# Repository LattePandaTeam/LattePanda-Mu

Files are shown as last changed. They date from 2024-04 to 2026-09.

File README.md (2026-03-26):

# LattePanda Mu Carrier Development Resources

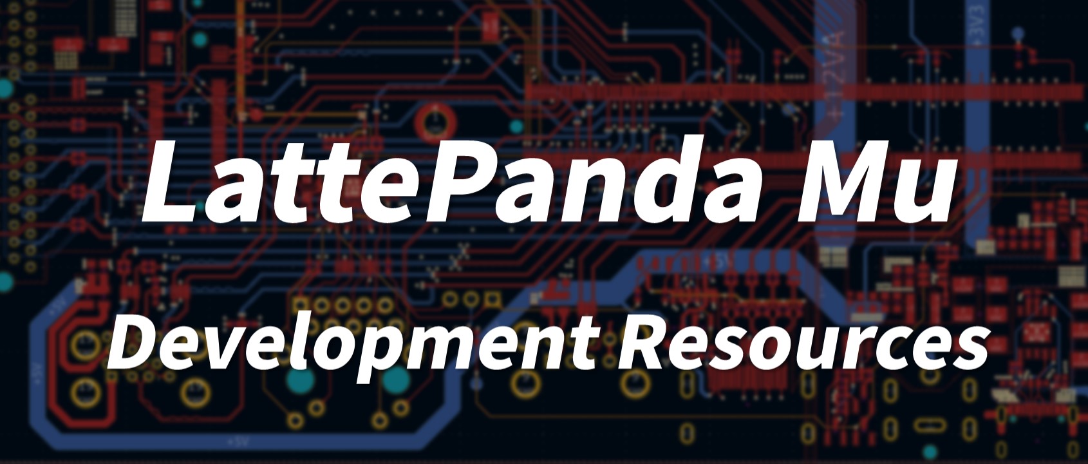
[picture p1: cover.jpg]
cover


Welcome to the repository of development resources for the LattePanda Mu. With its extensive array of interfaces, you can craft your very own carrier board. While we have provided several reference designs to spark your creativity, a myriad of exciting possibilities awaits your discovery. This repository will be continuously updated to support the development of your personalized carrier board solutions.

## Documentation

- [**LattePanda Mu Compute Module User Guide**](https://docs.lattepanda.com/content/mu_edition/introduction/)

- [**Carrier Board Hardware Design Guide**](https://docs.lattepanda.com/content/mu_edition/design_guide_foreword/)

- [**Carrier Board User Guide**](https://docs.lattepanda.com/content/mu_edition/lite_carrier/)

- [**LattePanda Website**](https://www.lattepanda.com/)

- [**Join our Discord**](https://discord.gg/RkSvc9g7eU)

## Resource Directory

- **Electricals**: This includes pin descriptions, symbols and footprint libraries, project templates, and example projects.

- **Mechanicals**: This section provides dimensional drawings and 3D models of the LattePanda Mu, its heatsink, and other accessories.

- **Software**: BIOS, firmware, drivers, and other related software resources.

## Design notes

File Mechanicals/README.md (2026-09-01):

# Mechanical Files

Includes 2D drawings and 3D models of the LattePanda Mu compute module, related accessories, and official carrier boards for structural design purposes.

The STEP format models are large in size, hence they are compressed using 7-Zip. Please use [7-Zip](https://www.7-zip.org/) or another compatible software to extract the `.7z` files before use.

## Files

- [**LattePanda_Mu_Dimension_Drawing.pdf**](./LattePanda_Mu_Dimension_Drawing.pdf): LattePanda Mu Dimensional Drawing, PDF format

- [**LattePanda_Mu_Dimension_Drawing.dxf**](./LattePanda_Mu_Dimension_Drawing.dxf): LattePanda Mu Dimensional Drawing, DXF format

- [**LattePanda_Mu.step.7z**](./LattePanda_Mu.step.7z): Contains the 3D model of the LattePanda Mu assembled with an active cooler.

- [**LattePanda_Mu_H8.0_Horizontal.step.7z**](./LattePanda_Mu_H8.0_Horizontal.step.7z): Includes the model of LattePanda Mu and the H8.0 horizontal connector, which is the standard mounting method for LattePanda Mu, and can be used directly in PCB design as an enclosure model.

- [**LattePanda_Mu_H4.0_Horizontal.step.7z**](./LattePanda_Mu_H4.0_Horizontal.step.7z): Includes the model of LattePanda Mu and the H4.0 horizontal connector, and can be used directly in PCB design as an enclosure model.

- [**FIT0982-Thin-Heatsink.step.7z**](./FIT0982-Thin-Heatsink.step.7z): Thin heatsink only, without Mu module.

- [**FIT0989-Fanless-Heatsink.step.7z**](./FIT0989-Fanless-Heatsink.step.7z): Fanless heatsink only, without Mu module.

- [**FIT0981_Active_cooler.STEP**](./FIT0981_Active_cooler.STEP): Active cooler only, without Mu module.

- [**Carrier-Boards**](./Carrier-Boards/): Mechanical files for various official carrier boards.

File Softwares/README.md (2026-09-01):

# Software Resources

Within this repository, you will find a range of software resources specifically related to the LattePanda Mu, including BIOS updates, firmware, and a variety of drivers.

For BIOS firmware specific to carrier boards, refer to the respective carrier board documentation or [carrier-board branch](./BIOS/Carrier-Boards) for more details.

## Resource Categories

- **BIOS**: Contains stable and beta BIOS updates officially supported, as well as related tools.

- **Drivers**: Drivers and related descriptions.

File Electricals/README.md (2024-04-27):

# Electronic Design Resources

## Files

- Examples: Sample projects

- Libraries: Symbol and footprint libraries for LattePanda Mu

- Pinouts: All pin definitions for LattePanda Mu

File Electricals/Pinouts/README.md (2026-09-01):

# Pinouts

All pin definitions for LattePanda Mu(N100/N305 Processor).

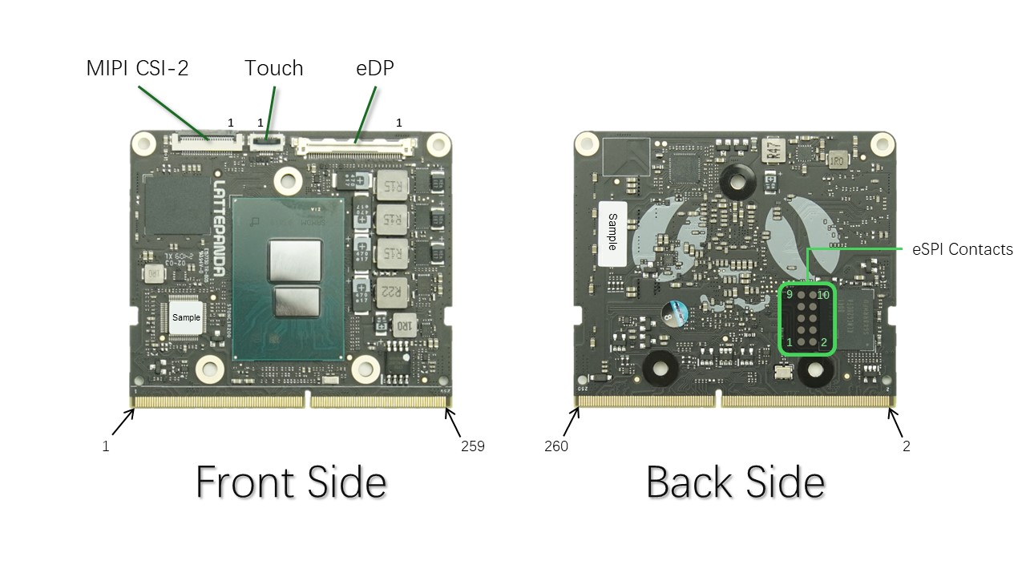
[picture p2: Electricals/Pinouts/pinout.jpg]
pinout


## Edge Connector Pinout

The edge_connector of LattePanda Mu is designed for DDR4 260P SODIMM. But this pin table is too long, so we put it in a separate .xlsx file.

- [LattePanda Mu Edge Connector Pinout](./LattePanda_Mu_Edge_Connector_Pinout.xlsx)

⚠️ Note:  
Due to the large number of functionally multiplexing pins, you should check the [BIOS functionality documentation](../../Softwares/BIOS/) before starting your design. Do not design directly from the pin definition documentation here.

## Edge Connector Pinout Comparison

LattePanda Mu and LattePanda Mu Ultra use the same edge connector, but their pin definitions are slightly different.

To facilitate your comparison and evaluation, we have provided a pin comparison document for both models.

- [LattePanda_Mu_and_Mu_Ultra_Pinout_Comparison](https://github.com/LattePandaTeam/LattePanda-Mu-Ultra/tree/main/Electricals/Pinouts/LattePanda_Mu_and_Mu_Ultra_Pinout_Comparison.xlsx)

## eDP

I-PEX 20455-040E

| Number | Name | Type | Description | Note |
|---|---|:----:|---|---|
| 1 | NC | | | |
| 2 | GND | | | |
| 3 | DDIA_TX3- | O | Lane 3 (-) | |
| 4 | DDIA_TX3+ | O | Lane 3 (+) | |
| 5 | GND | | | |
| 6 | DDIA_TX2- | O | Lane 2 (-) | |
| 7 | DDIA_TX2+ | O | Lane 2 (+) | |
| 8 | GND | | | |
| 9 | DDIA_TX1- | O | Lane 1 (-) | |
| 10 | DDIA_TX1+ | O | Lane 1 (+) | |
| 11 | GND | | | |
| 12 | DDIA_TX0- | O | Lane 0 (-) | |
| 13 | DDIA_TX0+ | O | Lane 0 (+) | |
| 14 | GND | | | |
| 15 | DDIA_AUX+ | O | Auxiliary channel (+) | |
| 16 | DDIA_AUX- | O | Auxiliary channel (-) | |
| 17 | GND | | | |
| 18 | LCD_VCC | | LCD Power Supplies | |
| 19 | LCD_VCC | | LCD Power Supplies | |
| 20 | LCD_VCC | | LCD Power Supplies | |
| 21 | LCD_VCC | | LCD Power Supplies | |
| 22 | Selftest  | O | Default Grounding | |
| 23 | GND | | | |
| 24 | GND | | | |
| 25 | GND | | | |
| 26 | GND | | | |
| 27 | HPD | I | Plug Detection | SoC GPP_E14 |
| 28 | GND | | | |
| 29 | GND | | | |
| 30 | GND | | | |
| 31 | GND | | | |
| 32 | BL_EN | O | Backlight enable | SoC eDP_BKLTEN  |
| 33 | BL_PWM | O | Backlight PWM dimming | SoC eDP_BKLTCTL |
| 34 | NC | | | |
| 35 | NC | | | |
| 36 | BL_PWR | | Backlight Power Supplies | |
| 37 | BL_PWR | | Backlight Power Supplies | |
| 38 | BL_PWR | | Backlight Power Supplies | |
| 39 | BL_PWR | | Backlight Power Supplies | |
| 40 | NC | | | |

- **LCD_VCC**: +3.3V
- **BL_PWR**: Same as LattePanda Mu's power input voltage
- **Selftest**: Factory test pin, ground by default

## Touch

Clamshell 6P 0.5mm FFC/FPC Connector

| Number | Name | Type | Description | Note |
|---|---|:----:|---|---|
| 1 | I2C0_SCL | O | I2C Bus | SoC GPP_H5  |
| 2 | I2C0_SDA | I/O  | I2C Bus | SoC GPP_H4  |
| 3 | GND | | | |
| 4 | TOUCH_RST# | O | Touch panel reset | SoC GPP_E13 |
| 5 | TOUCH_INT  | I | Touch event interrupt | SoC GPP_E17 |
| 6 | +3.3V | | Touch panel power | |

## MIPI CSI-2

Clamshell 22P 0.5mm FFC/FPC Connector

| Number | Name | Type | Description | Note |
|---|---|:----:|---|---|
| 1 | GND | | | |
| 2 | CSI_B_D0- | I | MIPI Data Lane 0  | |
| 3 | CSI_B_D0+ | I | MIPI Data Lane 0  | |
| 4 | GND | | | |
| 5 | CSI_B_D1- | I | MIPI Data Lane 1  | |
| 6 | CSI_B_D1+ | I | MIPI Data Lane 1  | |
| 7 | GND | | | |
| 8 | CSI_B_CK- | I | MIPI Clock | |
| 9 | CSI_B_CK+ | I | MIPI Clock | |
| 10 | GND | | | |
| 11 | CSI_B_D2- | I | MIPI Data Lane 2  | |
| 12 | CSI_B_D2+ | I | MIPI Data Lane 2  | |
| 13 | GND | | | |
| 14 | CSI_B_D3- | I | MIPI Data Lane 3  | |
| 15 | CSI_B_D3+ | I | MIPI Data Lane 3  | |
| 16 | GND | | | |
| 17 | CAM_RST | O | Camera reset | SoC GPP_A21 |
| 18 | CAM_MCLK  | O | Camera main clock | SoC GPP_D4  |
| 19 | GND | | | |
| 20 | I2C1_SCL  | O | I2C bus | SoC GPP_H7  |
| 21 | I2C1_SDA  | I/O  | I2C bus | SoC GPP_H6  |
| 22 | +3.3V | | Camera power | |

## eSPI Contacts

2.54mm Pitch Contacts

| Name | PIN | PIN | Name |
|---|:---:|:---:|---|
| ESPI_IO0 | 9 | 10  | GND |
| ESPI_IO1 | 7 | 8 | NC |
| ESPI_IO2 | 5 | 6 | ESPI_RESET# |
| ESPI_IO3 | 3 | 4 | ESPI_CS0# |
| ESPI_CLK | 1 | 2 | +1.8V |

Contacts on eSPI bus for SoC to communicate with SuperIO, can be used to connect diagnostic card (untested).

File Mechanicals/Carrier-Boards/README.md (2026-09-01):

# Mechanical Files for Various Carrier Boards

Drawings and models of various official carrier boards for structural design use.

## Files

- [**DFR1141_Full_EVA_Carrier_Board_for_LattePanda_Mu.zip**](./DFR1141_Full_EVA_Carrier_Board_for_LattePanda_Mu.zip) 3D model of DFR1141 Full EVA Carrier Board, STEP format, without Mu module.
- [**DFR1142_Lite_Carrier_for_LattePanda Mu(V2.0.1).zip**](./DFR1142_Lite_Carrier_for_LattePanda_Mu(V2.0.1).zip): 3D model of DFR1142 Lite Carrier Board V2, STEP format, without Mu module.
- [**DFR1293_Mini_Carrier_Board_for_LattePanda_Mu_and_Mu_Ultra.zip**](./DFR1293_Mini_Carrier_Board_for_LattePanda_Mu_and_Mu_Ultra.zip)  Contains dimension drawings (PDF and DXF formats) and a 3D model (STEP format) of the DFR1293 Mini Carrier Board, without the Mu/Mu Ultra module.

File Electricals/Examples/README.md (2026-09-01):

# Carrier Board Sample Projects

LattePanda Mu carrier board sample projects for engineers' reference, designed with KiCAD. Please open with KiCAD version 9.0 or higher.

It's recommended to start your design  by referring to the *\[DFR1142\] Lite Carrier for LattePanda Mu(V2)*.

- [Carrier Board Design Guide for LattePanda Mu](https://docs.lattepanda.com/content/mu_edition/design_guide_foreword/)

## Project Files

- **\[DFR1141\] Full EVA Carrier for LattePanda Mu**: The evaluation carrier board that includes nearly all features of the LattePanda Mu, designed to ITX motherboard dimensions, suitable for professional developers.

- **\[DFR1142\] Lite Carrier for LattePanda Mu**: The lite carrier board that includes essential interfaces such as HDMI, USB, PCIe, designed to 3.5-inch embedded motherboard dimensions.

- **\[DFR1142\] Lite Carrier for LattePanda Mu(V2)**: The upgraded version of DFR1142 Lite Carrier. Optimized for evaluation use and small-batch deployment.
  - **Auto Power-On Support:** The system can boots automatically upon receiving power.
  - **New MX1.25-10P Connector:** Designed for compatibility with the DFR1247 LattePanda Smart UPS expansion board.
  - **Side-Mounted Buttons:** Power and Reset buttons have been changed to a side-mounted vertical design to accommodate protective cases better.
  - **External Control Headers:** Added pin headers for external power control and status indication.
  - **Sleep Indicator:** Added a dedicated LED for sleep mode status.
  - **BIOS Flash Chip Footprint:** Added a footprint for a carrier board BIOS flash chip (not soldered by default) for advanced customization.

- **\[DFR1144\] GPU Carrier for LattePanda Mu**: The GPU carrier board features six video output ports, supports Type A/B MXM standard graphics cards, and adopts the 3.5-inch embedded motherboard form factor. It is suitable for local AI inference or multi-screen display matrix applications.

- **\[DFR1293\] Mini Carrier for LattePanda Mu \\ Mu Ultra**: a compact, highly expandable carrier board compatible with the LattePanda Mu and LattePanda Mu Ultra compute module. It integrates commonly used ports such as two full-featured Type-C, 2.5G Ethernet, USB 3.2 Gen2, OCuLink, M.2 M Key, M.2 E Key, HDMI, and GPIO. 

## Compatibility List

Compatibility varies between different compute modules and different carrier boards. Please visit the [**Carrier Board Docs**](https://docs.lattepanda.com/content/mu_edition/module_carrier_compatibility/) for the compatibility list.

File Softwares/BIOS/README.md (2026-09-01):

# BIOS

This repository includes official releases and beta versions of BIOS for various branches, as well as related tools.

- ⚠ Generally, you should only upgrade the BIOS of the same branch. Cross-branch upgrades should only be performed when testing different BIOS features.
- ⚠ Upgrading the BIOS across different branches may invalidate the Secure Boot keys.
- ⚠ Upgrading to the incorrect BIOS branch may result in some functions of the carrier board not working properly.
- ⚠ BIOS files under `Carrier-Boards` are designed exclusively for the specific carrier boards. Do NOT flash them onto a LattePanda Mu paired with any other carrier board or no carrier board.

------

## Naming Rule

### New Naming Scheme (2025-12 and later)

**Format**
`S70NC1R200-[Memory]-[Version][-Variant].bin`

- **S70NC1R200**: Platform identifier (LattePanda Mu N100/N305)
- **Memory**:
  - `8G` = 8GB RAM
  - `16G` = 16GB RAM
- **Version**:
  - `A`, `B`, `C`... (incremented alphabetically for each new release)
- **Variant** (optional):
  - *(no suffix)* = Default (PCIe)
  - `SATA` = SATA branch

**Examples**

- `S70NC1R200-8G-A.bin` → 8GB, Default (PCIe)
- `S70NC1R200-16G-A-SATA.bin` → 16GB, SATA

**Notes**

- New scheme is simplified and user-oriented.
- **All subsequent updates will follow this naming convention.**

### Legacy Naming Scheme (2024 Initial Release)

**Format**
`LP-BS-S70NC1R200-[Rank]-[Version][-Variant].bin`

- **LP**: LattePanda
- **BS**: BIOS
- **S70NC1R200**: Platform identifier(LattePanda Mu N100/N305)
- **Rank**:
  - `SR` = Single Rank (corresponds to 8GB models)
  - `DR` = Dual Rank (corresponds to 16GB models)
- **Version**:
  - `A`, `B`
- **Variant**:
  - *(no suffix)* = Default (PCIe)
  - `SATA` = SATA branch

**Example**

- `LP-BS-S70NC1R200-SR-B.bin` → 8GB, Default (PCIe)

- `LP-BS-S70NC1R200-DR-B-SATA.bin` → 16GB, SATA

### Mapping: Legacy → New Naming

- `SR` → `8G`
- `DR` → `16G`

**Examples**

- `LP-BS-S70NC1R200-SR-B.bin` → `S70NC1R200-8G-A.bin` (newer)
- `LP-BS-S70NC1R200-DR-B-SATA.bin` → `S70NC1R200-16G-A-SATA.bin` (newer)

------

## Folder Description

- **Beta**: Beta version BIOS, not specific to any branch, intended for professional developers to assess new features.
- **DFLT**: Default version BIOS, which is the BIOS branch that comes pre-installed on the LattePanda Mu.
- **SATA**: A BIOS branch that provides SATA interface signal.
- **Carrier-Boards**: BIOS branches dedicated to specific carrier boards. Flash only the BIOS matching your carrier board.
- **Tools**: Tools for BIOS maintenance.

------

## Release Timeline

```text
    2024-06/07                  2025-12                    2026-06
        │                          │                          |
        ●──────────────────────────●──────────────────────────●
        │                          │                          |
[Initial Release]           [Second Release]          [Current Recommended]
    DFLT,SATA                  DFLT,SATA                  DFLT,SATA 
```

For specific model compatibility and functional changes, please refer to the `BOS Release Notes` located in each branch's folder.

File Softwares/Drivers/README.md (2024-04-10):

# Drivers

This repository contains only the LattePanda Mu drivers. For drivers related to the carrier board, please refer to the carrier board documentation.

## Windows 10/11

After installing Windows, the system will automatically connect to the internet to download driver updates. If it is unable to access the Windows Update service, or if there are missing drivers after the automatic updates, you can download the offline driver package here.

| Name | Version | Size | Download |
|---|---|---|---|
| Intel Chipset Driver | 10.1.19376.8374 | 2.72 MB | [⬇️](./Chipset_10.1.19376.8374.zip) |
| Intel Iris Xe Graphics Driver | Latest | N/A | [⬇️](https://www.intel.com/content/www/us/en/download/785597/)[^1] |
| intel Serial IO Driver | 30.100.2229.4 | 353 KB  | [⬇️](./SerialIO_30.100.2229.4.zip) |
| intel HID Event Filter Driver | 2.2.1.386 | 46.6 KB | [⬇️](./HID_2.2.1.386.zip) |
| Intel Management Engine Interface Driver | 2306.4.10.0 | 20.5 MB | [⬇️](./MEI_2306.4.10.0.zip) |
| Intel GNA Scoring Accelerator Driver | 03.00.00.1457 | 54 KB | [⬇️](./GNA_03.00.00.1457.zip) |
| Intel Integrated Sensor Solution Driver | 3.1.0.4589 | 2.73 MB | [⬇️](./ISH_3.1.0.4589.zip) |
| TouchPanel Driver | 1.3.2.0 | 67.5 KB | [⬇️](./TouchPanel_1.3.2.0.zip) |

[^1]: Download from intel official website

## Linux

Linux drivers are generally provided by the distribution through kernel and kernel module updates. Please use a newer kernel version to ensure full driver support.

- Minimum kernel version: 5.18
- Recommended kernel version: 6.1 or later

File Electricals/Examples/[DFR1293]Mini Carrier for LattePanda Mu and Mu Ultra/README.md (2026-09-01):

# \[DFR1293\]Mini Carrier for LattePanda Mu and LattePanda Mu Ultra

Currently, only a PDF schematic is available for reference.

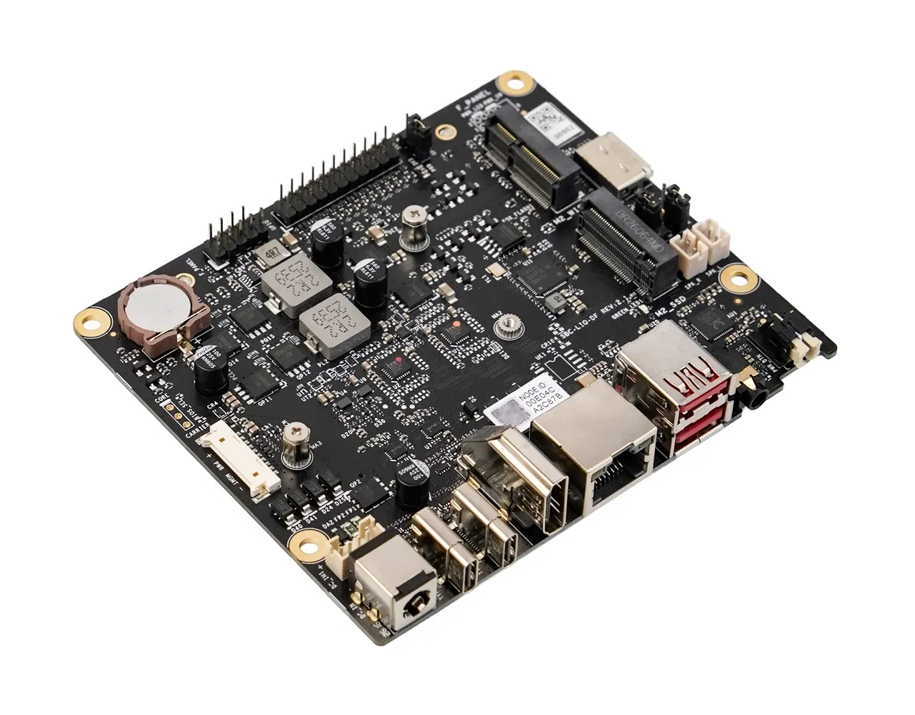
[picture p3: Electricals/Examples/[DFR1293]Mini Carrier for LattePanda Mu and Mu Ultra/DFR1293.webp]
DFR1293


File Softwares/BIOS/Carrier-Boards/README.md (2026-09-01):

# Carrier Board BIOS

This repository provides BIOS firmware specifically adapted for specific carrier boards.

- **[DFR1293] Mini-Carrier**
    - Make the LattePanda Mu compatible with the Mini Carrier.
    - The LattePanda Mu Ultra’s default firmware already works perfectly.

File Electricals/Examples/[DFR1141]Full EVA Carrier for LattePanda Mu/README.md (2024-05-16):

# \[DFR1141\]Full EVA Carrier for LattePanda Mu

Currently, only a **preview version** of the schematic and Gerber files are available for reference.

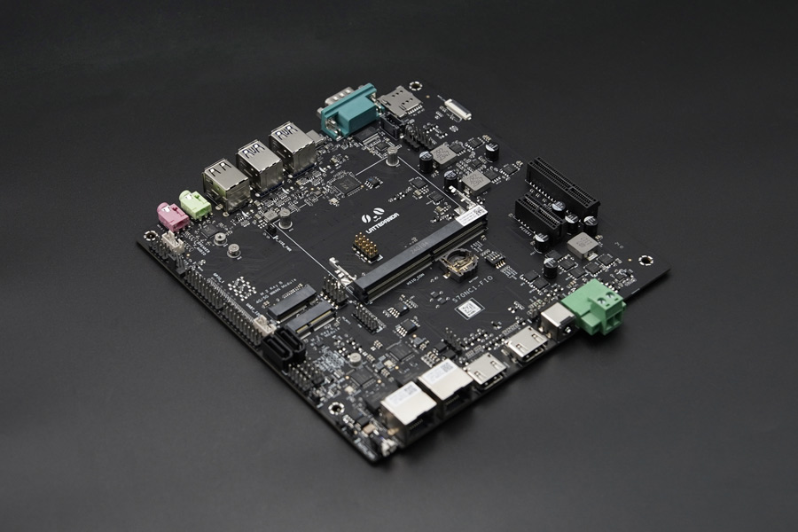
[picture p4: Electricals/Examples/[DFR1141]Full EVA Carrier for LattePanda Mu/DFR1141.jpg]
DFR1141


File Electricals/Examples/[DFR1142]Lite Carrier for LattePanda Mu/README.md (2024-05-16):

# DFR1142 Lite Carrier for LattePanda Mu

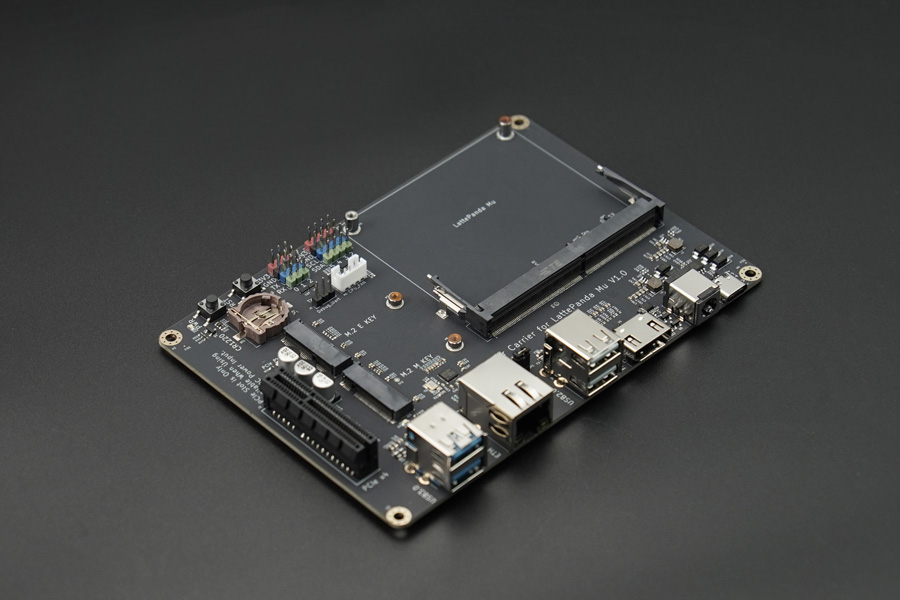
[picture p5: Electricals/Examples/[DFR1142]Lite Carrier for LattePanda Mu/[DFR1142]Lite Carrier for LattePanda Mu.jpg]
DFR1142


## Specification

### Power Input

- USB Type-C PD: 15V (Max 3A)
- DC 5.5x2.5mm: 12~20V (Max 10A)

### Internal Interfaces

- PCIe 3.0 x4 slot (only available when using 12V power supply)
- M.2 M Key 2230 (PCIe 3.0 x1)
- M.2 E Key 2230 (PCIe 3.0 x1, USB2.0)
- RTC battery socket (CR1220 3V)
- CPU fan socket
- Gravity-4P UART
- Gravity-4P I2C

### External Interfaces

- USB 3.2 10Gbps x2
- Gigabit Ethernet
- USB 2.0 x2
- HDMI 2.0

### Dimension

3.5 inches, 146mm×102mm

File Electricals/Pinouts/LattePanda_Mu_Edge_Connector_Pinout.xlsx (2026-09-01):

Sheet: Overview
Speed: Indicates the operating speed of the signal pin. "Low" denotes low-speed signals requiring only standard PCB routing. "High" denotes high-speed signals which mandate impedance matching in the PCB design.
IO Level: For multiplexed pins, the IO voltage level may vary depending on the configured function. This document specifies the maximum voltage level supported by the pin.
Note:
This document is applicable only to LattePanda Mu compute modules equipped with Intel N100 and N305 processors.
Due to the large number of pins that serve multiple functions, please consult the BIOS functionality documentation before beginning your design.
https://github.com/LattePandaTeam/LattePanda-Mu/tree/main/Softwares/BIOS
Pinout Description Page
https://github.com/LattePandaTeam/LattePanda-Mu/tree/main/Electricals/Pinouts

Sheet: Front
Pin | Signal Name | Direction | IO Level | Description | Speed | Notes
1 | PWR_SW# | I | 3.3V | System Power Switch | Low | Active LOW; Internally 10K Pulled Up
3 | RST_SW# | I | 3.3V | System Reset Switch | Low | Active LOW; Internally 10K Pulled Up
5 | PSON | O | 3.3V | System Power Supply Status | Low | Output HIGH only when S0(Working); 10K Pull-up to 3.3V (Weak Drive of HIGH output)
7 | SLP_S4 | O | 3.3V | System Status | Low | Output HIGH only when S0(Working) and S3(Sleeping)
9 | TSENSE | I | 3.3V | NTC Temperature Sensor | Low
11 | GND | PWR | 0V | Ground | /
13 | HSIO0_TX_P | O | 0.8V | HSIO0 TX Differential Pair | High | External AC Coupling Capacitor Required
15 | HSIO0_TX_N | O | 0.8V | HSIO0 TX Differential Pair | High | External AC Coupling Capacitor Required
17 | GND | PWR | 0V | Ground | /
19 | HSIO1_TX_P | O | 0.8V | HSIO1 TX Differential Pair | High | External AC Coupling Capacitor Required
21 | HSIO1_TX_N | O | 0.8V | HSIO1 TX Differential Pair | High | External AC Coupling Capacitor Required
23 | GND | PWR | 0V | Ground | /
25 | HSIO2_TX_P | O | 0.8V | HSIO2 TX Differential Pair | High | External AC Coupling Capacitor Required
27 | HSIO2_TX_N | O | 0.8V | HSIO2 TX Differential Pair | High | External AC Coupling Capacitor Required
29 | GND | PWR | 0V | Ground | /
31 | HSIO3_TX_P | O | 0.8V | HSIO3 TX Differential Pair | High | External AC Coupling Capacitor Required
33 | HSIO3_TX_N | O | 0.8V | HSIO3 TX Differential Pair | High | External AC Coupling Capacitor Required
35 | GND | PWR | 0V | Ground | /
37 | HSIO8_TX_P | O | 0.8V | HSIO8 TX Differential Pair | High | External AC Coupling Capacitor Required
39 | HSIO8_TX_N | O | 0.8V | HSIO8 TX Differential Pair | High | External AC Coupling Capacitor Required
41 | GND | PWR | 0V | Ground | /
43 | HSIO9_TX_P | O | 0.8V | HSIO9 TX Differential Pair | High | External AC Coupling Capacitor Required
45 | HSIO9_TX_N | O | 0.8V | HSIO9 TX Differential Pair | High | External AC Coupling Capacitor Required
47 | GND | PWR | 0V | Ground | /
49 | HSIO10_TX_P | O | 0.8V | HSIO10 TX Differential Pair | High | External AC Coupling Capacitor Required
51 | HSIO10_TX_N | O | 0.8V | HSIO10 TX Differential Pair | High | External AC Coupling Capacitor Required
53 | GND | PWR | 0V | Ground | /
55 | HSIO11_TX_P | O | 0.8V | HSIO11 TX Differential Pair | High | External AC Coupling Capacitor Required
57 | HSIO11_TX_N | O | 0.8V | HSIO11 TX Differential Pair | High | External AC Coupling Capacitor Required
59 | GND | PWR | 0V | Ground | /
61 | HSIO6_TX_P | O | 0.8V | HSIO6 TX Differential Pair | High | External AC Coupling Capacitor Required
63 | HSIO6_TX_N | O | 0.8V | HSIO6 TX Differential Pair | High | External AC Coupling Capacitor Required
65 | GND | PWR | 0V | Ground | /
67 | USB2_P1_N | I/O | 3.3V | USB 2.0 Port 1 Differential Pair | High
69 | USB2_P1_P | I/O | 3.3V | USB 2.0 Port 1 Differential Pair | High
71 | GND | PWR | 0V | Ground | /
73 | USB2_P2_N | I/O | 3.3V | USB 2.0 Port 2 Differential Pair | High
75 | USB2_P2_P | I/O | 3.3V | USB 2.0 Port 2 Differential Pair | High
77 | GND | PWR | 0V | Ground | /
79 | USB2_P3_N | I/O | 3.3V | USB 2.0 Port 3 Differential Pair | High
81 | USB2_P3_P | I/O | 3.3V | USB 2.0 Port 3 Differential Pair | High
83 | GND | PWR | 0V | Ground | /
85 | REFCLK0_P | O | 0.8V | PCIe Reference Clock 0 Differential Pair | High | 100MHz
87 | REFCLK0_N | O | 0.8V | PCIe Reference Clock 0 Differential Pair | High | 100MHz
89 | GND | PWR | 0V | Ground | /
91 | REFCLK1_P | O | 0.8V | PCIe Reference Clock 1 Differential Pair | High | 100MHz
93 | REFCLK1_N | O | 0.8V | PCIe Reference Clock 1 Differential Pair | High | 100MHz
95 | GND | PWR | 0V | Ground | /
97 | REFCLK2_P | O | 0.8V | PCIe Reference Clock 2 Differential Pair | High | 100MHz
99 | REFCLK2_N | O | 0.8V | PCIe Reference Clock 2 Differential Pair | High | 100MHz
101 | GND | PWR | 0V | Ground | /
103 | PCIE_WAKE# | I | 3.3V | PCIe Wake Request | Low | Pulled LOW to Wake System; Internally 1K Pulled Up
105 | PLT_RST# | O | 3.3V | Platform Reset for PCIe | Low | Output LOW to Reset PCIe Device
107 | GND | PWR | 0V | Ground | /
109 | USB2_P5_N | I/O | 3.3V | USB 2.0 Port 5 Differential Pair | High
111 | USB2_P5_P | I/O | 3.3V | USB 2.0 Port 5 Differential Pair | High
113 | GND | PWR | 0V | Ground | /
115 | VBAT | PWR | 3.0V | RTC Battery Input | /
117 | PROCHOT# | I | 3.3V | (TCC) Overheat Protect | Low | Active LOW; Internally 10K Pulled Up
119 | GPP_E0 | I/O | 3.3V | GPIO | Low | BIOS Default Function:WWAN_PWR_EN
121 | GPP_A12 | I/O | 3.3V | GPIO | Low | BIOS Default Function:CAM_PWR_EN
123 | SATA_LED# | O | 3.3V | SATA HDD Activity Status | Low | Active LOW
125 | PMCALERT# | I | 3.3V | USB Type-C PD Controller / Re-timer Alert | Low | Active LOW; Internally 10K Pulled Up
127 | TPM_IRQ | I | 3.3V | Discrete TPM Interrupt | Low
129 | USB_OC# | I | 3.3V | USB Over Current | Low | Active LOW; Internally 10K Pulled Up
131 | SUSCLK | O | 3.3V | Suspend Clock | Low | 32.768KHz
133 | BIOS_SEL | I | 3.3V | BIOS ROM Select | Low | Internally 100K Pulled Up； HIGH: Integrated ROM; LOW: Carrier ROM
135 | GND | PWR | 0V | Ground | /
137 | UART0_RXD / GPP_H10 | I/O | 3.3V | SoC UART0 RX / GPIO | Low | BIOS Default Function: UART
139 | UART0_TXD / GPP_H11 | I/O | 3.3V | SoC UART0 TX / GPIO | Low | BIOS Default Function: UART
141 | UART1_RXD / GPP_D17 | I/O | 3.3V | SoC UART1 RX / GPIO | Low | BIOS Default Function: UART
143 | UART1_TXD / GPP_D18 | I/O | 3.3V | SoC UART1 TX / GPIO | Low | BIOS Default Function: UART
KEY
145 | SML1_DATA | I/O | 3.3V | SMLink1 Data | Low | Internally 2.2K Pulled Up
147 | SML1_CLK | O | 3.3V | SMLink1 Clock | Low | Internally 2.2K Pulled Up
149 | SML1_ALERT# | I | 3.3V | SMLink1 Alert | Low | Active LOW
151 | GND | PWR | 0V | Ground | /
153 | SPI_IO3 | I/O | 3.3V | SPI Bus for BIOS and dTPM | Low
155 | SPI_CLK | O | 3.3V | SPI Bus for BIOS and dTPM | Low
157 | SPI_CS2# | O | 3.3V | SPI Chip Select for dTPM | Low
159 | SPI_MOSI/SPI_IO0 | I/O | 3.3V | SPI Bus for BIOS and dTPM | Low
161 | SPI_IO2 | I/O | 3.3V | SPI Bus for BIOS and dTPM | Low
163 | SPI_MISO/SPI_IO1 | I/O | 3.3V | SPI Bus for BIOS and dTPM | Low
165 | SPI_CS# | O | 3.3V | SPI Chip Select for BIOS ROM | Low
167 | GND | PWR | 0V | Ground | /
169 | DDIB_CTRL_DATA | I/O | 3.3V | DDIB Control Data | Low | Internally 2.2K Pulled Up
171 | DDIB_CTRL_CLK | O | 3.3V | DDIB Control Clock | Low | Internally 2.2K Pulled Up
173 | TCP1_CTRL_DATA | I/O | 3.3V | TCP1 Control Data | Low | Internally 2.2K Pulled Up
175 | TCP1_CTRL_CLK | O | 3.3V | TCP1 Control Clock | Low | Internally 2.2K Pulled Up
177 | TCP0_CTRL_DATA | I/O | 3.3V | TCP0 Control Data | Low | Internally 2.2K Pulled Up
179 | TCP0_CTRL_CLK | O | 3.3V | TCP0 Control Clock | Low | Internally 2.2K Pulled Up
181 | GND | PWR | 0V | Ground | /
183 | DDIB_HPD | I | 3.3V | DDIB Hot Plug Detect | Low
185 | TCP1_HPD | I | 3.3V | TCP1 Hot Plug Detect | Low
187 | TCP0_HPD | I | 3.3V | TCP0 Hot Plug Detect | Low
189 | GND | PWR | 0V | Ground | /
191 | DDIB_AUX_N | I/O | 0.6V | DDIB DP Auxiliary Channel | Low
193 | DDIB_AUX_P | I/O | 0.6V | DDIB DP Auxiliary Channel | Low
195 | GND | PWR | 0V | Ground | /
197 | DDIB_TX3_N | O | 1.2V | DDIB DP Lane 3 / HDMI TMDS Clock | High | External AC Coupling Capacitor Required
199 | DDIB_TX3_P | O | 1.2V | DDIB DP Lane 3 / HDMI TMDS Clock | High | External AC Coupling Capacitor Required
201 | GND | PWR | 0V | Ground | /
203 | DDIB_TX2_N | O | 1.2V | DDIB DP Lane 2 / HDMI TMDS Data0 | High | External AC Coupling Capacitor Required
205 | DDIB_TX2_P | O | 1.2V | DDIB DP Lane 2 / HDMI TMDS Data0 | High | External AC Coupling Capacitor Required
207 | GND | PWR | 0V | Ground | /
209 | DDIB_TX1_N | O | 1.2V | DDIB DP Lane 1 / HDMI TMDS Data1 | High | External AC Coupling Capacitor Required
211 | DDIB_TX1_P | O | 1.2V | DDIB DP Lane 1 / HDMI TMDS Data1 | High | External AC Coupling Capacitor Required
213 | GND | PWR | 0V | Ground | /
215 | DDIB_TX0_N | O | 1.2V | DDIB DP Lane 0 / HDMI TMDS Data2 | High | External AC Coupling Capacitor Required
217 | DDIB_TX0_P | O | 1.2V | DDIB DP Lane 0 / HDMI TMDS Data2 | High | External AC Coupling Capacitor Required
219 | GND | PWR | 0V | Ground | /
221 | TCP0_AUX_N | I/O | 0.6V | TCP0 DP Auxiliary Channel | Low
223 | TCP0_AUX_P | I/O | 0.6V | TCP0 DP Auxiliary Channel | Low
225 | GND | PWR | 0V | Ground | /
227 | TCP0_TXRX1_N | I/O | 1.2V | TCP0 DP Lane 3 / HDMI TMDS Clock / Type C RX Data Lane 2 | High | External AC Coupling Capacitor Required
229 | TCP0_TXRX1_P | I/O | 1.2V | TCP0 DP Lane 3 / HDMI TMDS Clock / Type C RX Data Lane 2 | High | External AC Coupling Capacitor Required
231 | GND | PWR | 0V | Ground | /
233 | TCP0_TX1_N | O | 1.2V | TCP0 DP Lane 2 / HDMI TMDS Data0 / Type C TX Data Lane 2 | High | External AC Coupling Capacitor Required
235 | TCP0_TX1_P | O | 1.2V | TCP0 DP Lane 2 / HDMI TMDS Data0 / Type C TX Data Lane 2 | High | External AC Coupling Capacitor Required
237 | GND | PWR | 0V | Ground | /
239 | TCP0_TXRX0_N | I/O | 1.2V | TCP0 DP Lane 1 / HDMI TMDS Data1 / Type C RX Data Lane 1 | High | External AC Coupling Capacitor Required
241 | TCP0_TXRX0_P | I/O | 1.2V | TCP0 DP Lane 1 / HDMI TMDS Data1 / Type C RX Data Lane 1 | High | External AC Coupling Capacitor Required
243 | GND | PWR | 0V | Ground | /
245 | TCP0_TX0_N | O | 1.2V | TCP0 DP Lane 0 / HDMI TMDS Data2 / Type C TX Data Lane 1 | High | External AC Coupling Capacitor Required
247 | TCP0_TX0_P | O | 1.2V | TCP0 DP Lane 0 / HDMI TMDS Data2 / Type C TX Data Lane 1 | High | External AC Coupling Capacitor Required
249 | GND | PWR | 0V | Ground | /
251 | VIN | PWR | 9V ~ 20V | Main Power Input | /
253 | VIN | PWR | 9V ~ 20V | Main Power Input | /
255 | VIN | PWR | 9V ~ 20V | Main Power Input | /
257 | VIN | PWR | 9V ~ 20V | Main Power Input | /
259 | VIN | PWR | 9V ~ 20V | Main Power Input | /
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

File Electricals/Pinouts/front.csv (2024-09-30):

Number | Name | Type | Description | Note
1 | PWRBTN# | I | Power button, with integrated pull-up | SIO PANSWH#
3 | RSTBTN# | I | Reset button, with integrated pull-up | SoC SYS_RESET#
5 | SLS_S0 | O | Power status, output high when S0(Working) | SIO PSON#
7 | SLS_S3 | O | Power status, output high when S0(Working), S3(Sleep) | SoC GPD5
9 | TSENSE | I | NTC temperature sensor input | SIO TMPIN2
11 | GND
13 | HSIO0_TX+ | O | Differential signal output, coupling capacitor required
15 | HSIO0_TX- | O | Differential signal output, coupling capacitor required
17 | GND
19 | HSIO1_TX+ | O | Differential signal output, coupling capacitor required
21 | HSIO1_TX- | O | Differential signal output, coupling capacitor required
23 | GND
25 | HSIO2_TX+ | O | Differential signal output, coupling capacitor required
27 | HSIO2_TX- | O | Differential signal output, coupling capacitor required
29 | GND
31 | HSIO3_TX+ | O | Differential signal output, coupling capacitor required
33 | HSIO3_TX- | O | Differential signal output, coupling capacitor required
35 | GND
37 | HSIO8_TX+ | O | Differential signal output, coupling capacitor required
39 | HSIO8_TX- | O | Differential signal output, coupling capacitor required
41 | GND
43 | HSIO9_TX+ | O | Differential signal output, coupling capacitor required
45 | HSIO9_TX- | O | Differential signal output, coupling capacitor required
47 | GND
49 | HSIO10_TX+ | O | Differential signal output, coupling capacitor required
51 | HSIO10_TX- | O | Differential signal output, coupling capacitor required
53 | GND
55 | HSIO11_TX+ | O | Differential signal output, coupling capacitor required
57 | HSIO11_TX- | O | Differential signal output, coupling capacitor required
59 | GND
61 | HSIO6_TX+ | O | Differential signal output, coupling capacitor required
63 | HSIO6_TX- | O | Differential signal output, coupling capacitor required
65 | GND
67 | USB2_P1- | I/O | USB 2.0 differential signal
69 | USB2_P1+ | I/O | USB 2.0 differential signal
71 | GND
73 | USB2_P2- | I/O | USB 2.0 differential signal
75 | USB2_P2+ | I/O | USB 2.0 differential signal
77 | GND
79 | USB2_P3- | I/O | USB 2.0 differential signal
81 | USB2_P3+ | I/O | USB 2.0 differential signal
83 | GND
85 | REFCLK0+ | O | PCIe reference clock
87 | REFCLK0- | O | PCIe reference clock
89 | GND
91 | REFCLK1+ | O | PCIe reference clock
93 | REFCLK1- | O | PCIe reference clock
95 | GND
97 | REFCLK2+ | O | PCIe reference clock
99 | REFCLK2- | O | PCIe reference clock
101 | GND
103 | WAKE# | I | Wake Mu when pull-down | SoC WAKE#
105 | PLTRST# | O | Platform reset signal | SoC GPP_B13
107 | GND
109 | USB2_P5- | I/O | USB 2.0 differential signal
111 | USB2_P5+ | I/O | USB 2.0 differential signal
113 | GND
115 | VBAT |  | RTC battery input | SoC VCCRTC
117 | PROCHOT# | I | Overheat protect when pull-down | SoC PROCHOT#
119 | GPP_E0 | I/O | GPIO, functions defined by BIOS
121 | GPP_A12 | I/O | GPIO, functions defined by BIOS
123 | GPP_B14 | I/O | GPIO, functions defined by BIOS
125 | GPP_B11 | I/O | GPIO, functions defined by BIOS
127 | TPM_IRQ | I | discrete TPM interrupt | SoC GPP_B4
129 | USB_OC# | I | USB over current signal | SoC GPP_A16
131 | SUSCLK | O | 32.768kHz clock output | SoC GPD8
133 | BIOS_SEL# | I | BIOS select: pull-up: integrated ROM; pull-down: carrier ROM
135 | GND
137 | UART0_RXD | I | SoC UART0 receiver | SoC GPP_H10
139 | UART0_TXD | O | SoC UART0 transmitter | SoC GPP_H11
141 | UART1_RXD | I | SoC UART1 receiver | SoC GPP_D17
143 | UART1_TXD | O | SoC UART1 transmitter | SoC GPP_D18
KEY | KEY | KEY | KEY
145 | SML1_DATA | I/O | SMLink1 data | SoC GPP_C7
147 | SML1_CLK | O | SMLink1 clock | SoC GPP_C6
149 | SML1_ALERT# | I | SMLink1 alert | SoC GPP_B23
151 | GND
153 | SPI_IO3 | I/O | SPI interface, BIOS and dTPM specific
155 | SPI_CLK | O | SPI interface, BIOS and dTPM specific
157 | SPI_CS2# | O | SPI chip select, dTPM specific
159 | SPI_MOSI/SPI_IO0 | I/O | SPI interface, BIOS and dTPM specific
161 | SPI_IO2 | I/O | SPI interface, BIOS and dTPM specific
163 | SPI_MISO/SPI_IO1 | I/O | SPI interface, BIOS and dTPM specific
165 | SPI_CS# | O | SPI chip select, BIOS ROM specific
167 | GND
169 | DDIB_DDC_SDA | I/O | DDIB HDMI display data channel data | SoC GPP_H17
171 | DDIB_DDC_SCL | O | DDIB HDMI display data channel clock | SoC GPP_H15
173 | TCP1_DDC_SDA | I/O | TCP1 HDMI display data channel data | SoC GPP_E21
175 | TCP1_DDC_SCL | O | TCP1 HDMI display data channel clock | SoC GPP_E20
177 | TCP0_DDC_SDA | I/O | TCP0 HDMI display data channel data | SoC GPP_E19
179 | TCP0_DDC_SCL | O | TCP0 HDMI display data channel clock | SoC GPP_E18
181 | GND
183 | DDIB_HPD | I | DDIB hot plug detect | SoC GPP_A18
185 | TCP1_HPD | I | TCP1 hot plug detect | SoC GPP_A20
187 | TCP0_HPD | I | TCP0 hot plug detect | SoC GPP_A19
189 | GND
191 | DDIB_AUX- | I/O | DDIB DP Auxiliary channel
193 | DDIB_AUX+ | I/O | DDIB DP Auxiliary channel
195 | GND
197 | DDIB_TX3- | O | DDIB DP Lane 3/HDMI TMDS Clock
199 | DDIB_TX3+ | O | DDIB DP Lane 3/HDMI TMDS Clock
201 | GND
203 | DDIB_TX2- | O | DDIB DP Lane 2/HDMI TMDS Data0
205 | DDIB_TX2+ | O | DDIB DP Lane 2/HDMI TMDS Data0
207 | GND
209 | DDIB_TX1- | O | DDIB DP Lane 1/HDMI TMDS Data1
211 | DDIB_TX1+ | O | DDIB DP Lane 1/HDMI TMDS Data1
213 | GND
215 | DDIB_TX0- | O | DDIB DP Lane 0/HDMI TMDS Data2
217 | DDIB_TX0+ | O | DDIB DP Lane 0/HDMI TMDS Data2
219 | GND
221 | TCP0_AUX- | I/O | TCP0 DP Auxiliary channel
223 | TCP0_AUX+ | I/O | TCP0 DP Auxiliary channel
225 | GND
227 | TCP0_TXRX1- | O | TCP0 DP Lane 3/HDMI TMDS Clock
229 | TCP0_TXRX1+ | O | TCP0 DP Lane 3/HDMI TMDS Clock
231 | GND
233 | TCP0_TX1- | O | TCP0 DP Lane 2/HDMI TMDS Data0
235 | TCP0_TX1+ | O | TCP0 DP Lane 2/HDMI TMDS Data0
237 | GND
239 | TCP0_TXRX0- | O | TCP0 DP Lane 1/HDMI TMDS Data1
241 | TCP0_TXRX0+ | O | TCP0 DP Lane 1/HDMI TMDS Data1
243 | GND
245 | TCP0_TX0- | O | TCP0 DP Lane 0/HDMI TMDS Data2
247 | TCP0_TX0+ | O | TCP0 DP Lane 0/HDMI TMDS Data2
249 | GND
251 | VIN |  | Main power input 9~20V
253 | VIN |  | Main power input 9~20V
255 | VIN |  | Main power input 9~20V
257 | VIN |  | Main power input 9~20V
259 | VIN |  | Main power input 9~20V

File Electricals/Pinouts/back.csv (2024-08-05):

Number | Name | Type | Description | Note
2 | FAN1_PWM | O | CPU fan PWM output | SIO GP51
4 | FAN1_TAC | I | CPU fan tachometer input | SIO GP52
6 | TAN2_PWM | O | System fan PWM out | SIO GP36
8 | FAN2_TAC | I | System fan tachometer input | SIO GP37
10 | SIO_UART_TX | O | SuperIO UART transmitter | SIO JP3
12 | SIO_UART_RX | I | SuperIO UART receiver | SIO GP41
14 | GND
16 | HSIO0_RX+ | I | Differential signal input
18 | HSIO0_RX- | I | Differential signal input
20 | GND
22 | HSIO1_RX+ | I | Differential signal input
24 | HSIO1_RX- | I | Differential signal input
26 | GND
28 | HSIO2_RX+ | I | Differential signal input
30 | HSIO2_RX- | I | Differential signal input
32 | GND
34 | HSIO3_RX+ | I | Differential signal input
36 | HSIO3_RX- | I | Differential signal input
38 | GND
40 | HSIO8_RX+ | I | Differential signal input
42 | HSIO8_RX- | I | Differential signal input
44 | GND
46 | HSIO9_RX+ | I | Differential signal input
48 | HSIO9_RX- | I | Differential signal input
50 | GND
52 | HSIO10_RX+ | I | Differential signal input
54 | HSIO10_RX- | I | Differential signal input
56 | GND
58 | HSIO11_RX+ | I | Differential signal input
60 | HSIO11_RX- | I | Differential signal input
62 | GND
64 | HSIO6_RX+ | I | Differential signal input
66 | HSIO6_RX- | I | Differential signal input
68 | GND
70 | USB2_P4 | I/O | USB 2.0 differential signal
72 | USB2_N4 | I/O | USB 2.0 differential signal
74 | GND
76 | USB2_P7 | I/O | USB 2.0 differential signal
78 | USB2_N7 | I/O | USB 2.0 differential signal
80 | GND
82 | USB2_P8 | I/O | USB 2.0 differential signal
84 | USB2_N8 | I/O | USB 2.0 differential signal
86 | GND
88 | REFCLK3+ | O | PCIe reference clock
90 | REFCLK3- | O | PCIe reference clock
92 | GND
94 | REFCLK4+ | O | PCIe reference clock
96 | REFCLK4- | O | PCIe reference clock
98 | GND
100 | PCIECLK_REQ3# | I | REFCLK3 clock request function | SoC GPP_D8
102 | PCIECLK_REQ4# | I | REFCLK4 clock request function | SoC GPP_H19
104 | SMB_ALERT# | I | SMBus alert interrupt | SoC GPP_C2
106 | SMB_CLK | O | SMBus clock | SoC GPP_C0
108 | SMB_DATA | I/O | SMBus data | SoC GPP_C1
110 | GND
112 | USB2_P6 | I/O | USB 2.0 differential signal
114 | USB2_N6 | I/O | USB 2.0 differential signal
116 | GND
118 | GPP_F16 | I/O | GPIO, functions defined by BIOS
120 | GPP_F15 | I/O | GPIO, functions defined by BIOS
122 | GPP_F14 | I/O | GPIO, functions defined by BIOS
124 | GPP_F13 | I/O | GPIO, functions defined by BIOS
126 | GPP_F12 | I/O | GPIO, functions defined by BIOS
128 | GPP_D0 | I/O | GPIO, functions defined by BIOS
130 | GPP_D1 | I/O | GPIO, functions defined by BIOS
132 | GPP_D2 | I/O | GPIO, functions defined by BIOS
134 | GPP_D3 | I/O | GPIO, functions defined by BIOS
136 | GND
138 | SOC_UART2_TXD | O | SoC UART2 transmitter | SoC GPP_F2
140 | SOC_UART2_RXD | I | SoC UART2 receiver | SoC GPP_F1
142 | I2C5_SCL | O | I2C5 clock | SoC GPP_B17
144 | I2C5_SDA | I/O | I2C5 data | SoC GPP_B16
KEY | KEY | KEY | KEY
146 | I2C4_SCL | O | I2C4 clock | SoC GPP_H9
148 | I2C4_SDA | I/O | I2C4 data | SoC GPP_H8
150 | I2C3_SCL | O | I2C3 clock | SoC GPP_B8
152 | I2C3_SDA | I/O | I2C3 data | SoC GPP_B7
154 | I2C2_SCL | O | I2C2 clock | SoC GPP_B6
156 | I2C2_SDA | I/O | I2C2 data | SoC GPP_B5
158 | GND
160 | I2S_MCLK | O | I2S main clock | SoC GPP_D19
162 | I2S_SCLK | O | I2S bit clock | SoC GPP_S0
164 | I2S_SFRM | O | I2S word clock | SoC GPP_S1
166 | I2S_TXD | O | I2S serial data transmitter | SoC GPP_S2
168 | I2S_RXD | I | I2S serial data receiver | SoC GPP_S3
170 | GND
172 | HDA_RST | O | HD Audio reset | SoC GPP_R4
174 | HDA_BCLK | O | HD Audio bit clock | SoC GPP_R0
176 | HDA_SYNC | O | HD Audio sync | SoC GPP_R1
178 | HDA_SDOUT | O | HD Audio serial data out | SoC GPP_R2
180 | HDA_SDIN | I | HD Audio serial data in | SoC GPP_R3
182 | GND
184 | CSI_D_CK+ | I | MIPI CSI-2 Port D Clock
186 | CSI_D_CK- | I | MIPI CSI-2 Port D Clock
188 | GND
190 | CSI_D_D1+ | I | MIPI CSI-2 Port D Data Lane 1
192 | CSI_D_D1- | I | MIPI CSI-2 Port D Data Lane 1
194 | GND
196 | CSI_D_D0+ | I | MIPI CSI-2 Port D Data Lane 0
198 | CSI_D_D0- | I | MIPI CSI-2 Port D Data Lane 0
200 | GND
202 | CSI_C_CK+ | I | MIPI CSI-2 Port C Clock
204 | CSI_C_CK- | I | MIPI CSI-2 Port C Clock
206 | GND
208 | CSI_C_D1+ | I | MIPI CSI-2 Port C Data Lane 1
210 | CSI_C_D1- | I | MIPI CSI-2 Port C Data Lane 1
212 | GND
214 | CSI_C_D0+ | I | MIPI CSI-2 Port C Data Lane 0
216 | CSI_C_D0- | I | MIPI CSI-2 Port C Data Lane 0
218 | GND
220 | TCP1_TXP0 | O | TCP1 DP Lane 0/HDMI TMDS Data2
222 | TCP1_TXN0 | O | TCP1 DP Lane 0/HDMI TMDS Data2
224 | GND
226 | TCP1_TXRXP0 | O | TCP1 DP Lane 1/HDMI TMDS Data1
228 | TCP1_TXRXN0 | O | TCP1 DP Lane 1/HDMI TMDS Data1
230 | GND
232 | TCP1_TXP1 | O | TCP1 DP Lane 2/HDMI TMDS Data0
234 | TCP1_TXN1 | O | TCP1 DP Lane 2/HDMI TMDS Data0
236 | GND
238 | TCP1_TXRXP1 | O | TCP1 DP Lane 3/HDMI TMDS Clock
240 | TCP1_TXRXN1 | O | TCP1 DP Lane 3/HDMI TMDS Clock
242 | GND
244 | TCP1_AUX_P | I/O | TCP1 DP Auxiliary channel
246 | TCP1_AUX_N | I/O | TCP1 DP Auxiliary channel
248 | GND
250 | VDC |  | Main power input 9~20V
252 | VDC |  | Main power input 9~20V
254 | VDC |  | Main power input 9~20V
256 | VDC |  | Main power input 9~20V
258 | VDC |  | Main power input 9~20V
260 | VDC |  | Main power input 9~20V

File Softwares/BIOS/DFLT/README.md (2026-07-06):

💡**Note:** The LattePanda Mu compute module is available in 8GB and 16GB memory versions. It is essential to select the correct BIOS firmware as described below.

### For LattePanda Mu N100 **8GB** RAM Model:

- LP-BS-S70NC1R200-SR-B
- S70NC1R200-8G-A
- S70NC1R200-8G-B **(Latest)**

### For LattePanda Mu N100 / N305 **16GB** RAM Model:

- LP-BS-S70NC1R200-DR-B
- S70NC1R200-16G-A
- S70NC1R200-16G-B **(Latest)**

---

# BIOS Release Notes

## [2026-06] Latest Release
### 📂 BIOS Files
| Variant  | Compatible Model | Filename | Build Date |
| :--- | :--- | :--- | --- |
| **PCIe** | LattePanda Mu N100 **8GB** | `S70NC1R200-8G-B.bin` | 2026/06/03 |
| **PCIe** | LattePanda Mu N100 / N305 **16GB** | `S70NC1R200-16G-B.bin` | 2026/06/03 |
| **SATA** | LattePanda Mu N100 **8GB** | `S70NC1R200-8G-B-SATA.bin`  | 2026/06/03 |
| **SATA** | LattePanda Mu N100 / N305 **16GB** | `S70NC1R200-16G-B-SATA.bin` | 2026/06/03 |

### 📝 Changelog
1. Fixed a security bypass where pressing Enter with an empty password allowed read-only BIOS access. 
2. Added support for controlling GPIO and I2C drivers directly within Windows. 

## [2025-12] Second Release
### 📂 BIOS Files
| Variant | Compatible Model | Filename | Build Date |
| :--- | :--- | :--- | ---- |
| **PCIe** | LattePanda Mu N100 **8GB** | `S70NC1R200-8G-A.bin` | 2025/12/19 |
| **PCIe** | LattePanda Mu N100 / N305 **16GB** | `S70NC1R200-16G-A.bin` | 2025/12/19 |
| **SATA** | LattePanda Mu N100 **8GB** | `S70NC1R200-8G-A-SATA.bin` | 2025/12/19 |
| **SATA** | LattePanda Mu N100 / N305 **16GB** | `S70NC1R200-16G-A-SATA.bin` | 2025/12/19 |

### 📝 Changelog
1. Added SMBIOS information.
2. Added information for eMMC, SATA, NVMe, etc. in the Main tab.
3. Unlocked PCIe Clock configuration menu.
4. Unlocked PCIe port ASPM configuration menu (Default: Disabled).
5. Added toggle options for TP (Touch Panel) and eDP display.
6. Added GPIO function support and configuration menu.
7. Enabled SpeedStep(TM) and RC6; changed Package C State Limit to Auto.
8. Added RTL8111H PXE boot support.
9. Fixed the issue of duplicate UART numbering in the OS.
10. Added Windows Recovery support (Requires customized OS).

---

## [2024-06/07] Initial Release
### 📂 BIOS Files
| Variant | Compatible Model | Filename | Build Date |
| :--- | :--- | :--- | ---- |
| **PCIe** | LattePanda Mu N100 **8GB** | `LP-BS-S70NC1R200-SR-B.bin` | 2024/07/08 |
| **PCIe** | LattePanda Mu N100 / N305 **16GB** | `LP-BS-S70NC1R200-DR-B.bin` | 2024/06/19 |
| **SATA** | LattePanda Mu N100 **8GB** | `LP-BS-S70NC1R200-SR-B-SATA.bin` | 2024/07/05 |
| **SATA** | LattePanda Mu N100 / N305 **16GB** | `LP-BS-S70NC1R200-DR-B-SATA.bin` | 2024/06/20 |

### 📝 Changelog
- Initial BIOS firmware release.

---

# DFLT Branch Introduction

Default factory BIOS interface configuration for LattePanda Mu.

## Interface Configuration

### Special Notes

- **USB2_P6**: Dedicated for USB Type-C, must be used in conjunction with a PD controller, **cannot be used as a standard USB port**.

### HSIO (High-Speed Input/Output)

- **HSIO0**: USB 3.2 10Gbps
- **HSIO1**: USB 3.2 10Gbps
- **HSIO2**: PCIe 3.0 x1
- **HSIO3**: PCIe 3.0 x1
- ==========
- **HSIO8**: PCIe 3.0 x4 (Lane 0)
- **HSIO9**: PCIe 3.0 x4 (Lane 1)
- **HSIO10**: PCIe 3.0 x4 (Lane 2)
- **HSIO11**: PCIe 3.0 x4 (Lane 3)
- ==========
- **HSIO6**: PCIe 3.0 x1

### DDI/TCP

- **DDIA**: eDP 1.4b (eDP interface on LattePanda Mu)

- **DDIB**: HDMI 2.0

- **TCP0**: HDMI 2.0

- **TCP1**: USB Type-C (requires external PD controller)

### GPIOs

- **I2C1**: Touch panel (touch connector on LattePanda Mu)
- **I2C2**: Communication with Type-C PD controller
- **GPP_B11**: Type-C PD controller PMCALERT\#
- **GPP_B14**: SATA HDD LED
- **GPP_D0**: WWAN_Power_Off
- **GPP_D1**: WWAN_Reset
- **GPP_D2**: Communication interrupt with Type-C PD controller

Other GPIOs not listed are not allocated specific functions.

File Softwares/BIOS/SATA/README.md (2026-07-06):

💡**Note:** The LattePanda Mu compute module is available in 8GB and 16GB memory versions. It is essential to select the correct BIOS firmware as described below.

### For LattePanda Mu N100 **8GB** RAM Model:

- LP-BS-S70NC1R200-SR-B-SATA
- S70NC1R200-8G-A-SATA
- S70NC1R200-8G-B-SATA **(Latest)**

### For LattePanda Mu N100 / N305 **16GB** RAM Model:

- LP-BS-S70NC1R200-DR-B-SATA
- S70NC1R200-16G-A-SATA
- S70NC1R200-16G-B-SATA **(Latest)**

---

# BIOS Release Notes

## [2026-06] Latest Release
### 📂 BIOS Files
| Variant  | Compatible Model | Filename | Build Date |
| :--- | :--- | :--- | --- |
| **PCIe** | LattePanda Mu N100 **8GB** | `S70NC1R200-8G-B.bin` | 2026/06/03 |
| **PCIe** | LattePanda Mu N100 / N305 **16GB** | `S70NC1R200-16G-B.bin` | 2026/06/03 |
| **SATA** | LattePanda Mu N100 **8GB** | `S70NC1R200-8G-B-SATA.bin`  | 2026/06/03 |
| **SATA** | LattePanda Mu N100 / N305 **16GB** | `S70NC1R200-16G-B-SATA.bin` | 2026/06/03 |

### 📝 Changelog
1. Fixed a security bypass where pressing Enter with an empty password allowed read-only BIOS access. 
2. Added support for controlling GPIO and I2C drivers directly within Windows. 

## [2025-12] Second Release
### 📂 BIOS Files
| Variant | Compatible Model | Filename | Build Date |
| :--- | :--- | :--- | ---- |
| **PCIe** | LattePanda Mu N100 **8GB** | `S70NC1R200-8G-A.bin` | 2025/12/19 |
| **PCIe** | LattePanda Mu N100 / N305 **16GB** | `S70NC1R200-16G-A.bin` | 2025/12/19 |
| **SATA** | LattePanda Mu N100 **8GB** | `S70NC1R200-8G-A-SATA.bin` | 2025/12/19 |
| **SATA** | LattePanda Mu N100 / N305 **16GB** | `S70NC1R200-16G-A-SATA.bin` | 2025/12/19 |

### 📝 Changelog
1. Added SMBIOS information.
2. Added information for eMMC, SATA, NVMe, etc. in the Main tab.
3. Unlocked PCIe Clock configuration menu.
4. Unlocked PCIe port ASPM configuration menu (Default: Disabled).
5. Added toggle options for TP (Touch Panel) and eDP display.
6. Added GPIO function support and configuration menu.
7. Enabled SpeedStep(TM) and RC6; changed Package C State Limit to Auto.
8. Added RTL8111H PXE boot support.
9. Fixed the issue of duplicate UART numbering in the OS.
10. Added Windows Recovery support (Requires customized OS).

---

## [2024-06/07] Initial Release
### 📂 BIOS Files
| Variant  | Compatible Model | Filename | Build Date |
| :--- | :--- | :--- | --- |
| **PCIe** | LattePanda Mu N100 **8GB** | `LP-BS-S70NC1R200-SR-B.bin` | 2024/07/08 |
| **PCIe** | LattePanda Mu N100 / N305 **16GB** | `LP-BS-S70NC1R200-DR-B.bin` | 2024/06/19 |
| **SATA** | LattePanda Mu N100 **8GB** | `LP-BS-S70NC1R200-SR-B-SATA.bin` | 2024/07/05 |
| **SATA** | LattePanda Mu N100 / N305 **16GB** | `LP-BS-S70NC1R200-DR-B-SATA.bin` | 2024/06/20 |

### 📝 Changelog
- Initial BIOS firmware release.

---

# SATA Branch Introduction

Enabled integrated SATA controller on the basis of standard BIOS.

## Interface Configuration

### Special Notes

- **USB2_P6**: Dedicated for USB Type-C, must be used in conjunction with a PD controller, **cannot be used as a standard USB port**.

### HSIO (High-Speed Input/Output)

- **HSIO0**: USB 3.2 10Gbps
- **HSIO1**: USB 3.2 10Gbps
- **HSIO2**: PCIe 3.0 x1
- **HSIO3**: PCIe 3.0 x1
- ==========
- **HSIO8**: PCIe 3.0 x1
- **HSIO9**: PCIe 3.0 x1
- **HSIO10**: SATA 3.0
- **HSIO11**: SATA 3.0
- ==========
- **HSIO6**: PCIe 3.0 x1

### DDI/TCP

- **DDIA**: eDP 1.4b (eDP interface on LattePanda Mu)

- **DDIB**: HDMI 2.0

- **TCP0**: HDMI 2.0

- **TCP1**: USB Type-C (requires external PD controller)

### GPIOs

- **I2C1**: Touch panel (touch connector on LattePanda Mu)
- **I2C2**: Communication with Type-C PD controller
- **GPP_B11**: Type-C PD controller PMCALERT\#
- **GPP_B14**: SATA HDD LED
- **GPP_D0**: WWAN_Power_Off
- **GPP_D1**: WWAN_Reset
- **GPP_D2**: Communication interrupt with Type-C PD controller

Other GPIOs not listed are not allocated specific functions.

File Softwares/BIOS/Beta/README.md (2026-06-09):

# Beta BIOS

- Beta BIOS may contain unforeseen issues and is recommended for professional developers to try out only.

- Unless specified otherwise, these will not be merged into the main branches (DFLT and SATA) by default.

## LP-BS-S70NC1R200-SR-20240410

Modified from **LP-BS-S70NC1R200-SR-A**, with IBECC option enabled for evaluating stability and performance differences.

**Suitable for:** LattePanda Mu N100 8GB

**Note:** The IBECC option has been integrated into the BIOS firmware of the main branches (DFLT and SATA).

## LP-BS-S70NC1R200-SR-DEBUG

Enable intel DCI debugging interface and UEFI log output for open source firmware developers

**Suitable for:** LattePanda Mu N100 8GB

## LP-BS-S70NC1R200-SR-TGPIO

TGPIO function is enabled. A precise 1pps pulse signal is continuously output at Pin 123 for time sensitive applications.

**Suitable for:** LattePanda Mu N100 8GB

## LP-BS-S70NC1R200-DR-B-TGPIO

TGPIO function is enabled. A precise 1pps pulse signal is continuously output at Pin 123 for time sensitive applications.

**Suitable for:** LattePanda Mu N100 16GB / N305 16GB

## S70NC1R200-8G-B-Windows-GPIO

This firmware introduces native support for GPIO and I2C interfaces under Windows operating systems. 

**Suitable for:** LattePanda Mu N100 8GB

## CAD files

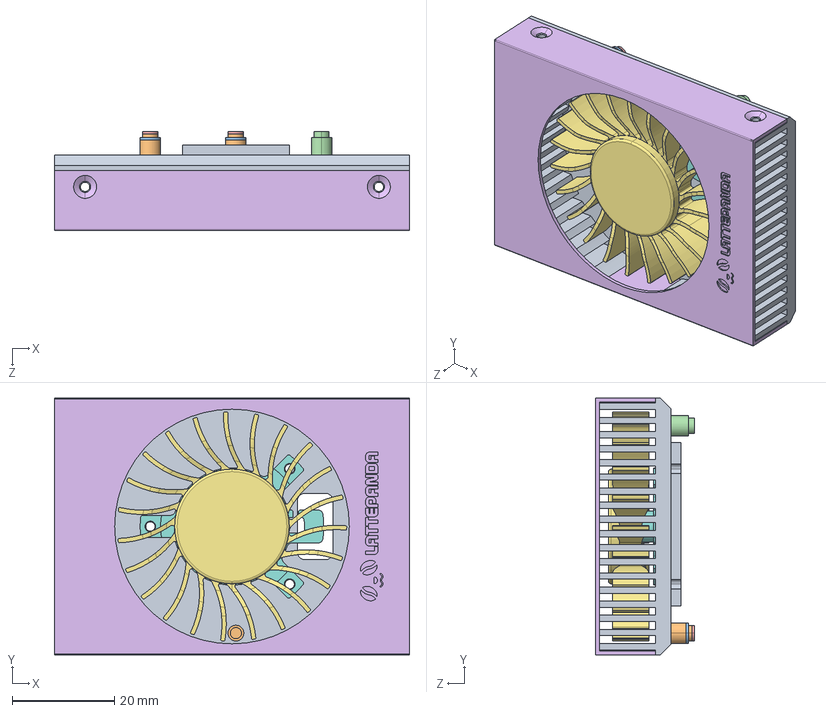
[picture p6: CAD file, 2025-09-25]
Mechanicals/FIT0981_Active_cooler.STEP
69.6 x 50.4 x 19.5 mm
BREP_2.STEP
BREP_960.STEP
BREP_961.STEP
BREP_962.STEP
0105______6pcs.STEP
YE.STEP
ZUO.STEP

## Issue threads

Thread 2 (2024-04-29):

Document pinout voltage levels

g-v-egidy, 2024-04-29:
Thank you very much for adding the documentation about the pinouts.

It would be nice if you could also add a column in the pinout table of the SODIMM pinout that documents the voltage level of  each pin.

For example UART0_RXD and UART0_TXD - are they 3.3V CMOS or 1.8V? The same for SLS_S0 / SLS_S3, the GPIO, the SPI, the I2C buses.

The schematics for the Full EVA Carrier has a note that some voltage levels can be changed. If I understood this correctly, this is probably done together for several IOs that are on one voltage rail. Then please document which pins are together on one voltage rail and what is the default voltage level.

Regarding the TSENSE pin: this is probably a NTC that has 10 kOhms at 25°C. Could you please document which beta value to use for proper temperature readout?

alphaarea, 2024-04-30:
All low-speed interfaces are at 3.3V level, including UART, I2C, GPIO, etc. I'm working on a detailed pinout document.

All pins from the SoC can be configured to 3.3V or 1.8V in the BIOS source code. But 1.8V has negligible power savings compared to 3.3V, and is much more cumbersome to use than 3.3V. So all the pins are configured to 3.3V.

The TSENSE pin is adapted to the 10K B3950 NTC. This will be improved in the detailed pinout document.

g-v-egidy, 2024-04-30:
Thank you very much for the explanation. I'm looking forward to seeing your detailed pinout document.

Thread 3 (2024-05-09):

Document which HSIO each PCIe REFCLK pair belongs to

i509VCB, 2024-05-09:
While I can largely figure this out from the example schematics. It is not clear from looking at the pinout.

From looking at both carrier schematics REFCLK2 seems to belong to HSIO 1 and 3?

| REFCLK | HSIO |
|-|-|
| 0 | 2 |
| 1 | 3 |
| 2 | 8, 9, 10, 11|
| 3 | 3 |
| 4 | 6 |

alphaarea, 2024-05-10:
I apologize for my previous statement in the Discord group.

There is no binding between REFCLK and PCIe Port. Just make sure every PCIe device has a REFCLK.

REFCLK is only bound to CLKREQ, and REFCLKs with the same number are bound to CLKREQ. The CLKREQ function is disabled by default in the current BIOS. In the next version of BIOS, the option to enable or disable CLKREQ will be opened.

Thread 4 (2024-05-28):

Adding TGPIO support to the BIOS

ahmadexp, 2024-05-28:
Would you please add TGPIO enablement support to the BIOS.
TPGIO is available on APTIO as an optional feature.

alphaarea, 2024-05-31:
Is the TGPIO you're referring to the TIME_SYNC pin in the intel documentation?

GPP_B14 on Mu's gold finger, can be configured for TIME_SYNC function. However, it is currently configured as a SATA ACT LED by default, and can't be set to TIME_SYNC directly.

Mu only has one TIME_SYNC pin. Can it meet your project requirements? If you are interested, I can arrange for BIOS engineer to modify a beta BIOS with TIME_SYNC enabled after the development of the next official BIOS release.

Closed 2024-07-29.

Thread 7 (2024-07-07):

Custom HSIO configuration (bios)

g992, 2024-07-07:
Hi! How can i get bios config with next ports?

HSIO0: USB 3.2 10Gbps
HSIO1: PCIe 3.0 x1
HSIO2: PCIe 3.0 x1
HSIO3: PCIe 3.0 x1
==========
HSIO8: SATA 3.0
HSIO9: SATA 3.0
HSIO10: SATA 3.0
HSIO11: SATA 3.0
==========
HSIO6: PCIe 3.0 x1

alphaarea, 2024-07-08:
You can only configure interface features to the extent allowed by the hardware

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

If you need more than 2 SATA interfaces, please prioritize PCIe SATA host controllers.

The SATA activity led can be derived from the Pin 11 activity signal of each SATA device without the involvement of the host controller.

g992, 2024-07-08:
hmm, okay, sorry, first time in configuring interfaces
so.. cinfiguration below is possible?
HSIO0: USB 3.2 10Gbps
HSIO2: PCIe 3.0 x1
HSIO2: PCIe 3.0 x1
HSIO3: PCIe 3.0 x1

HSIO8: PCIe 3.0 x4 (Lane 0)
HSIO9: PCIe 3.0 x4 (Lane 1)
HSIO10: SATA 3.0
HSIO11: SATA 3.0

HSIO6: PCIe 3.0 x1

And, can i use USB 3.2 like usb 3.0, just connect rx/tx lines to USB Type A Connector?  Or i must use type-c connector with controller?

alphaarea, 2024-07-08:
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

Yes, the current configuration will work.

USB 3.2 is not directly related to Type-C. It can still be designed as a Type-A connector.
However, the 10Gbps signal is more fragile and requires more careful design of the alignment, or limiting the speed to USB 3.0 to avoid instability.

g992, 2024-07-08:
Great! how can I get a BIOS with this configuration?

Also, are there instructions for flashing the BIOS somewhere?

about USB3.0: I understand, I don’t need 10Gbps, since only a flash drive will be connected to this connector

alphaarea, 2024-07-17:
This is the BIOS with the HSIO configuration modified as you requested. The flashing method [can be found here](https://docs.lattepanda.com/content/mu_edition/full_eval/#flashing-carriers-bios). **After updating the BIOS, you must power down and remove the RTC battery to restore the default settings.**

Note that this is not an official release, and you should have a programmer (e.g. CH341A) ready to repair the LattePanda Mu when it cannot boot at all.

[LP-BS-S70NC1R200-SR-A-g992.zip](https://github.com/user-attachments/files/16260976/LP-BS-S70NC1R200-SR-A-g992.zip)

g992, 2024-07-17:
thanks! can I install my bios only on additional memory? (I did not provide for this in my project) I have a programmer, can I just flash the memory that is installed on the LattePanda MU module?

jamesvici, 2024-07-19:
If I wanted M.2 M-Key for SATA and NVMe then the two SATA lines need to be the first lane on the M.2 ports. If I also want the port to be NVMe x4, are there any rules to which HSIO lanes can be grouped together? For example, could port 1 would be HSIO10:6 while port 2 is HSIO11+HSIO1:3? I know there's 1/2/4/8/16 group sizes, but I don't know if those have to be with certain lanes as well.

alphaarea, 2024-07-22:
> If I wanted M.2 M-Key for SATA and NVMe then the two SATA lines need to be the first lane on the M.2 ports. If I also want the port to be NVMe x4, are there any rules to which HSIO lanes can be grouped together? For example, could port 1 would be HSIO10:6 while port 2 is HSIO11+HSIO1:3? I know there's 1/2/4/8/16 group sizes, but I don't know if those have to be with certain lanes as well.

The allowed PCIe port configurations are as follows:

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

The current BIOS does not support automatic switching between SATA/PCIe for the M.2 interface. You need to specify the interface's purpose, or switch functions by flashing the BIOS.

alphaarea, 2024-07-22:
> thanks! can I install my bios only on additional memory? (I did not provide for this in my project) I have a programmer, can I just flash the memory that is installed on the LattePanda MU module?

Both the carrier and the Mu have ROMs that serve the same complete functions, and either ROM can be used by switching via the BIOS_SEL pin.

El-Luhb, 2024-09-22:
Hello. I got a similar BIOS as g992.
```
HSIO0: USB 3.2 10Gbps
HSIO1: PCIe 3.0 x1
HSIO2: PCIe 3.0 x1
HSIO3: PCIe 3.0 x1
==========
HSIO8: PCIe 3.0 x1
HSIO9: PCIe 3.0 x1
HSIO10: PCIe 3.0 x1
HSIO11: PCIe 3.0 x1
==========
HSIO6: PCIe 3.0 x1
```
On my carrier it shows a strange behavior. Only certain configurations (assignments) work, but then only partially. And on the Lite carrier it runs normally, like both USB3 ports. I am still waiting for new BIOS chips as I bricked the first two (on both my carriers). Then I will test the BIOS again on fresh chips.

El-Luhb, 2024-09-25:
Was now able to install the BIOS on my carrier.
It works, but I still observe some strange behavior.
It seems that a custom BIOS cannot easily be installed on the Mu itself without causing errors. At least in the configuration I need here.
Is this correct or have I done something wrong here?
Has anyone here had similar experiences?
I followed the linked flashing method, for the Mu BIOS. For my carrier BIOS I used a CH341A (modded to 3.3V).

alphaarea, 2024-09-30:
@El-Luhb I replied to you in your project repository, I'll close this issue if there are no further questions.

mkohler99, 2024-12-19:
Hello, looking at options for a custom carrier board and have a question about PCIE allocation. Looking at the chart above, it seems like this configuration would be possible: is that true?

HSIO0: USB 3.2 10Gbps
HSIO1: USB 3.2 10Gbps
HSIO3: PCIe 3.0 x2 (Lane 0)
HSIO3: PCIe 3.0 x2 (Lane 1)

HSIO8: PCIe 3.0 x4 (Lane 0)
HSIO9: PCIe 3.0 x4 (Lane 1)
HSIO10: PCIe 3.0 x4 (Lane 2)
HSIO11: PCIe 3.0 x4 (Lane 3)

HSIO6: PCIe 3.0 x1

Im looking at using the x2 Slot for a 10g Network interface

Thanks!

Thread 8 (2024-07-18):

How to control TCP0 and TCP1 alt modes from MCU

i509VCB, 2024-07-18:
I would like to use the TCP0 and TCP1 as Type-C with alt-mode. Diagram of what I am trying to do:
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

From what I can tell, these will require a PD controller. The full carrier board schematic uses a `IT8851`:
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

However I am unable to acquire an IT8851. I will use an MCU and control power delivery from that.

From what I can tell in the [Intel 600 Series Chipset Family PCH datasheet](https://www.intel.com/content/www/us/en/content-details/648364/intel-600-series-chipset-family-platform-controller-hub-pch-datasheet-volume-1-of-2.html), 26.1.1 states the following:

> SMLink1 is used to communicate with USB-C* PD Controller on the platform to
configure different modes such as USB, Display Port, Thunderbolt*, etc. When used
for Integrated USB-C purposes, a soft strap must be set to indicate that integrated
USB-C ports from CPU are being used.

26.2
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

This matches with what I see in the schematic for pins 3, 4 and 5. The datasheet also mentions a second I2C port (I2C2 on the module), something with retimers.

Although beyond what the datasheet states, there is nothing describing what messages get sent to and from the PD controller.

Regarding the I2C/Smbus interface, is this defined by the SoC or defined by the BIOS? Is LattePanda able to describe the interface to configure the USB-C port mode and muxing in TCP0 and TCP1 over smbus (what messages, layout of each message)? How many I2C interfaces do I need to use for this (1 or 2)?

I tried to see if coreboot had anything to reference on this. I could not find anything.

jamesvici, 2024-07-19:
The previously linked datasheet is for a 600-series PCH. The [Intel N100 Datasheet](https://edc.intel.com/content/www/us/en/design/products/platforms/processor-and-core-i3-n-series-datasheet-volume-1-of-2/001/signal-description_19/) lists the pinstrap as follows
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

i509VCB, 2024-07-19:
> The previously linked datasheet is for a 600-series PCH. The [Intel N100 Datasheet](https://edc.intel.com/content/www/us/en/design/products/platforms/processor-and-core-i3-n-series-datasheet-volume-1-of-2/001/signal-description_19/) lists the pinstrap as follows ![image](https://private-user-images.githubusercontent.com/104049076/350450919-94c5867e-3fd2-4a24-84f6-a281b50a1090.png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)

Yes I forgot to update the original image for the pin strap. Shouldn't change the question still.

i509VCB, 2024-10-22:
I've discussed this a bit on the Discord, but posting here for reference. CrOS EC does have code to talk to the PD mux on the N100:

https://github.com/coreboot/chrome-ec/blob/main/zephyr/include/drivers/intel_altmode.h
https://github.com/coreboot/chrome-ec/blob/main/zephyr/drivers/usbc/intel_altmode.c
https://github.com/coreboot/chrome-ec/blob/main/zephyr/subsys/pd_controller/pd_task_intel_altmode.c

These describe the registers which you use to talk to the PD Mux over Type-C.

I also took a logic analyzer to the full carrier board. I tested with a USB-C to Displayport cable and a USB-C to HDMI + USB hub. Attached are pulseview captures (don't forget the second file for the labels).

[LPMu_SMLink1_USBC_Aug04_2024.zip](https://github.com/user-attachments/files/17469932/LPMu_SMLink1_USBC_Aug04_2024.zip)

The capture does show the `INTEL_ALTMODE_REG_DATA_CONTROL`   and `INTEL_ALTMODE_REG_DATA_STATUS` addresses are used.

This capture only was performed on the `TCP1` port since that is what the full carrier has connected for USB-C. I suspect the address written to the registers, `0x38` for TCP1, states which port to control?
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

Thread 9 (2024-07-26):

HSIO Configuration and Graphic outputs

acruxcz, 2024-07-26:
Hi,

we just design our product using your module, so:
- what about PCIe BIOS? We prefer maximum number of PCI and 2 or 4 USB 3. What is a planed configuration for that bios?
- We strongly prefer using only DP/eDP ports. There is any possibility to use all 	TCP ports for DP? According ADL-N datasheet, it should be possible....

Thanks.

alphaarea, 2024-08-05:
- You can configure the PCIe and USB3 ports to the extent that the N100 CPU hardware allows, as shown below.
- The video outputs can all be configured as DP connectors, the circuitry for DP is simpler than for HDMI.

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

acruxcz, 2024-08-05:
But this require specific bios for that configuration, right?

alphaarea, 2024-08-06:
Yes, to change the port configuration you must change the BIOS binary, which cannot be done through the BIOS setup menu.

You can request a test BIOS by sending specific configuration requirements to techsupport@dfrobot.com.

DiodeDrop, 2025-05-20:
>
>     * The video outputs can all be configured as DP connectors, the circuitry for DP is simpler than for HDMI.
>

Do you know which lanes are which on TCP0 when configured for DP?
e.g.
TCP0_TX0 --> LANE0
TCP0_TXRX0 --> LANE1
etc.

Or, would you have a reference schematic for DP on the Mu?

DiodeDrop, 2025-05-20:
>
>     * The video outputs can all be configured as DP connectors, the circuitry for DP is simpler than for HDMI.
>

Do you know which lanes are which on TCP0 when configured for DP?
e.g.
TCP0_TX0 --> LANE0
TCP0_TXRX0 --> LANE1
etc.

Or, would you have a reference schematic for DP on the Mu?

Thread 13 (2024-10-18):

Windows 11 IoT (Enterprise) GpioController support

nietras, 2024-10-18:
Trying to use .NET/UWP `GpioController` for GPIO on Latte Panda Mu with Full Carrier Board on Windows 11 IoT Enterprise (x64), but this appears to fail:
```
Unhandled exception. System.NotSupportedException: No GPIO controllers exist on this system.
   at System.Device.Gpio.Drivers.Windows10Driver..ctor()
   at System.Device.Gpio.GpioController.GetBestDriverForBoardOnWindows()
   at System.Device.Gpio.GpioController.GetBestDriverForBoard()
   at System.Device.Gpio.GpioController..ctor(PinNumberingScheme numberingScheme)
   at System.Device.Gpio.GpioController..ctor()
   at Program.<Main>$(String[] args) in C:\Users\Niels\source\repos\GpioDemo\Program.cs:line 7
   at Program.<Main>(String[] args)
```
e.g. with simple code like:
```
new System.Device.Gpio.GpioController()
```
I have installed drivers as found here in this github repo and device manager shows the following for system devices. Maybe something is missing or?

Or how can I use the GPIO from .NET 8/9 in Windows?

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

An-nym-us, 2024-11-30:
the GPIO pins are not yet supported but you can use the I2c and the uart stuff.

nietras, 2024-12-02:
That is unfortunate, since we solely bought the LattePanda expecting Gpio to work? When is this expected to be working and what are the pre-requisites for this to work?

jgqoc, 2024-12-02:
sadly i'm not sure when they will release a bios with the gpio pins working. Now you can use the I2C and UART. As of right now i'm using the I2c's. You can use a i2c to GPIO expander. I have 12 different sensors and multiple relays hooked up to one i2c port.

jgqoc, 2024-12-02:
I was in the same boat, purchased it for the gpio but i've that the I2c  (though i do need more external hardware) actually exceeds what i need and it works very well.

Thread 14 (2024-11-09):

ASPM on PCIe supported?

akirchberger, 2024-11-09:
Hi,

i have a ASRock N100M Mainboard and a LattePanda Mu, both with Ubuntu installed. On the LattePanda Mu i can't get ASPM for PCIe running?

**sudo dmesg | grep ASPM**

**ASRock N100M:**
[    0.020926] PCIe ASPM is forcibly enabled
[    0.282164] acpi PNP0A08:00: _OSC: OS supports [ExtendedConfig ASPM ClockPM Segments MSI EDR HPX-Type3]
[    0.301633] pci 0000:03:00.0: ASPM: overriding L1 acceptable latency from 0x0 to 0x7

**LattePanda Mu**
[    0.035200] PCIe ASPM is disabled
[    0.123456] ACPI FADT declares the system doesn't support PCIe ASPM, so disable it
[    0.354135] acpi PNP0A08:00: _OSC: not requesting OS control; OS requires [ExtendedConfig ASPM ClockPM MSI]
[    0.354349] acpi PNP0A08:00: FADT indicates ASPM is unsupported, using BIOS configuration
[    0.372246] pci 0000:04:00.0: ASPM: overriding L1 acceptable latency from 0x0 to 0x7

Thanks.

alphaarea, 2024-11-19:
Thank you very much for your feedback, we will pay attention to the work of energy-saving technologies, including ASPM, in the development of the next version of BIOS

akirchberger, 2024-11-27:
Great to hear, it is really important for the PCB I am currently developing.

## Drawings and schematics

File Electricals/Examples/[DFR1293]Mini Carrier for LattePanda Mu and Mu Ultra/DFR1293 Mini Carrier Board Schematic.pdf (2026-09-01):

# SBC-LIO-DF-R200 Block Diagram

# DDR4 SODIMM CON

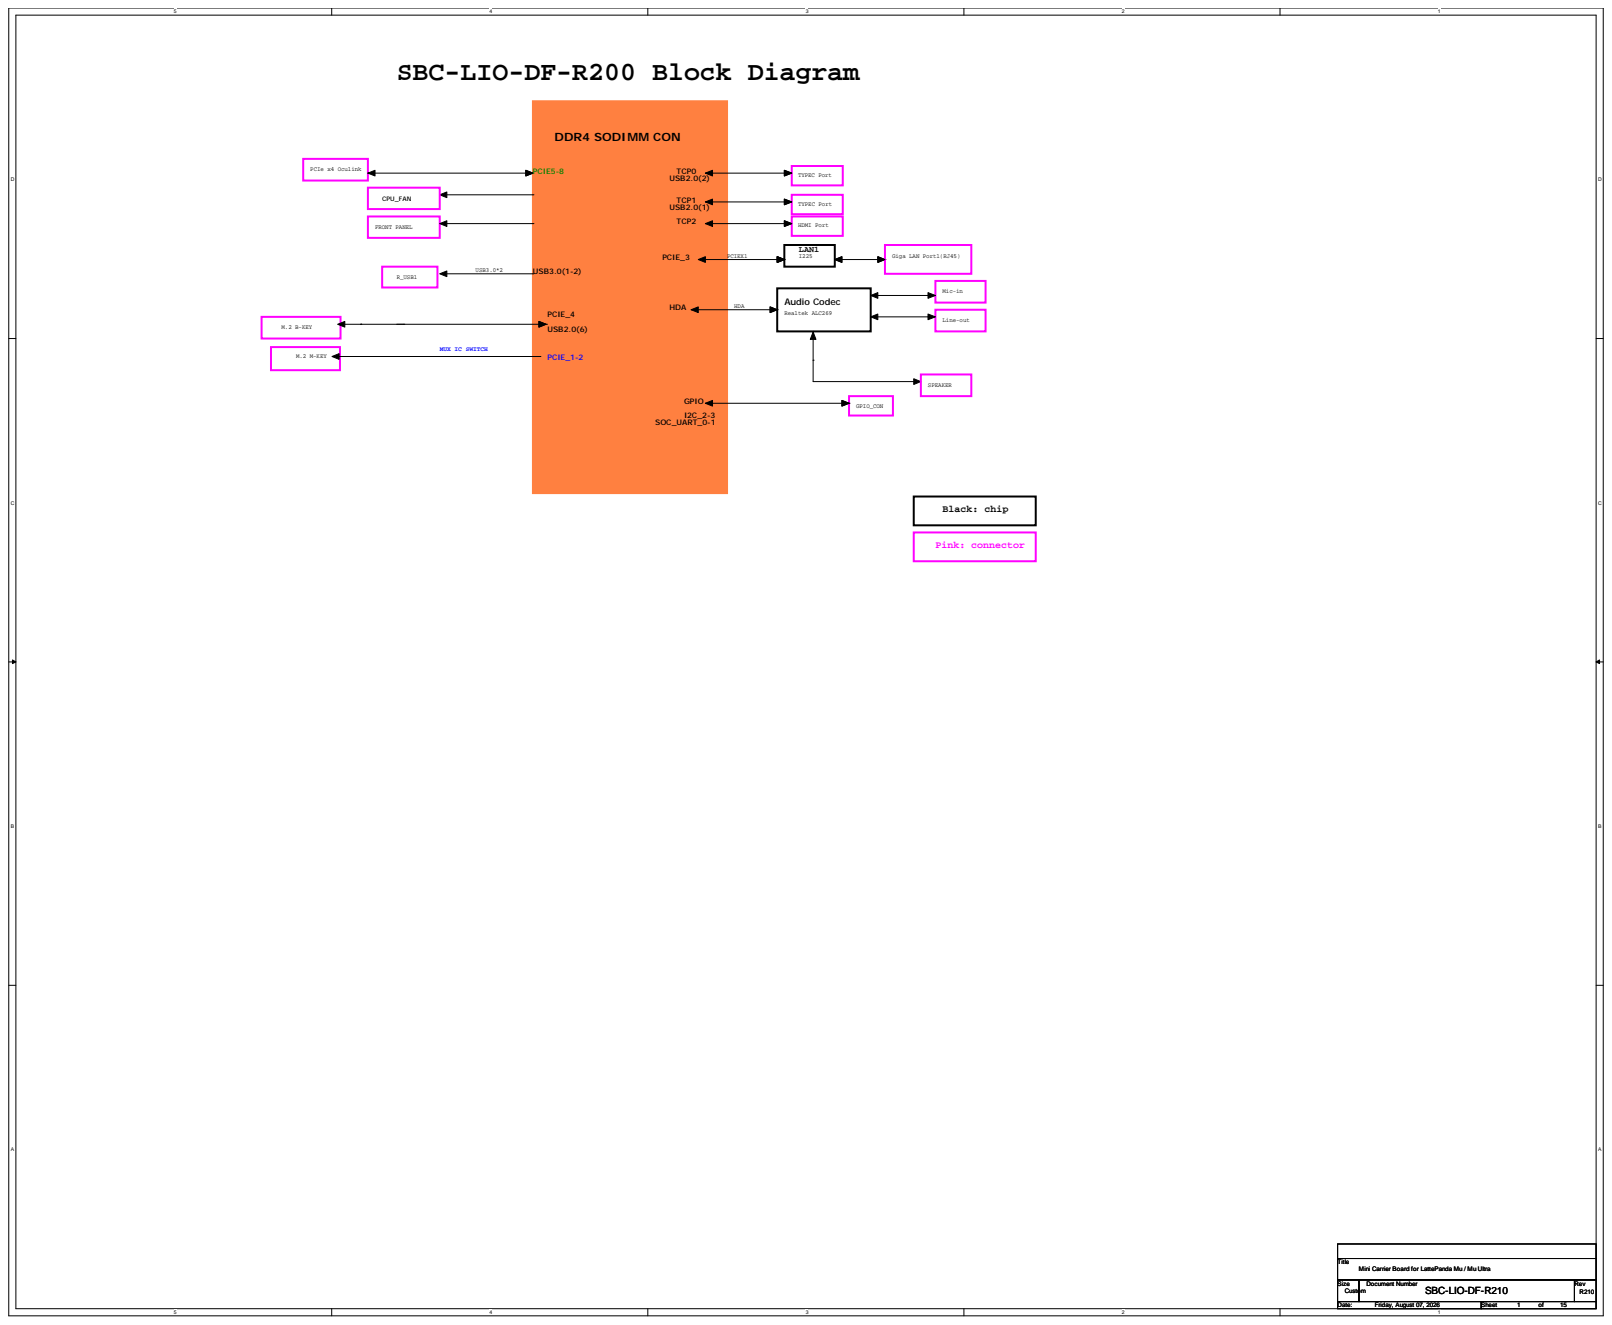
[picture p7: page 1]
M.2 M-KEY; PCIE_1-2; CPU_FAN; FRONT PANEL; TYPEC Port TCP1; TCP0; TYPEC Port; PCIEX1; LAN1; Giga LAN Port1(RJ45); Realtek ALC269; Mic-in; Line-out; Audio Codec; HDA; M.2 B-KEY; SPEAKER; PCIe x4 Oculink; PCIE5-8; GPIO; GPIO_CON; I2C_2-3 SOC_UART_0-1; Pink: connector; Black: chip; PCIE_4; USB2.0(6); PCIE_3; USB3.0(1-2); R_USB1; USB3.0*2; HDMI Port TCP2; USB2.0(2); USB2.0(1); Size; Document Number; Rev; Date:; Sheet; SBC-LIO-DF-R210; Custom; Friday, August 07, 2026; Title

MUX IC SWITCH

Title
Mini Carrier Board for LattePanda Mu / Mu Ultra

12A

8A

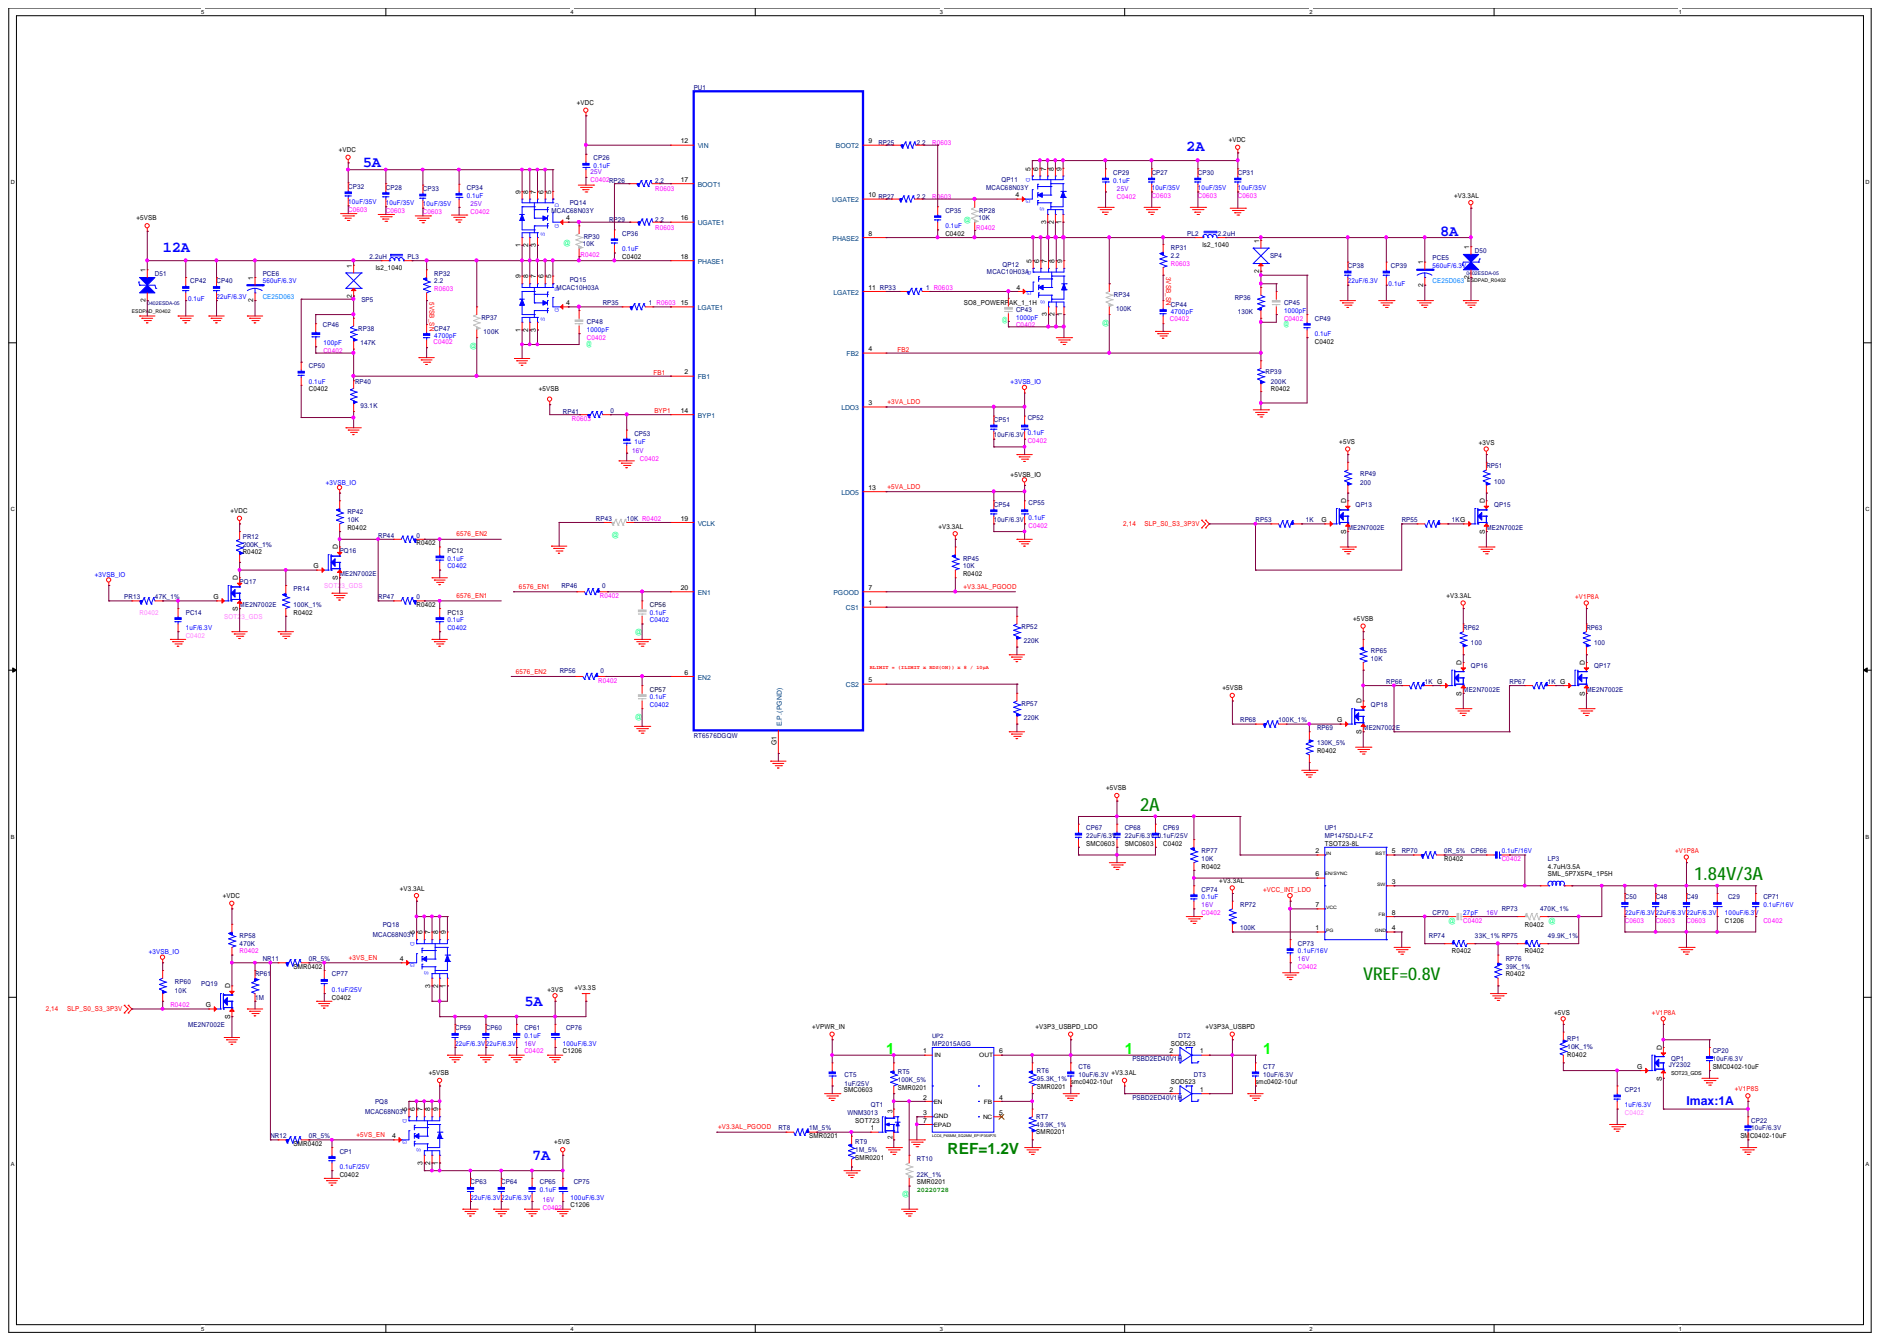
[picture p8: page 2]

RLIMIT = (ILIMIT x RDS(ON)) x 8 / 10μA

D | D
5A | 5A

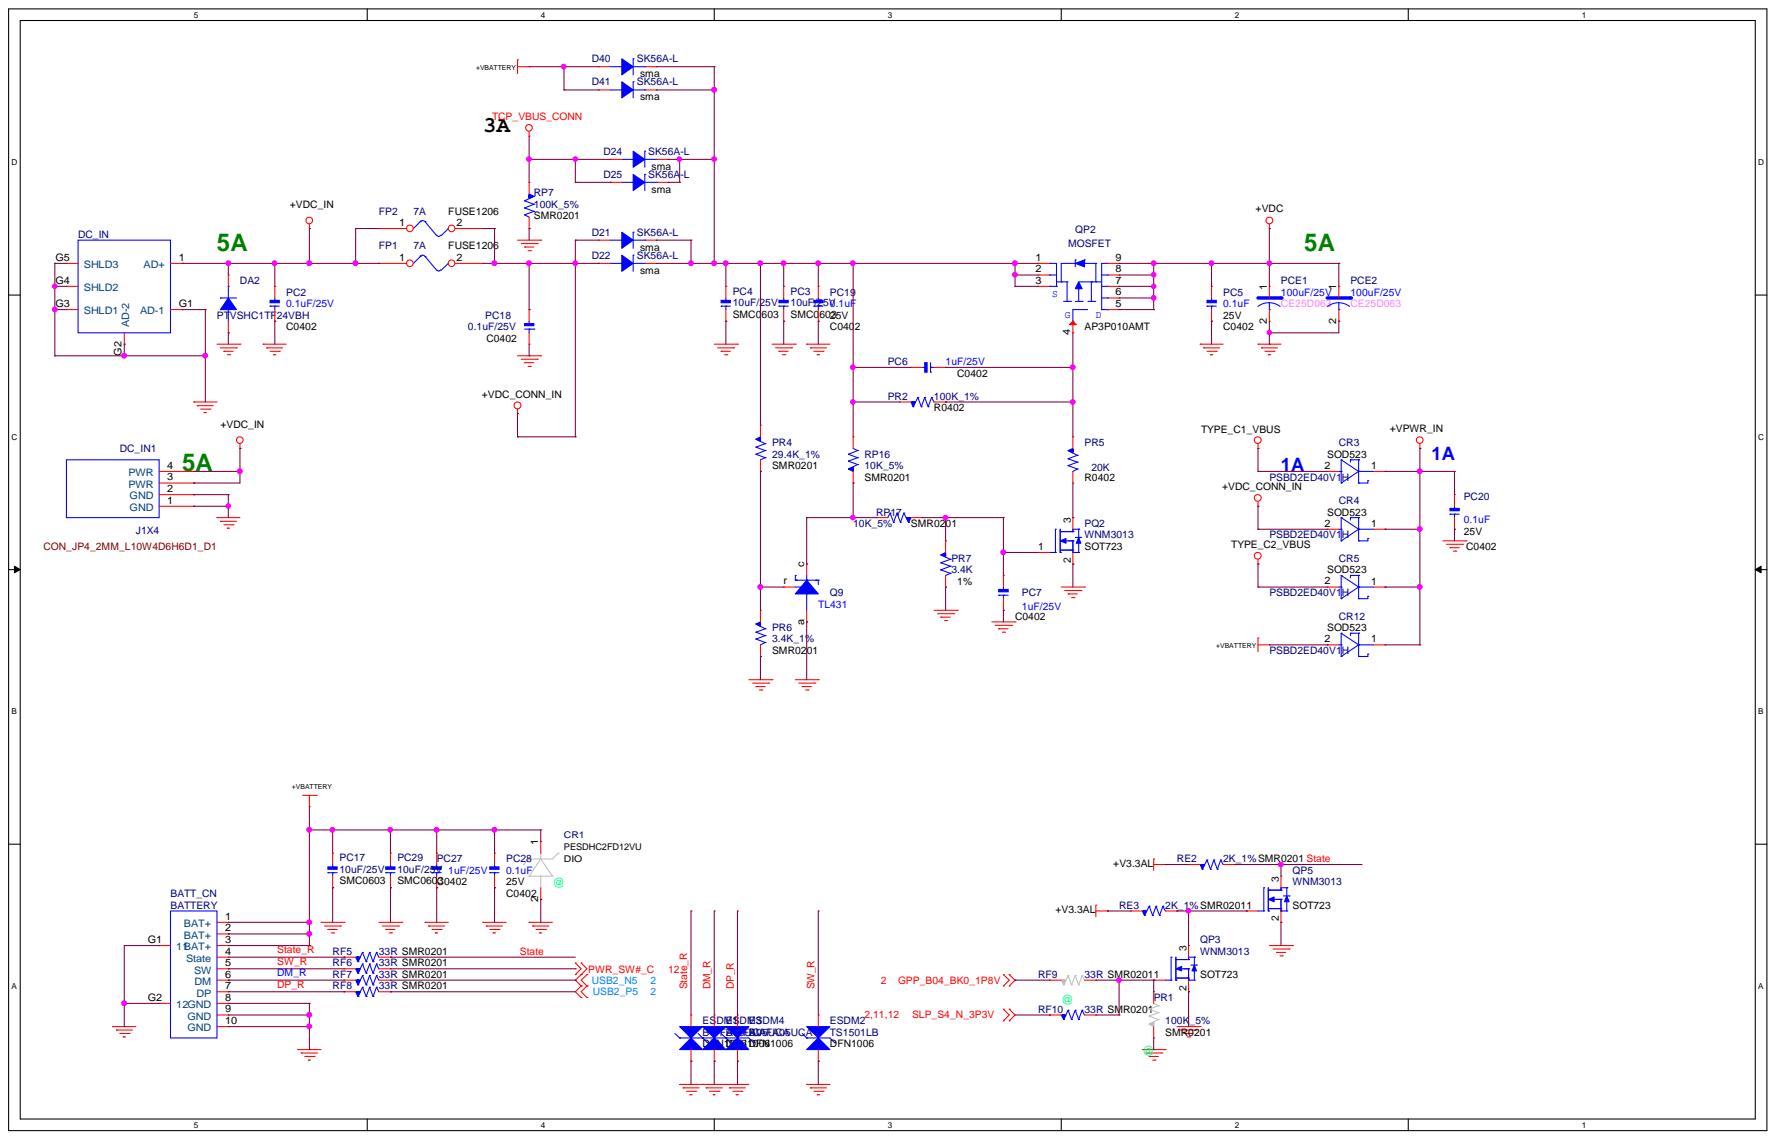
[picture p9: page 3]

# Auto Power

# DEFAULT 2-3

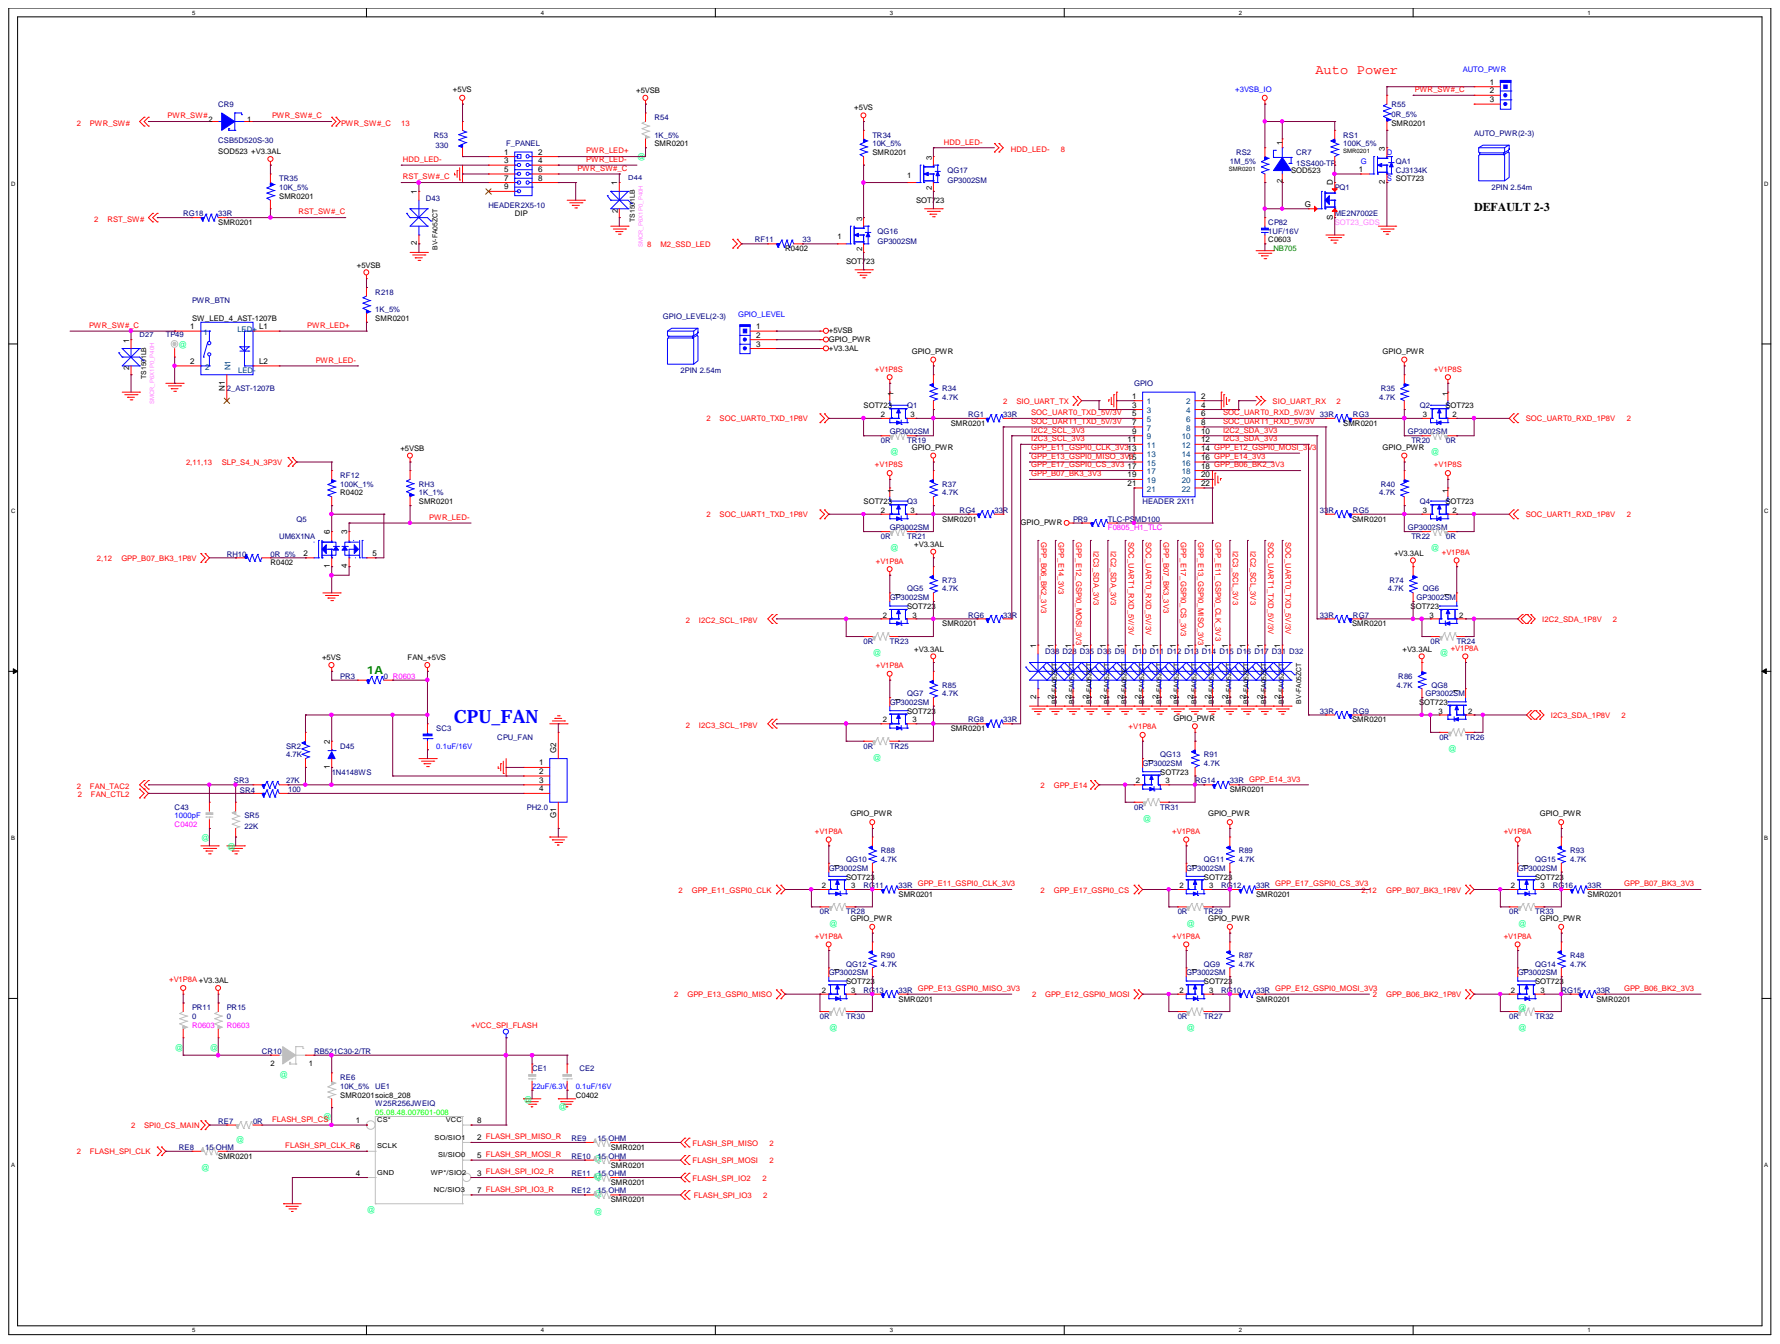
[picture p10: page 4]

2A

2A

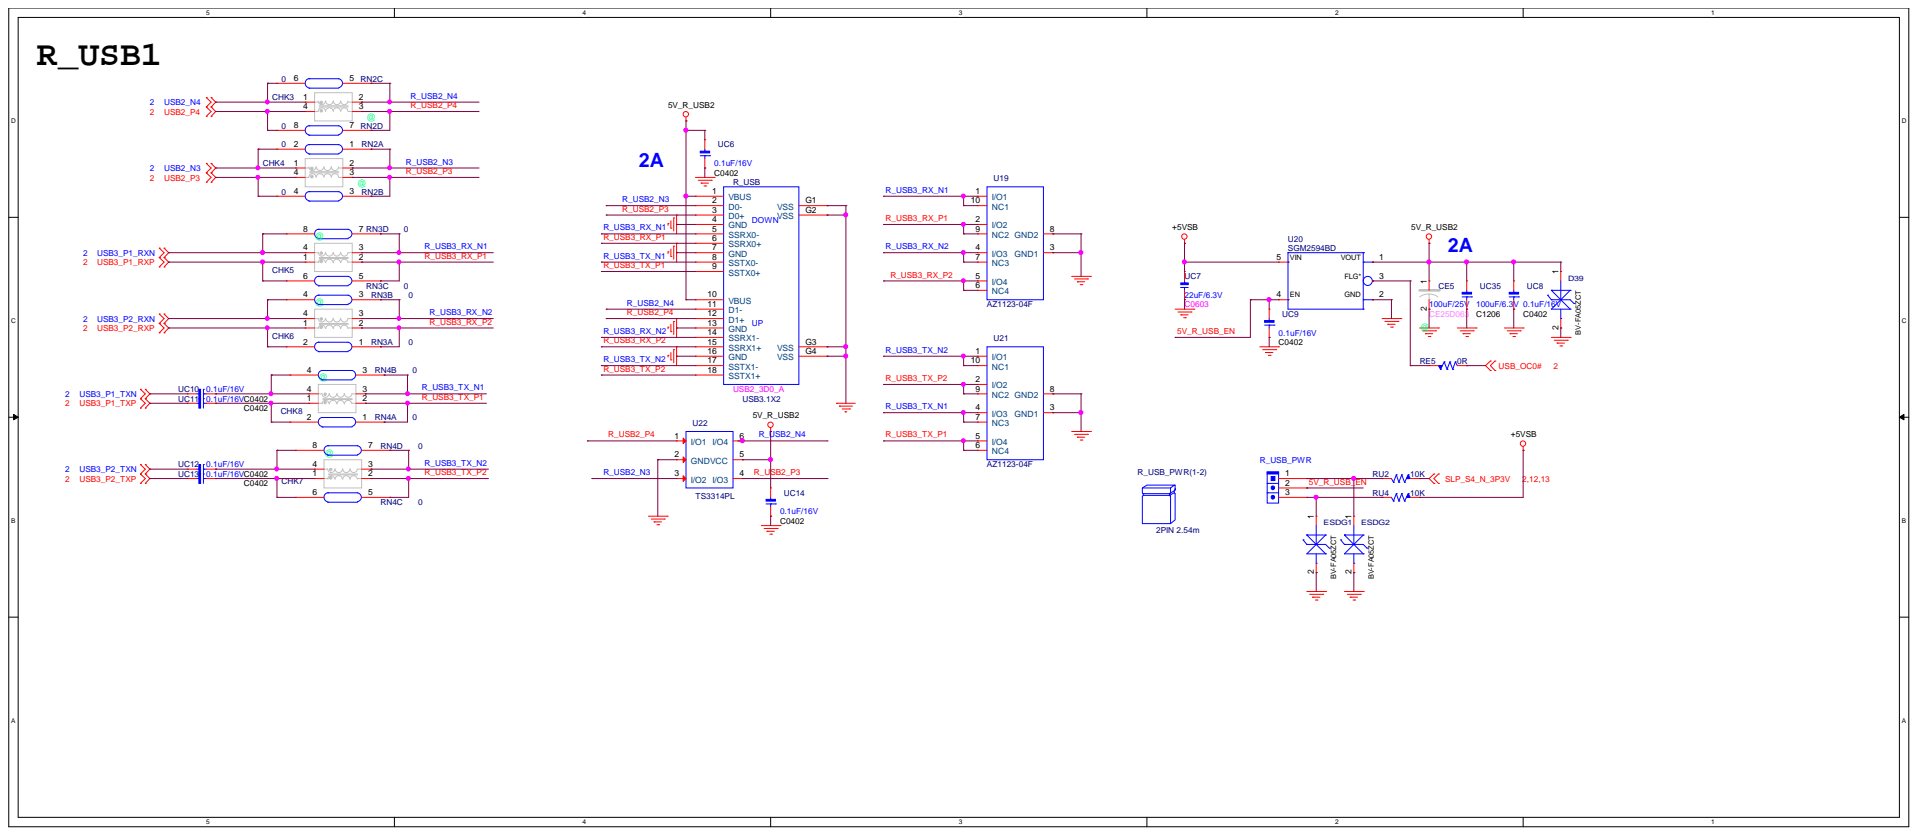
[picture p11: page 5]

# INTEL FOXVILLE

+V3.3AL | +3VSB_LAN

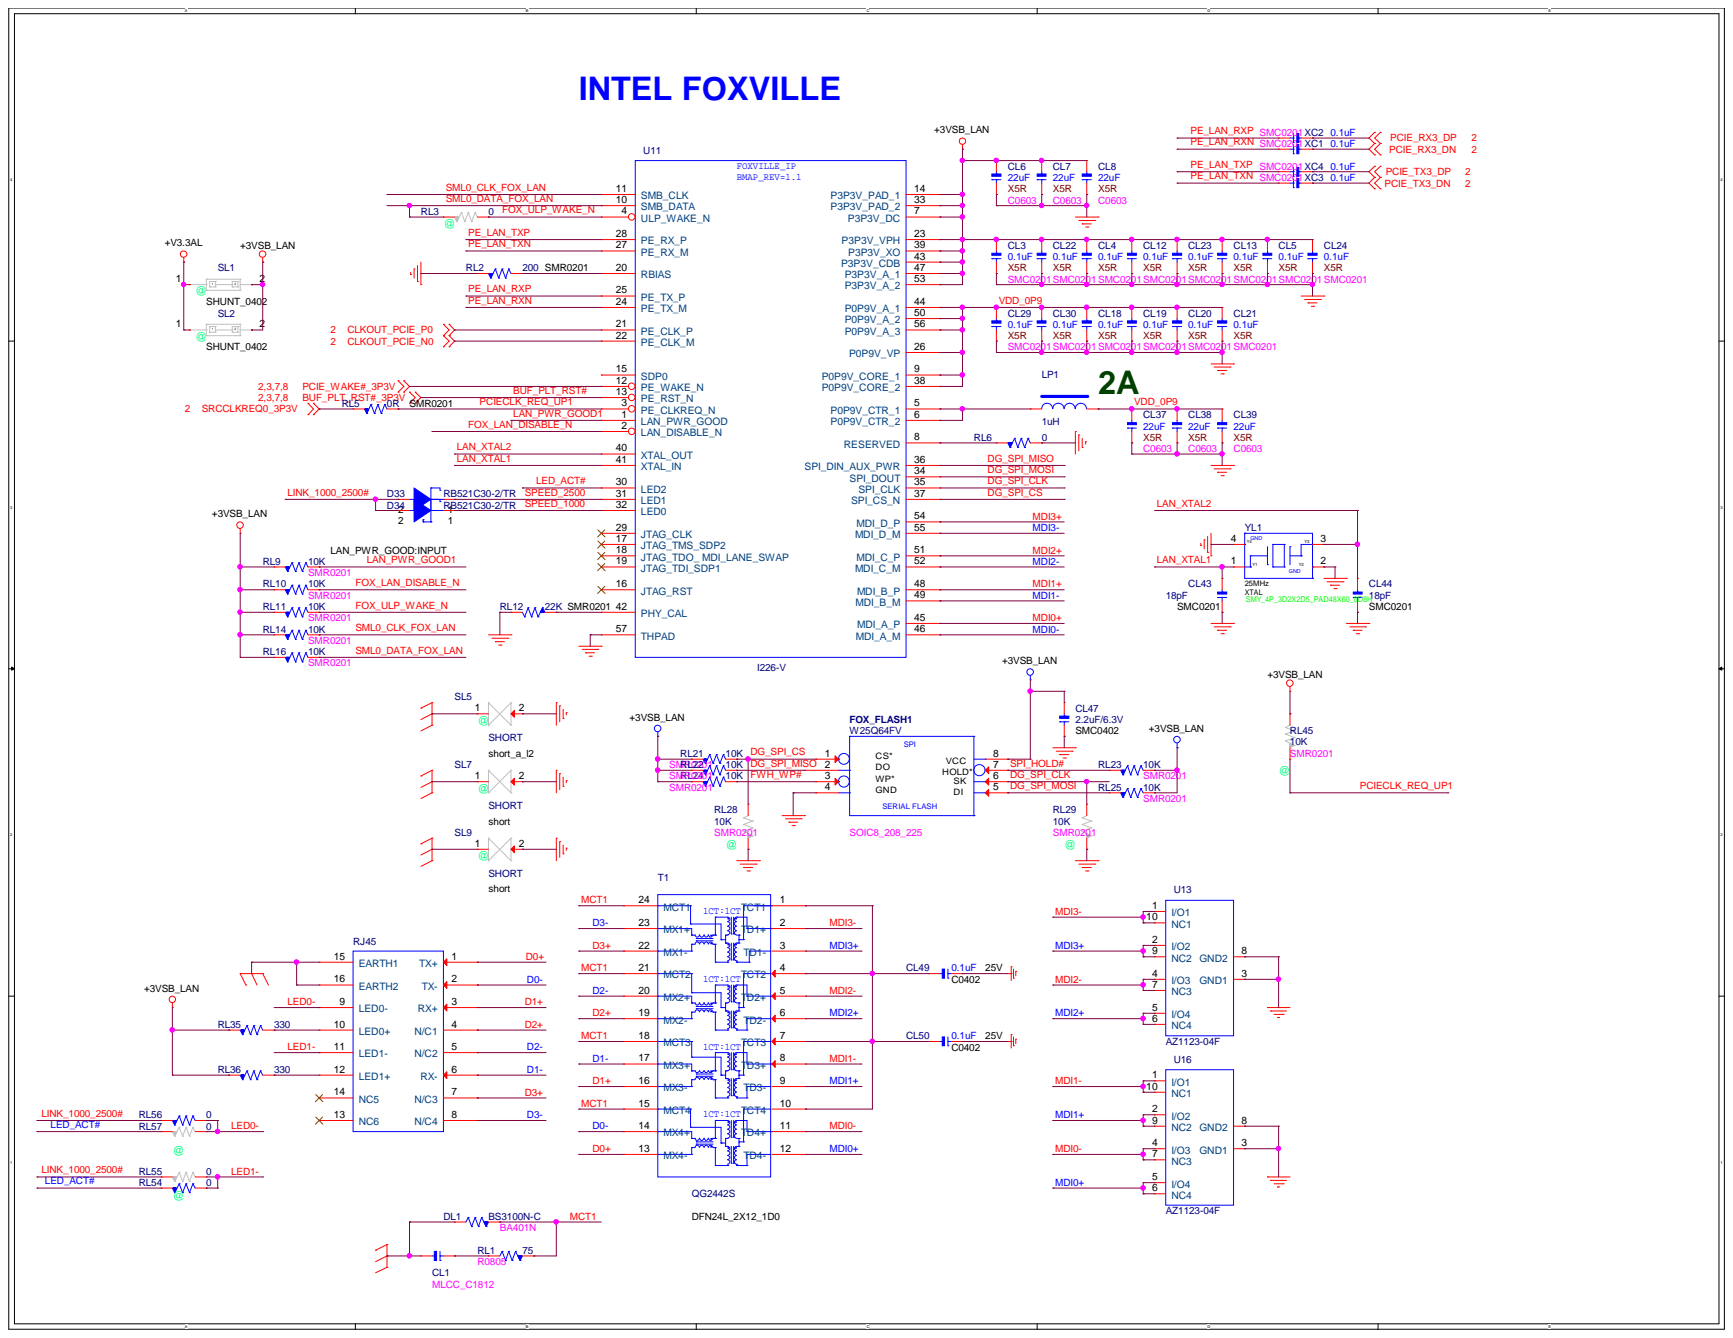
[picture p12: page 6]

+5VS

## GND_AUD

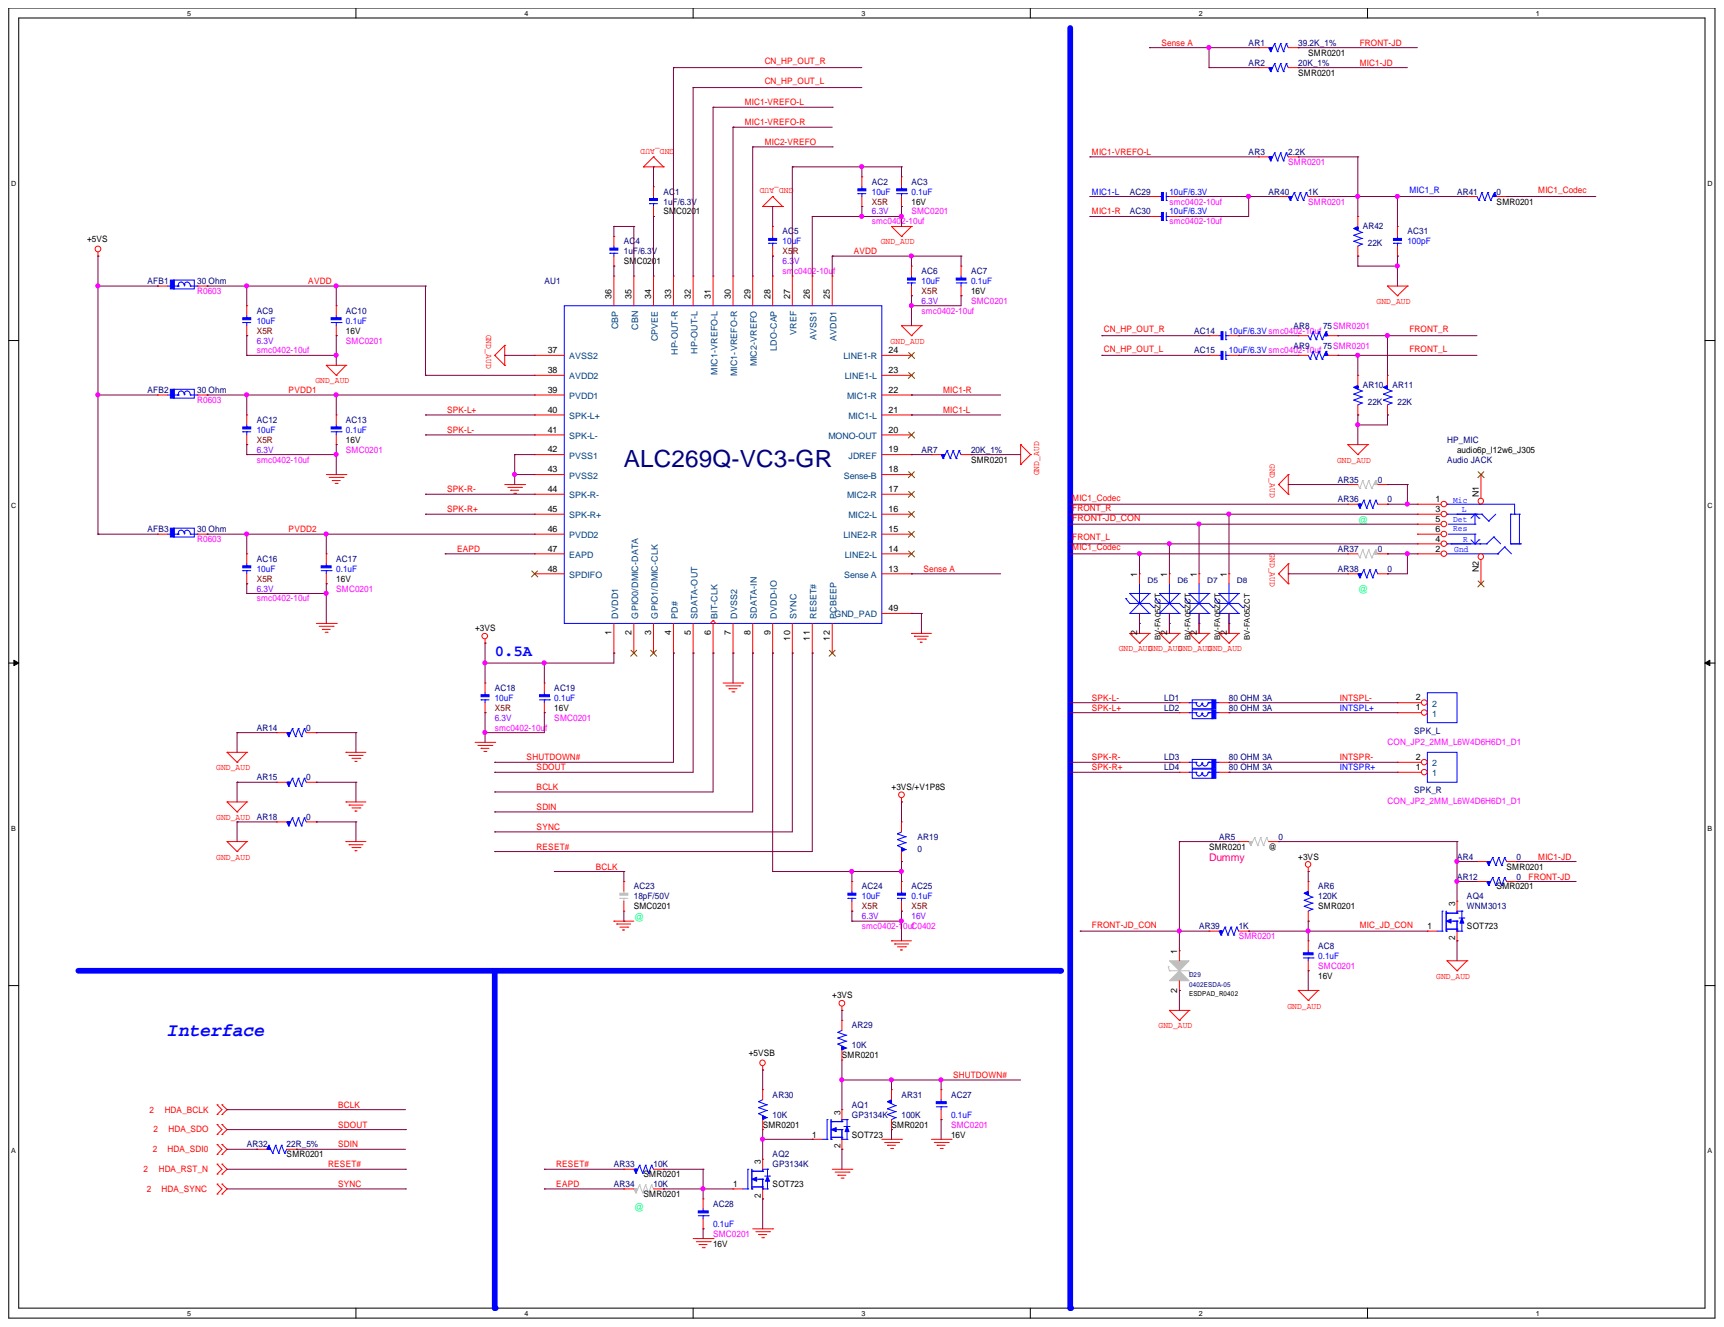
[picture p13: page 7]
Interface; GND_AUD; +5VSB; GND_AUD GND_AUD; GND_AUDGND_AUDGND_AUDGND_AUD; 2 HDA_SYNC; 2 HDA_SDO; 2 HDA_BCLK; 2 HDA_RST_N; 2 HDA_SDI0; AQ4 WNM3013; SOT723; SMR0201; 80 OHM 3A; AC1 1uF/6.3V SMC0201; AC18 10uF X5R 6.3V smc0402-10uf; AFB2; 30 Ohm; 0.1uF SMC0201 16V; Mic; Gnd; HP_MIC; Audio JACK; audio6p_l12w6_J305; SMC0201; 10uF/6.3V smc0402-10uf; AFB3; SPK_R CON_JP2_2MM_L6W4D6H6D1_D1; D5 BV⁻FA⁰⁵ZCT; D8 BV⁻FA⁰⁵ZCT; SPK_L CON_JP2_2MM_L6W4D6H6D1_D1; AC4 1uF/6.3V SMC0201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

FRONT-JD_CON | @ 5 Det
FRONT_L | | 6 Res

D | D

2A

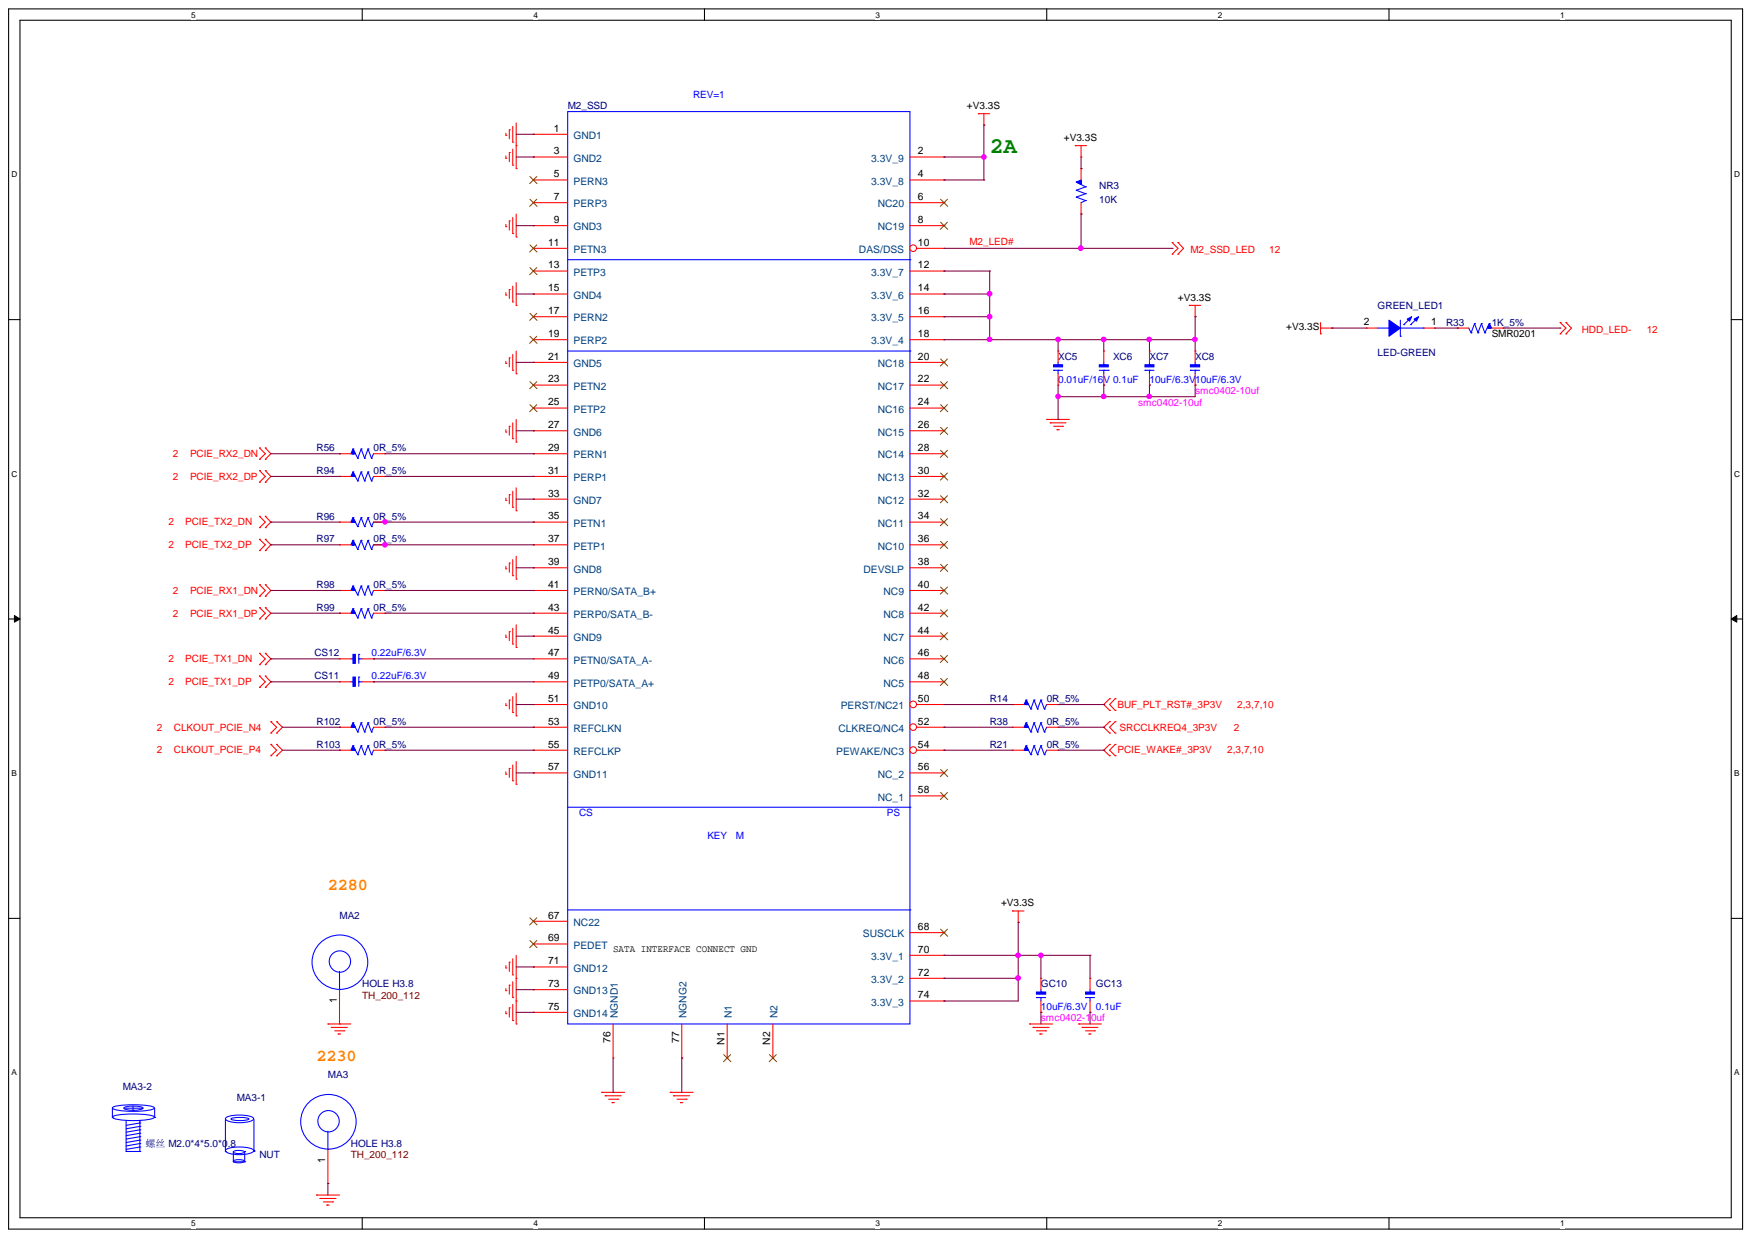
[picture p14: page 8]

SATA INTERFACE CONNECT GND

2A

## +V3.3AL

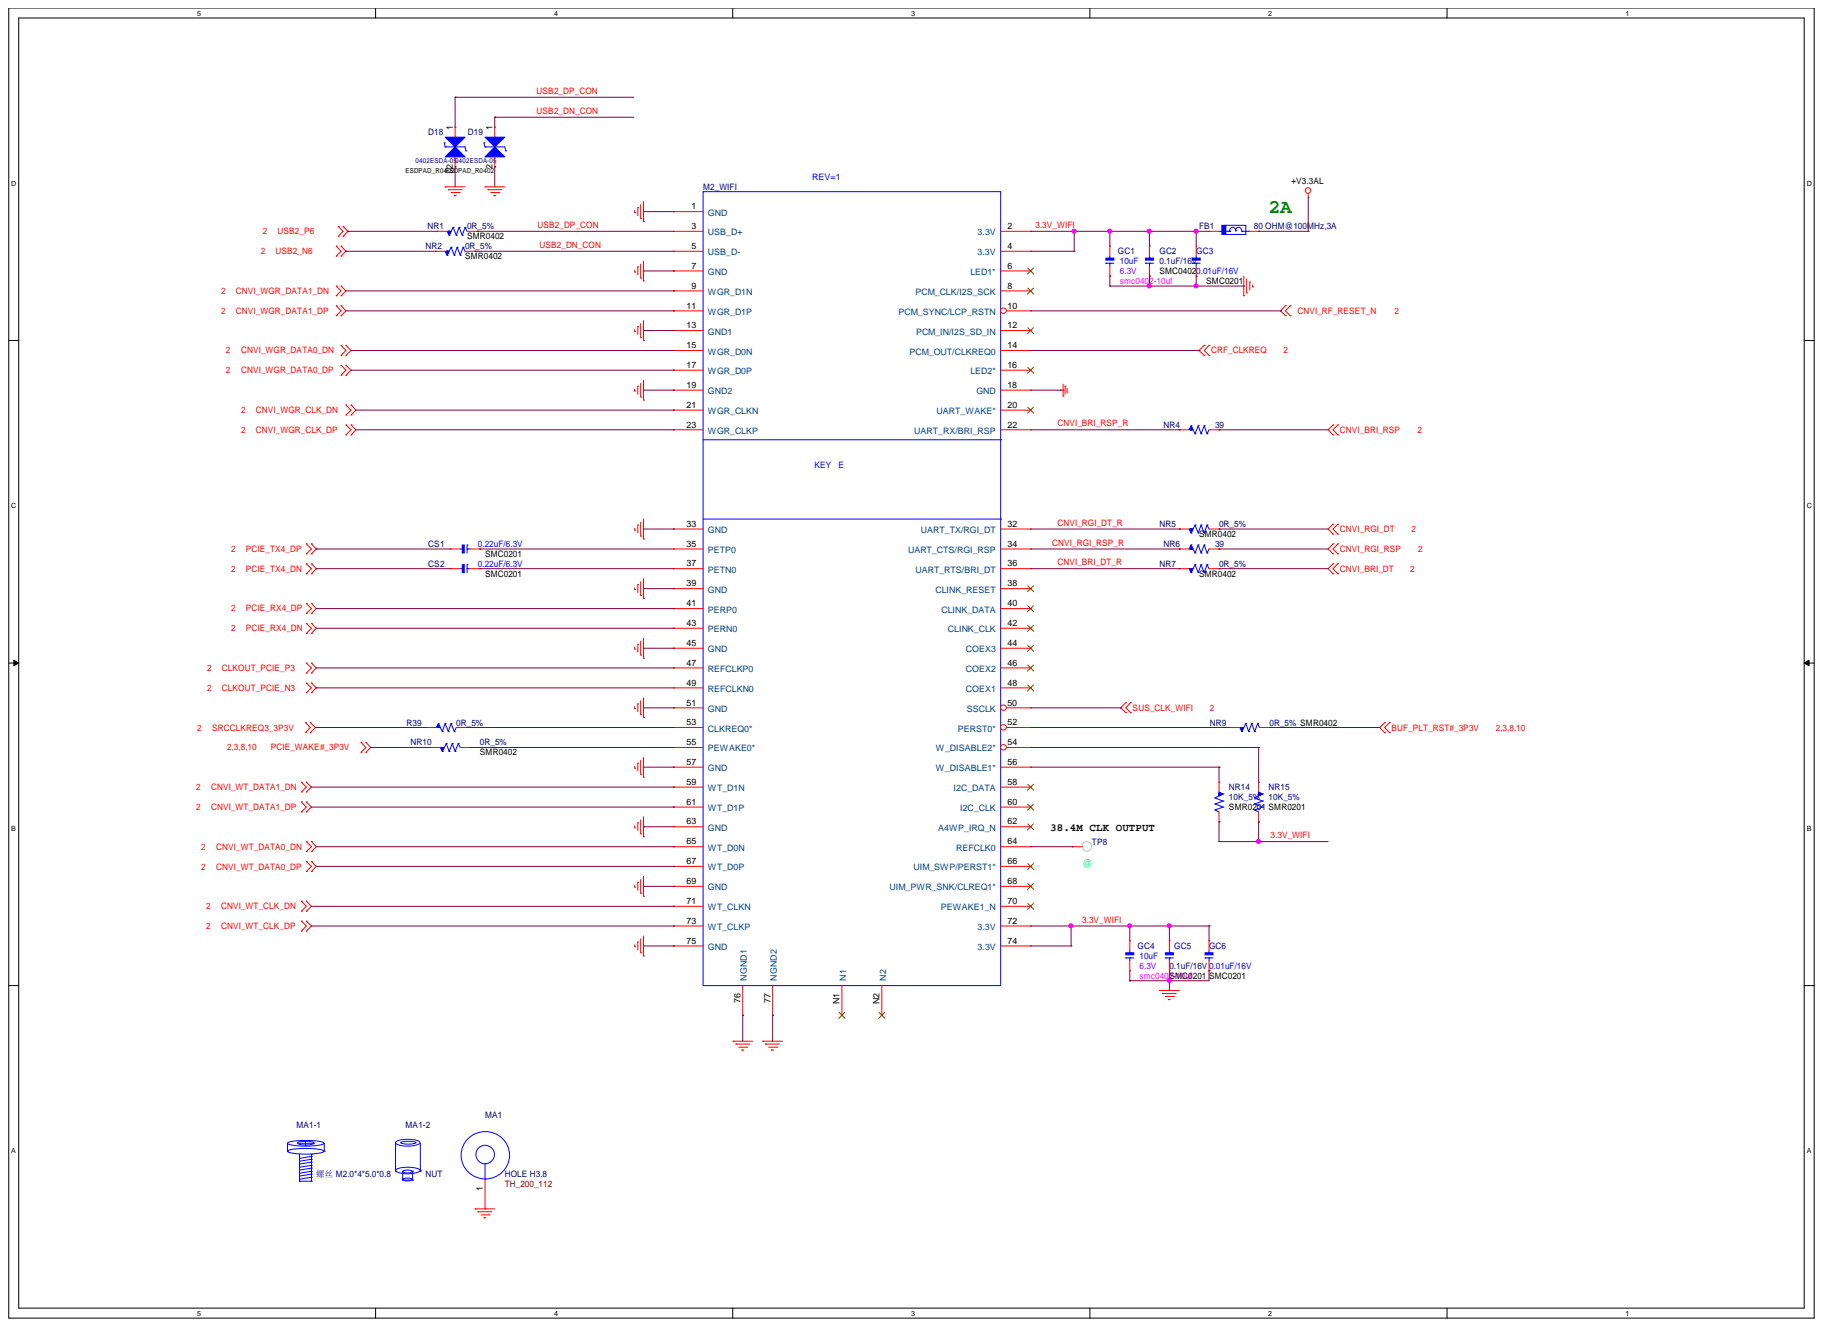
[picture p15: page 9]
38.4M CLK OUTPUT; CRF_CLKREQ; CNVI_RF_RESET_N; CNVI_BRI_RSP; CNVI_RGI_DT; SUS_CLK_WIFI; CNVI_RGI_RSP; CNVI_BRI_DT; BUF_PLT_RST#_3P3V; PCIE_WAKE#_3P3V; 2 USB2_P6; 2 USB2_N6; 2 CNVI_WGR_CLK_DP; 2 CNVI_WGR_CLK_DN; 2 CNVI_WGR_DATA1_DN; 2 CNVI_WGR_DATA1_DP; 2 CNVI_WGR_DATA0_DN; 2 CNVI_WGR_DATA0_DP; 2 CNVI_WT_CLK_DP; 2 CNVI_WT_CLK_DN; 2 CNVI_WT_DATA1_DN; 2 CNVI_WT_DATA1_DP; 2 CNVI_WT_DATA0_DN; 2 CNVI_WT_DATA0_DP; 2 PCIE_TX4_DP; 2 PCIE_TX4_DN; 2 PCIE_RX4_DP; 2 PCIE_RX4_DN; 2 SRCCLKREQ3_3P3V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

5A

@

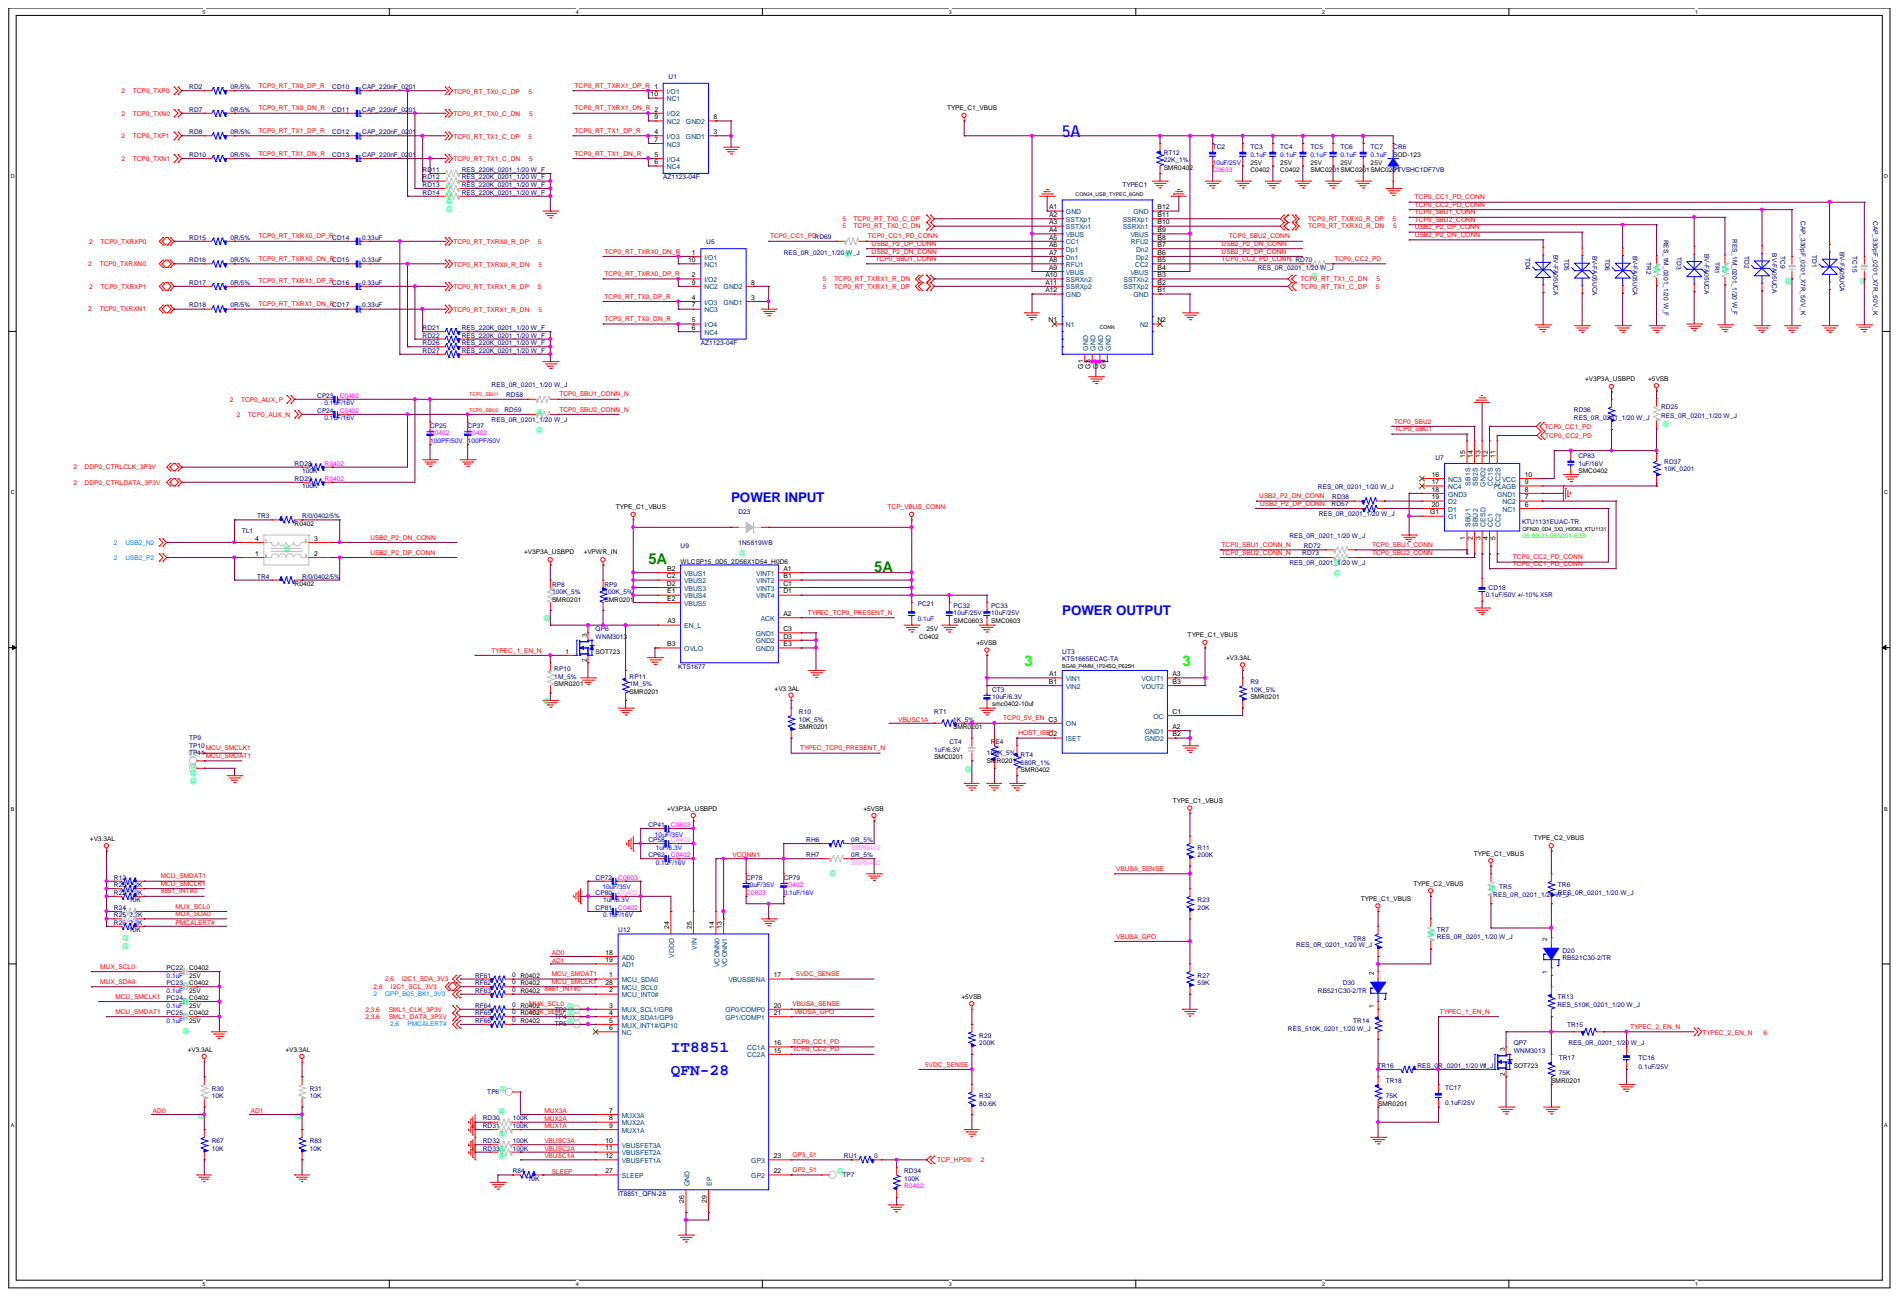
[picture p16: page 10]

D | D

+5VS

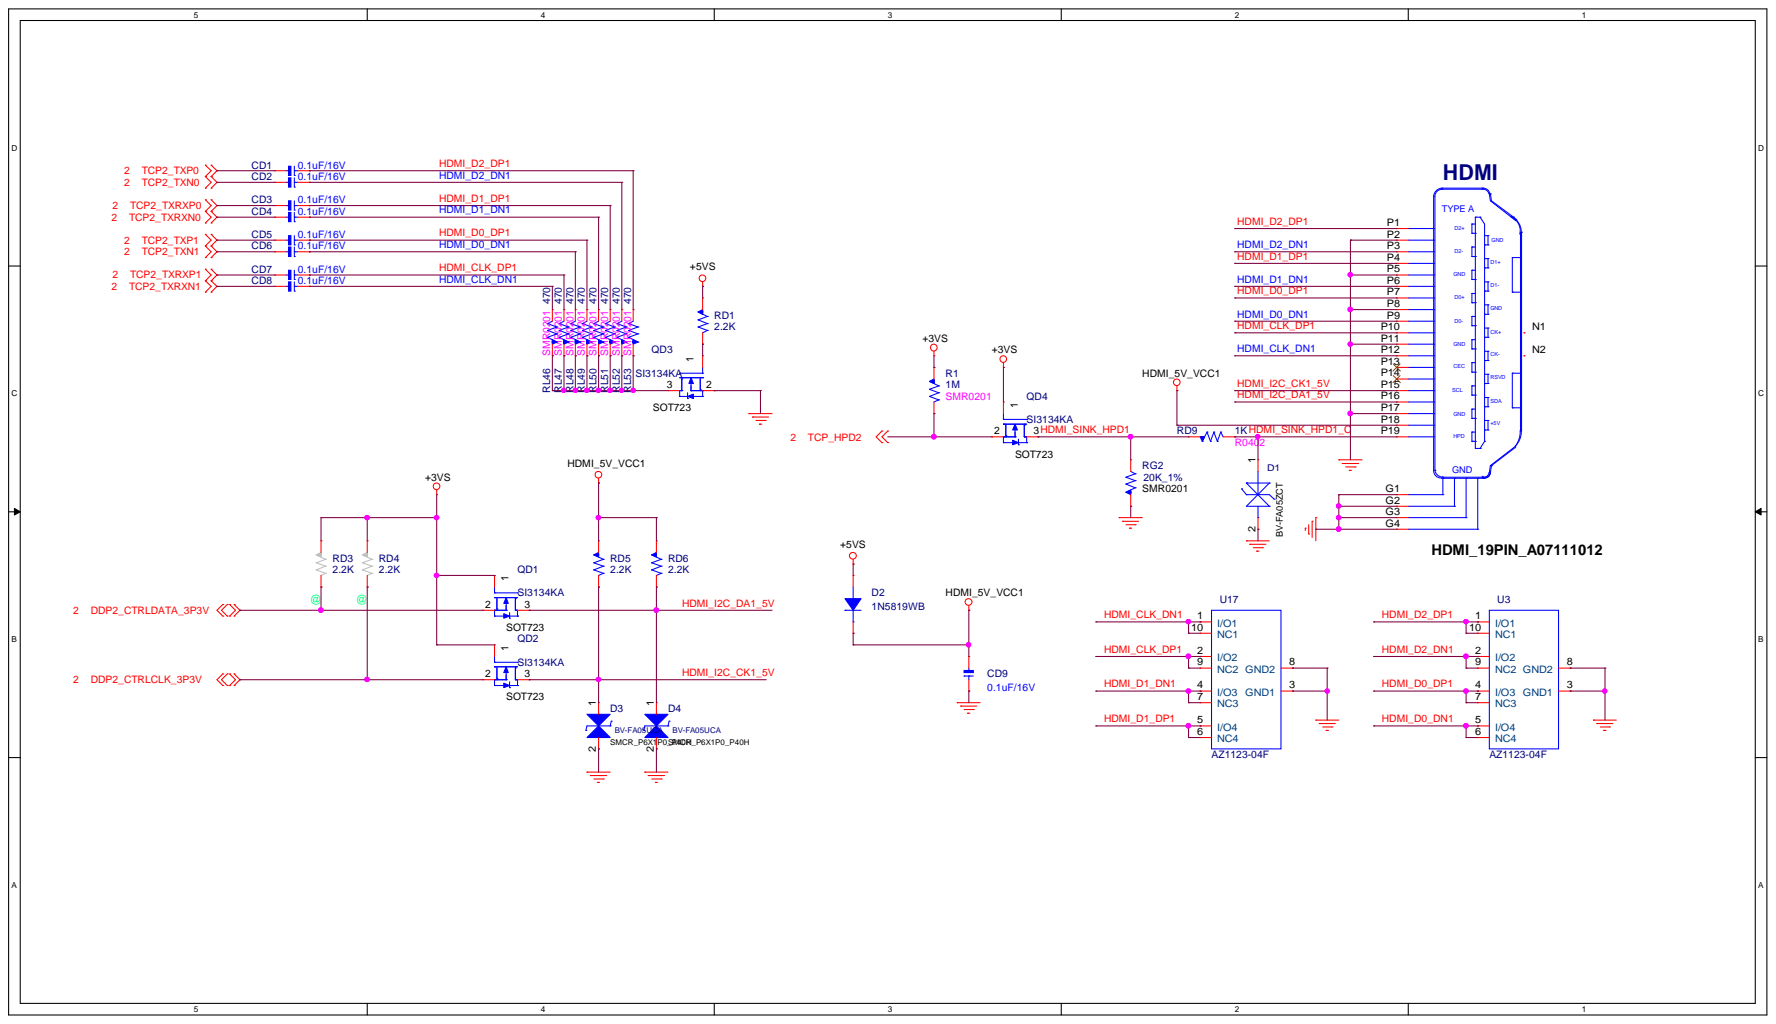
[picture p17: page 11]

D | D
1A | 1.5A

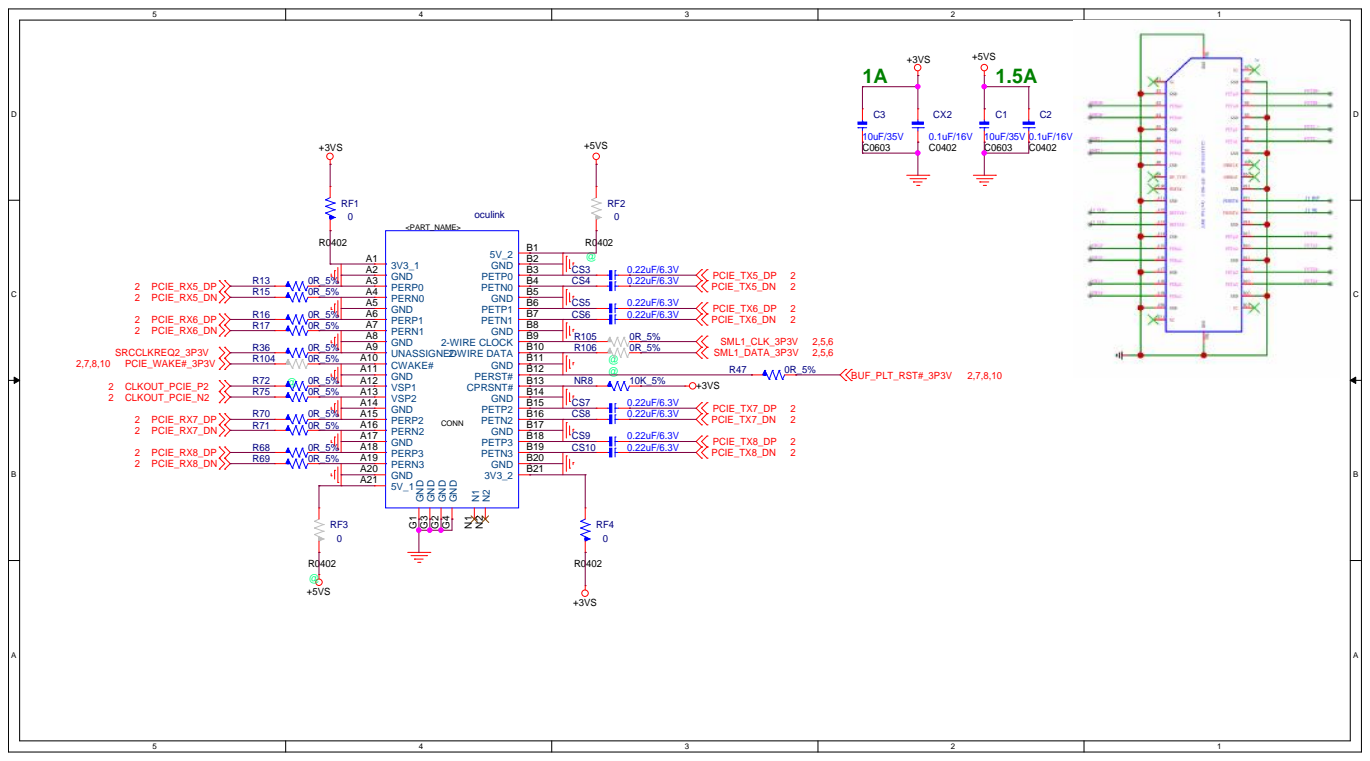
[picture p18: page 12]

VSP1 A12 GND A11 CWAKE# A10 UNASSIGNED A9 GND A8 PERN1 A7 PERP1 A6 GND A5 PERN0 A4 PERP0 A3 GND A2 3V3_1

# DDR4 SODIMM H=9.2/5.2 COLAY 9.2 default


5A

# Z1123-04F I/O1


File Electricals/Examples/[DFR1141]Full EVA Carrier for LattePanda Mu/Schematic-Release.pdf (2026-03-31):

# Block Diagram

# DDR4 SODIMM CON

USB2.0; M.2 E-KEY; USB2.0(8); HSIO3(PCIE_4); CPU_FAN; FRONT PANEL; SYS_FAN; HSIO1(PCIE_2/USB3.0_2); USB3.0 HUB VL817S; R_USB1; USB2.0(4); USB2.0(3); USB2.0(2); HDMI Port TCP1; TCP0; DDIB; TYPEC Port; DP++ Port; SATA PORT 1; SATA PORT 2; HSIO10(SATA0); LAN2; Giga LAN Port1(RJ45); PCIEX1; LAN1; Giga LAN Port2(RJ45); POE; Realtek ALC269; Mic-in; Line-out; Audio Codec; F_AUDIO; HDA; M.2 B-KEY; SPEAKER; PCIe x1 Slot; PCIe x4 Slot; HSIO8-11(PCIE9-12); HSIO11(SATA1); I2S_CON; GPIO; GPIO_CON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

X2 MUX IC SWITCH

MUX IC SWITCH

D | D

# MB HOLE

GND_AUD; MH4 150 Drill / 360Pad MHOLE12_D157_25-17-20; FMK4; FMARKC @; MH1 150 Drill / 360Pad MHOLE12_D157_25-17-20; FMK1; MH2 150 Drill / 360Pad MHOLE12_D157_25-17-20; 150 Drill / 244Pad; FMK2; FMK3; MH3 150 Drill / 360Pad MHOLE12_D157_25-17-20; Release Edition

# Power

1.2V/3A

R_USB2; UpstreamUSB; Near Pin 20; Near Pin 21; External Signal; Near Pin 38; HUB; Reset; Near L10; Near PIN_39; Crystal; R_USB3; VREF=0.807V; BUS_5V; BUS_5V DC¹_1V_R; DC³_3V_R; DC¹_1V_R; +5VSB; USB3_HUB2_TX_DP; USB3_HUB2_TX_DN; USB3_HUB2_RX_DN; USB3_HUB2_RX_DP; USB2_HUB2_N; USB2_HUB2_P; USB3_HUB1_TX_DP; USB3_HUB1_TX_DN; USB3_HUB1_RX_DN; USB3_HUB1_RX_DP; USB2_HUB1_N; USB2_HUB1_P; USB3_HUB3_TX_DN; USB3_HUB3_TX_DP; USB2_HUB3_P; USB2_HUB3_N; USB3_HUB3_RX_DP; USB3_HUB3_RX_DN; USB3_HUB4_RX_DN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

Vout = 0.8*(1+Rt/Rb)

SPI Flash ROM

12A

8A


RLIMIT = (ILIMIT x RDS(ON)) x 8 / 10μA

15A

15A


# DEFAULT 2-3

G


1.5A

2A


D | D

# MAIN BIOS


# INTEL FOXVILLE

## 1 must be connected to the PCH SMLINK0 for supporting vPro


2 for non-vpro or standard PCIE LAN,smbus is not required(pull up 10k to 3.3v_LAN)

YELLOW
Speed:1G/2.5G solid On,10M/100M solid Off
GREEN
Link&Act:solid On or Blinking

# D29ESD⁹N⁵B⁻²/TR

## LINE1-R 24

Key; MIC_L; MIC_R; JACK; LINE_R; LINE_L; AGND; MIC-JD; LINE-JD; ANALOG; DIGITAL; Interface; SPEAKER; 4 OHM==== 30MIL; GND_AUD; GND_AUDGND_AUD; +5VSB; 2 HDA_SDOUT_I2S0_TXD; 2 HDA_RST_I2S2_SCLK; 2 HDA_SYNC_I2S0_SFRM; 2 HDA_BCLK_I2S0_SCLK; 2 HDA_SDIN_I2S0_RXD; D32ESD⁹N⁵B⁻²/TR; 0.1uF SMC0201 16V; AFB1; 30 Ohm; AR26 20K_5% SMR0201; SMC0201; ALC269Q-VB6-CG; LCC48_P4MM_SQ6MM_1P0H; DVDD1; GPIO0/DMIC-DATA; GPIO1/DMIC-CLK; SDATA-OUT; BIT-CLK; DVSS2; SDATA-IN; DVDD-IO; SYNC 10; RESET# 11; PCBEEP 12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

Spilt by DGND

Place next to pin 39

(Include Thermal pad)

De-pop Solution

# SIO UART

C1+


3 | RF39 0
4 | | RF40 0

3A

# M.2_BKEY H=4.2


Follow EMC Request ADD RC

NGFF SOCKET(M.2) RVS B KEY

SATA - GND; PCIE - NC

# KEY E REV=1

## GND


# HDMI_CON2

+5VS


D | D

# HDMI_CON1


# PCIEX4

1A


D | D

# MIPI CSI Connector 22PIN


# DDR4 SODIMM H=9.2/5.2 COLAY 9.2 default


# 3A OUTPUT

# TCP-1 DIRECT (CMC, ESD, CONNECTOR)


GP8/9/10 only have open-drain ability
& no tri-state.

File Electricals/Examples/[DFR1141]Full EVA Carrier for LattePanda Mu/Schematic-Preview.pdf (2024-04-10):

D | D

# MB HOLE

Preview Edition; GND_AUD; 150 Drill / 244Pad; MH2 150 Drill / 360Pad MHOLE12_D157_25-17-20; MH1 150 Drill / 360Pad MHOLE12_D157_25-17-20; MH4 150 Drill / 360Pad MHOLE12_D157_25-17-20; FMK3; FMARKC @; FMK1; FMK2; MH3 150 Drill / 360Pad MHOLE12_D157_25-17-20; FMK4; LattePanda Team

Full EVA Carrier for LattePanda Mu - Preview Edition

## UpstreamUSB

# External Signal

Preview Edition; R_USB2; MCU; Crystal; R_USB3; BUS_5V; BUS_5V DC¹_1V_R; DC³_3V_R; DC¹_1V_R; +5VSB; USB3_HUB2_TX_DP; USB3_HUB2_TX_DN; USB3_HUB2_RX_DN; USB3_HUB2_RX_DP; USB2_HUB2_N; USB2_HUB2_P; USB3_HUB1_TX_DP; USB3_HUB1_TX_DN; USB3_HUB1_RX_DN; USB3_HUB1_RX_DP; USB2_HUB1_N; USB2_HUB1_P; USB3_HUB3_TX_DN; USB3_HUB3_TX_DP; USB2_HUB3_P; USB2_HUB3_N; USB3_HUB3_RX_DP; USB3_HUB3_RX_DN; USB3_HUB4_RX_DN; USB3_HUB4_TX_DN; USB3_HUB4_TX_DP; USB2_HUB4_P; USB2_HUB4_N; USB3_HUB4_RX_DP; HSIO1_RX_P; HSIO1_RX_N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

Vout = 0.8*(1+Rt/Rb)

SPI Flash ROM

@

@


RLIMIT = (ILIMIT x RDS(ON)) x 8 / 10μA

## +VDC +VDC_IN

## +5VSB


# DEFAULT 2-3

G


1.5A

2A


D | D
+V3.3AL | +VCC_SPI_FLASH


# INTEL FOXVILLE INTEL FOXVILLE


# D165ESD⁹N⁵B⁻²/TR

## LINE1-R 24

Preview Edition; Key; GND_AUD; GND_AUDGND_AUD; +5VSB; 2 HDA_SDOUT_I2S0_TXD; 2 HDA_RST_I2S2_SCLK; 2 HDA_SYNC_I2S0_SFRM; 2 HDA_BCLK_I2S0_SCLK; 2 HDA_SDIN_I2S0_RXD; AR26 20K_5% SMR0201; SMR0201; AC1 1uF/6.3V SMC0201; SOT723; D32ESD⁹N⁵B⁻²/TR; SPEAKER; AR27 20K_5% SMR0201; AFB2; 30 Ohm; D166ESD⁹N⁵B⁻²/TR; 0.1uF SMC0201 16V; D31ESD⁹N⁵B⁻²/TR; SMC0201; AR25 20K_5% SMR0201; AFB3; AC4 1uF/6.3V SMC0201; AR16 2.2K SMR0201; AD1 BAT54A; ALC269Q-VB6-CG; LCC48_P4MM_SQ6MM_1P0H; DVDD1; GPIO0/DMIC-DATA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

# SIO UART

C1+


3A

# M.2_BKEY H=4.2


# KEY E REV=1

## GND


# HDMI_CON2

+5VS


D | D

# HDMI_CON1


# PCIEX4

1A


44

33


# R0402 PQ13

@


@

@


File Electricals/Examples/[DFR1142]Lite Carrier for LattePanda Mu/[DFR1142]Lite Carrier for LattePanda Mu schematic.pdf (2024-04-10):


Gigabit Ethernet File: Gigabit Ethernet.kicad_sch FAN_1_TAC
File: PSU.kicad_sch PCIE_RX_3- PCIE_RX_2- PCIE_RX_3+ PCIE_RX_0- PCIE_RX_1- PCIE_RX_1+ PCIE_RX_0+ PCIE_RX_2+
~{WAKE} PCIe x4 File: PCIe x4.kicad_sch USB3_SSRX_P USB3_SSRX_N
~{PLT_RST} REFCLK- REFCLK+ PCIE_TX_3- PCIE_TX_3+ PCIE_TX_2- PCIE_TX_0+ PCIE_TX_2+ PCIE_TX_1- PCIE_TX_0- PCIE_TX_1+

~{PLT_RST}
~{PWR_LED}/~{PSON} HDMI File: HDMI.kicad_sch GbE_PCIe_CLK- GbE_PCIe_RX+ GbE_PCIe_RX- GbE_PCIe_TX- GbE_PCIe_TX+ GbE_PCIe_CLK+


- S5 (Soft Off): LOW HSIO functions are defined by the BIOS source code,

Cannot be changed in BIOS settings.

Aux Signals SMBus SMLink SPI

Before starting design, you should choose one of
https://github.com/LattePandaTeam/LattePanda-Mu
Or contact techsupport for custom your BIOS

USB2_P6 is reserved for TypeC PD Controller DO NOT use it as a normal USB HPD pin of unused DDI/TCP port needs to be pulled down DDI/TCP functions are defined by the BIOS source code,
The default functions are defined as follows:

Cannot be used as a general SPI interface. Lite Carrier has no second BIOS ROM

- DDIA: eDP 1.4b (the 40Pin connector on the Mu)

- TCP1: USB TypeC (need external PD controller)

HPD pin of unused DDI/TCP port needs to be pulled down



File: HDMI.kicad_sch Sheet: /HDMI/ DFRobot




File: GPIO.kicad_sch Sheet: /GPIO/ DFRobot


2 PETn2 23 PETp2 25 PERn1 29 PERp1 31 PETn1 35 PETp1 37 DEVSLP 38 PERn0/SATA-B+ 41 PERp0/SATA-B- 43 PETn0/SATA-A- 47 PETp0/SATA-A+ 49 PERn3 5 ~{PERST} 50 ~{CLKREQ} 52 REFCLKn 53


Power for PCIe x4 OVP@13.86V

PCIe Power Enable LED

1 GND
File: PSU.kicad_sch Sheet: /PSU/ DFRobot C83 22uF/10V


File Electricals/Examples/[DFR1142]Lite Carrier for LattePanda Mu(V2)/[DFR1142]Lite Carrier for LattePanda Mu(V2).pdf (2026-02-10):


Gigabit Ethernet File: Gigabit Ethernet.kicad_sch ~{PWR_LED}/~{PSON}

~{PLT_RST}
~{PWR_LED}/~{PSON} HDMI File: HDMI.kicad_sch


Cannot be changed in BIOS menu.

Aux Signals USB 2.0 GPIO

Before starting design, you should choose one of
https://github.com/LattePandaTeam/LattePanda-Mu

SPI Audio MIPI CSI-2

- TCP1: USB TypeC (need external PD controller)



8 CKS 11 GND 17 SH SH

File: HDMI.kicad_sch Sheet: /HDMI/ DFRobot HDJ DFR1142


File: USB2.0&USB3.0.kicad_sch Sheet: /USB2.0&USB3.0/ DFRobot HDJ DFR1142



File: GPIO.kicad_sch Sheet: /GPIO/ DFRobot HDJ DFR1142


1 DAS/~{DSS}/~{LED1} 10 PEDET 69 SUSCLK 68 GND

1 DAS/~{DSS}/~{LED1} 10 PEDET 69 SUSCLK 68

To be grounded for SATA, No Connect for PCIe


Power for PCIe x4 OVP@13.86V
21.5K/1% U13 TL431DBZ R42

File: PSU.kicad_sch Sheet: /PSU/ DFRobot HDJ DFR1142


File: fan_temp.kicad_sch Sheet: /Fan_Temp/ DFRobot HDJ DFR1142







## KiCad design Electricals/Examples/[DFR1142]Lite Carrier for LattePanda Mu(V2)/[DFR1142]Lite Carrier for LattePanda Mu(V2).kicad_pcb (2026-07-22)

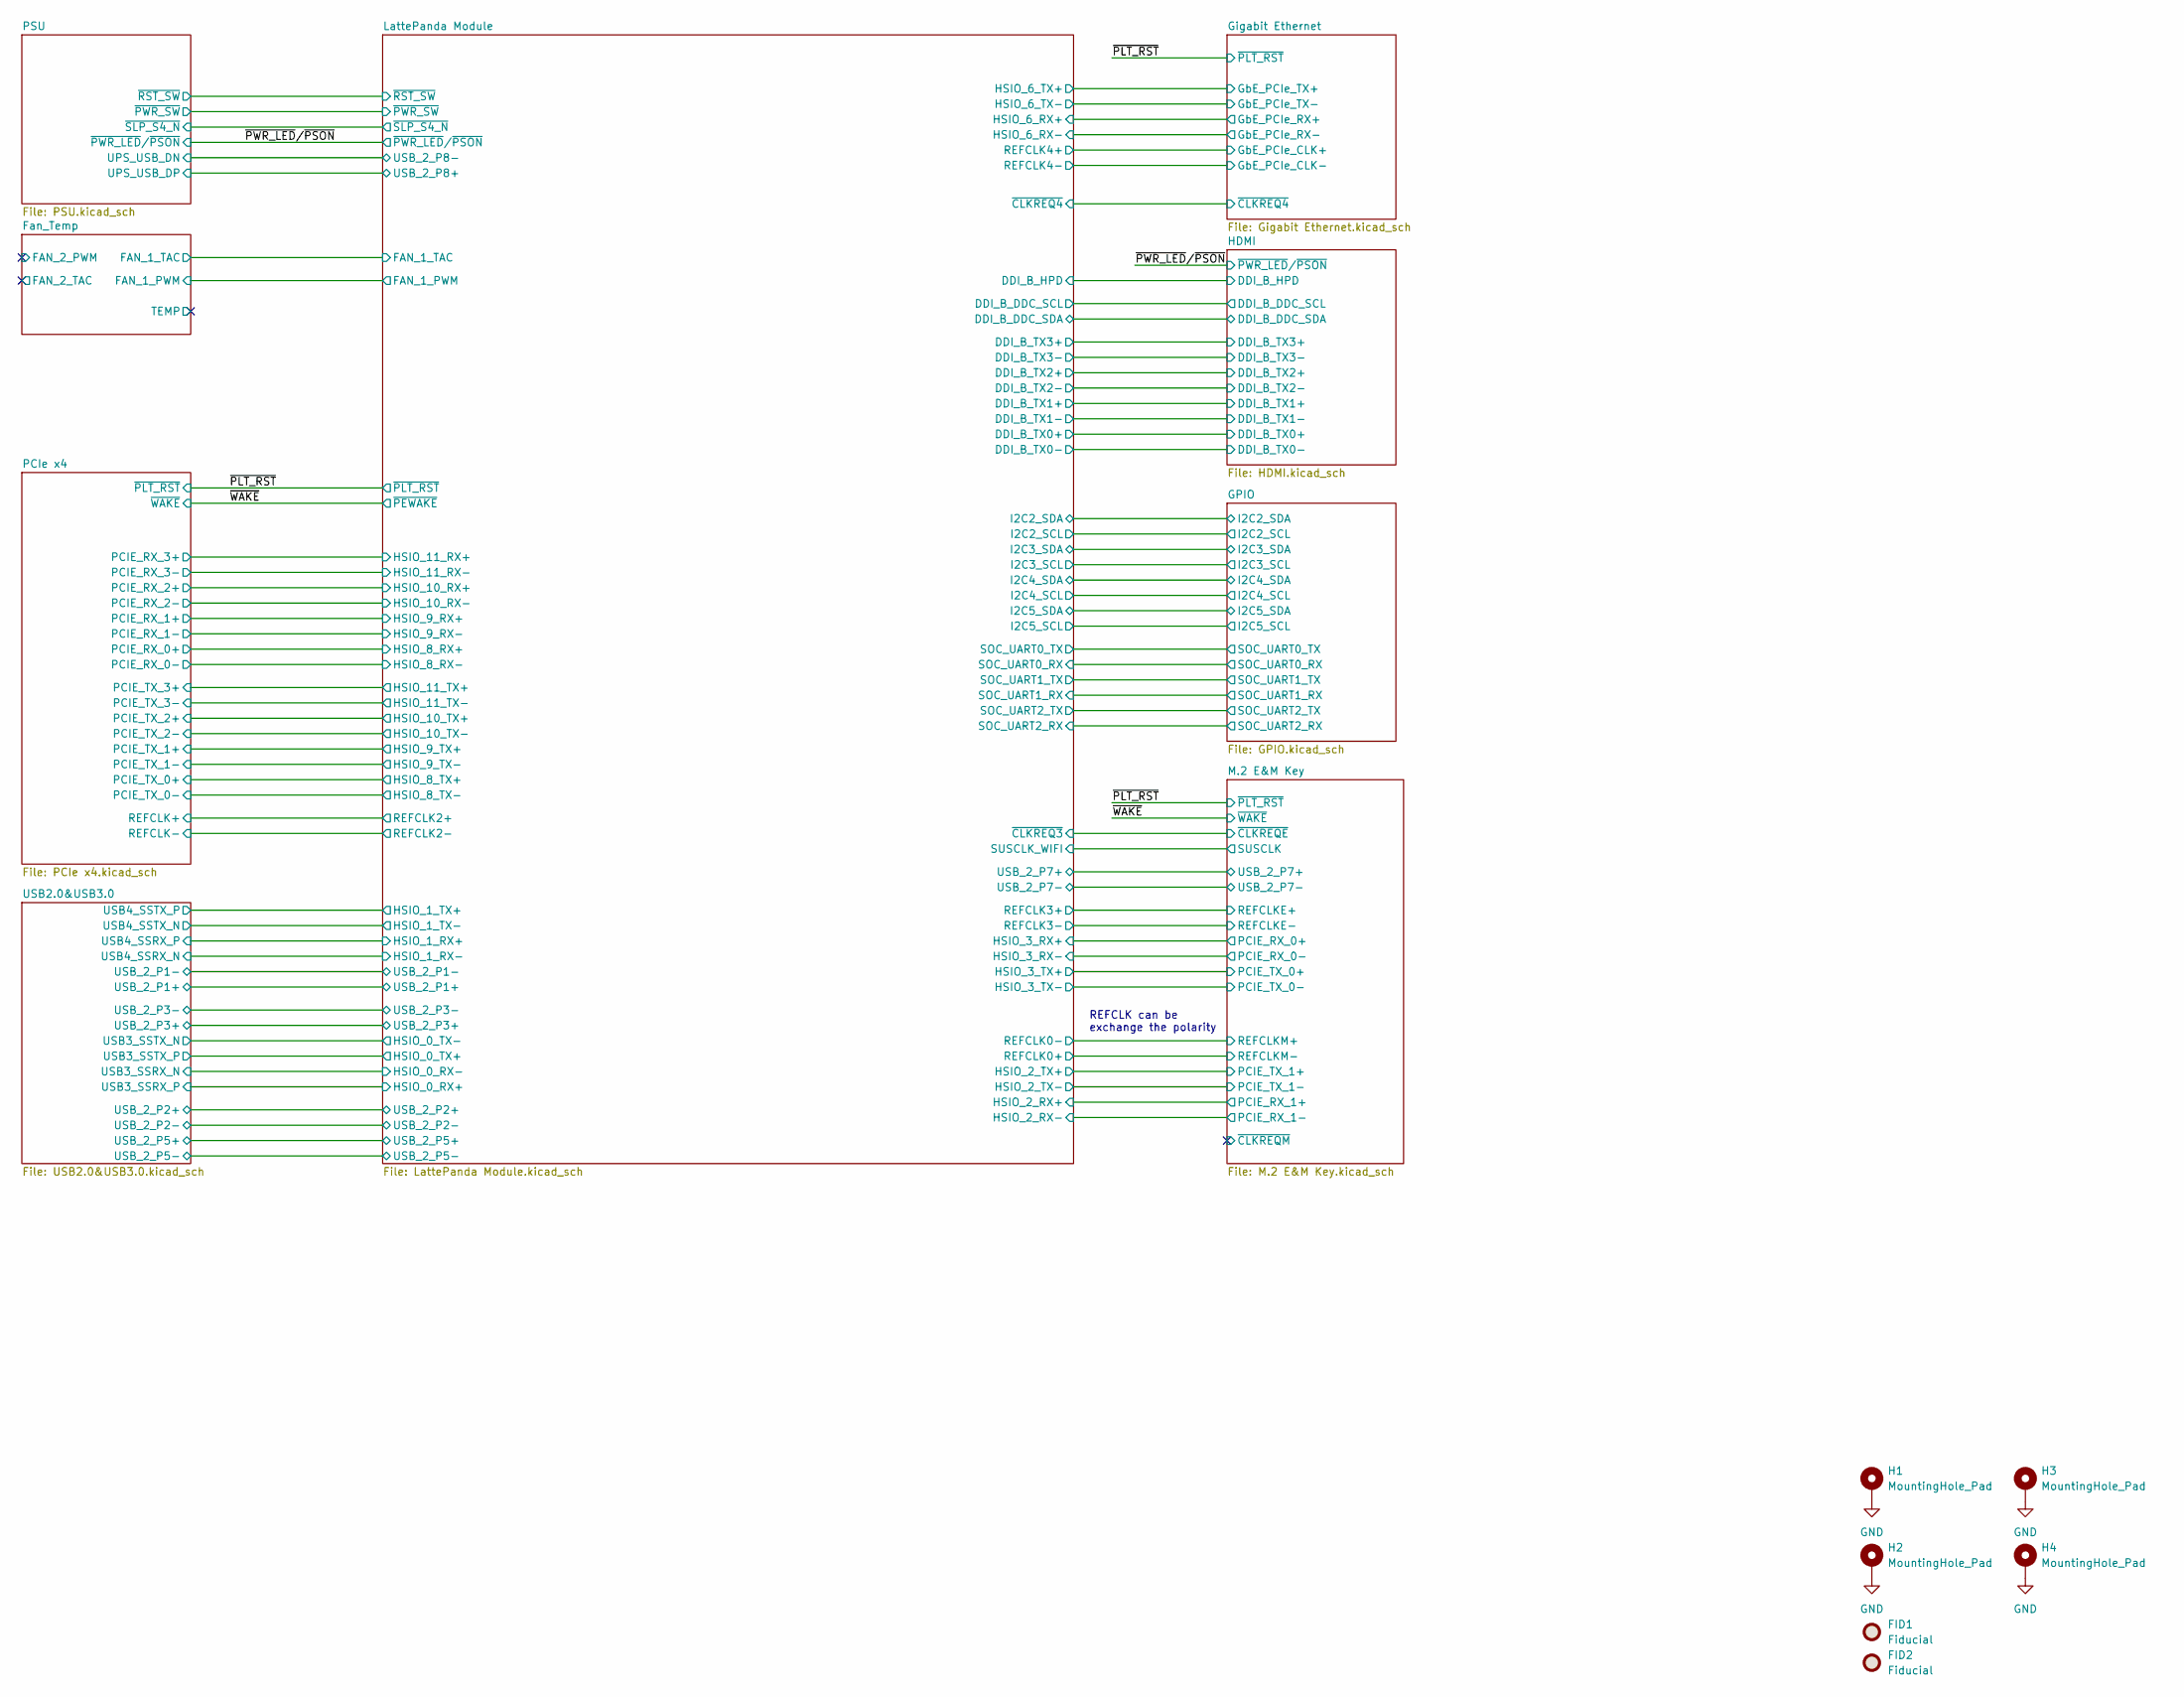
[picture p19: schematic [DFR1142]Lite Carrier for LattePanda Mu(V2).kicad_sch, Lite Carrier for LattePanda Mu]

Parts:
FID1, FID2: Fiducial; Fiducial_1mm_Mask2mm
H1, H2, H3, H4: MountingHole_Pad; MountingHole_3.2mm_M3_Pad_Via

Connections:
GND: H1.1, H2.1, H3.1, H4.1; also elsewhere on the board

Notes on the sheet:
REFCLK can be exchange the polarity

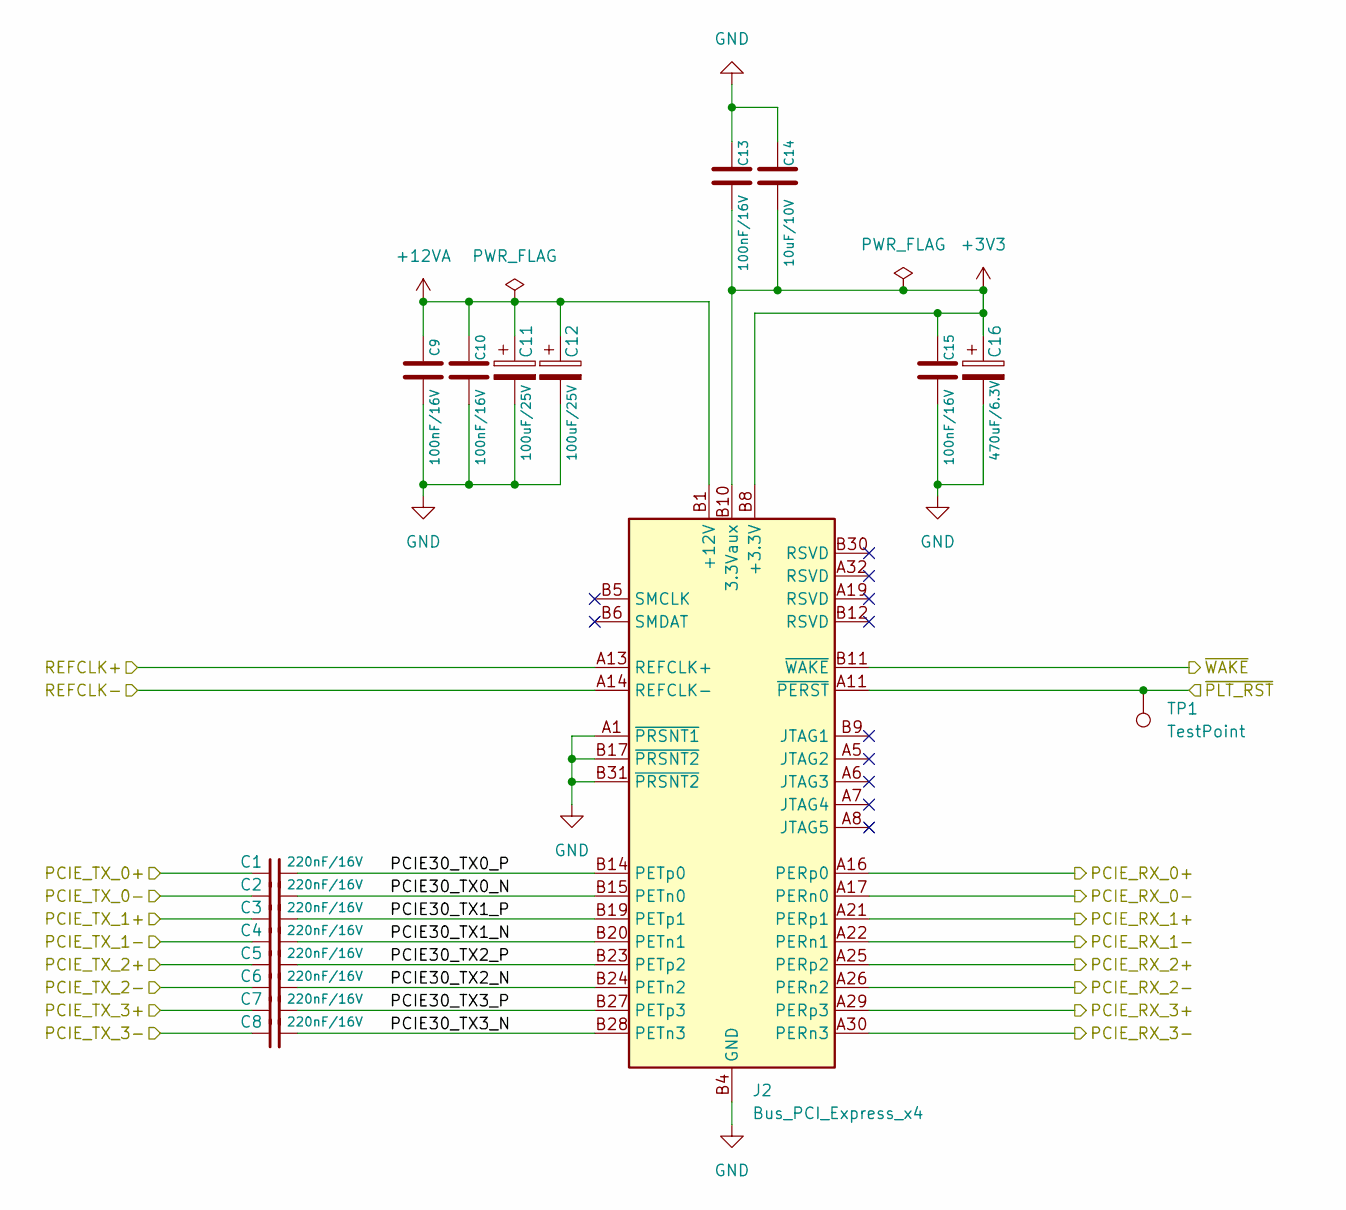
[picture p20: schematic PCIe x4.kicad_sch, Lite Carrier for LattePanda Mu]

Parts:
C1, C2, C3, C4, C5, C6, C7, C8: 220nF/16V; C_0402_1005Metric
C9, C10, C13, C15: 100nF/16V; C_0402_1005Metric
C11, C12: 100uF/25V; CP_Elec_6.3x7.7
C14: 10uF/10V; C_0402_1005Metric
C16: 470uF/6.3V; CP_Elec_6.3x7.7
J2: Bus_PCI_Express_x4; PCIe_x4_Gen3Slot_Connectors
TP1: TestPoint; TestPoint_Pad_D1.5mm

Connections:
+3V3: C13.2, C14.2, C15.1, C16.1, J2.A9 (+3.3V), J2.A10 (+3.3V), J2.B8 (+3.3V), J2.B10 (3.3Vaux); also elsewhere on the board
+12VA: C9.1, C10.1, C11.1, C12.1, J2.A2 (+12V), J2.A3 (+12V), J2.B1 (+12V), J2.B2 (+12V), J2.B3 (+12V); also elsewhere on the board
/LattePanda Module/HSIO_8_RX+: J2.A16 (PERp0); also elsewhere on the board
/LattePanda Module/HSIO_8_RX-: J2.A17 (PERn0); also elsewhere on the board
/LattePanda Module/HSIO_8_TX+: C1.1; also elsewhere on the board
/LattePanda Module/HSIO_8_TX-: C2.1; also elsewhere on the board
/LattePanda Module/HSIO_9_RX+: J2.A21 (PERp1); also elsewhere on the board
/LattePanda Module/HSIO_9_RX-: J2.A22 (PERn1); also elsewhere on the board
/LattePanda Module/HSIO_9_TX+: C3.1; also elsewhere on the board
/LattePanda Module/HSIO_9_TX-: C4.1; also elsewhere on the board
/LattePanda Module/HSIO_10_RX+: J2.A25 (PERp2); also elsewhere on the board
/LattePanda Module/HSIO_10_RX-: J2.A26 (PERn2); also elsewhere on the board
/LattePanda Module/HSIO_10_TX+: C5.1; also elsewhere on the board
/LattePanda Module/HSIO_10_TX-: C6.1; also elsewhere on the board
/LattePanda Module/HSIO_11_RX+: J2.A29 (PERp3); also elsewhere on the board
/LattePanda Module/HSIO_11_RX-: J2.A30 (PERn3); also elsewhere on the board
/LattePanda Module/HSIO_11_TX+: C7.1; also elsewhere on the board
/LattePanda Module/HSIO_11_TX-: C8.1; also elsewhere on the board
/LattePanda Module/REFCLK2+: J2.A13 (REFCLK+); also elsewhere on the board
/LattePanda Module/REFCLK2-: J2.A14 (REFCLK-); also elsewhere on the board
/PCIe x4/PCIE30_TX0_N: C2.2, J2.B15 (PETn0)
/PCIe x4/PCIE30_TX0_P: C1.2, J2.B14 (PETp0)
/PCIe x4/PCIE30_TX1_N: C4.2, J2.B20 (PETn1)
/PCIe x4/PCIE30_TX1_P: C3.2, J2.B19 (PETp1)
/PCIe x4/PCIE30_TX2_N: C6.2, J2.B24 (PETn2)
/PCIe x4/PCIE30_TX2_P: C5.2, J2.B23 (PETp2)
/PCIe x4/PCIE30_TX3_N: C8.2, J2.B28 (PETn3)
/PCIe x4/PCIE30_TX3_P: C7.2, J2.B27 (PETp3)
/~PLT_RST: J2.A11 (~PERST), TP1.1; also elsewhere on the board
/~WAKE: J2.B11 (~WAKE); also elsewhere on the board
GND: C9.2, C10.2, C11.2, C12.2, C13.1, C14.1, C15.2, C16.2, J2.A1 (~PRSNT1), J2.A4 (GND), J2.A12 (GND), J2.A15 (GND), J2.A18 (GND), J2.A20 (GND), J2.A23 (GND), J2.A24 (GND), J2.A27 (GND), J2.A28 (GND), J2.A31 (GND), J2.B4 (GND), J2.B7 (GND), J2.B13 (GND), J2.B16 (GND), J2.B17 (~PRSNT2), J2.B18 (GND), J2.B21 (GND), J2.B22 (GND), J2.B25 (GND), J2.B26 (GND), J2.B29 (GND), J2.B31 (~PRSNT2), J2.B32 (GND); also elsewhere on the board

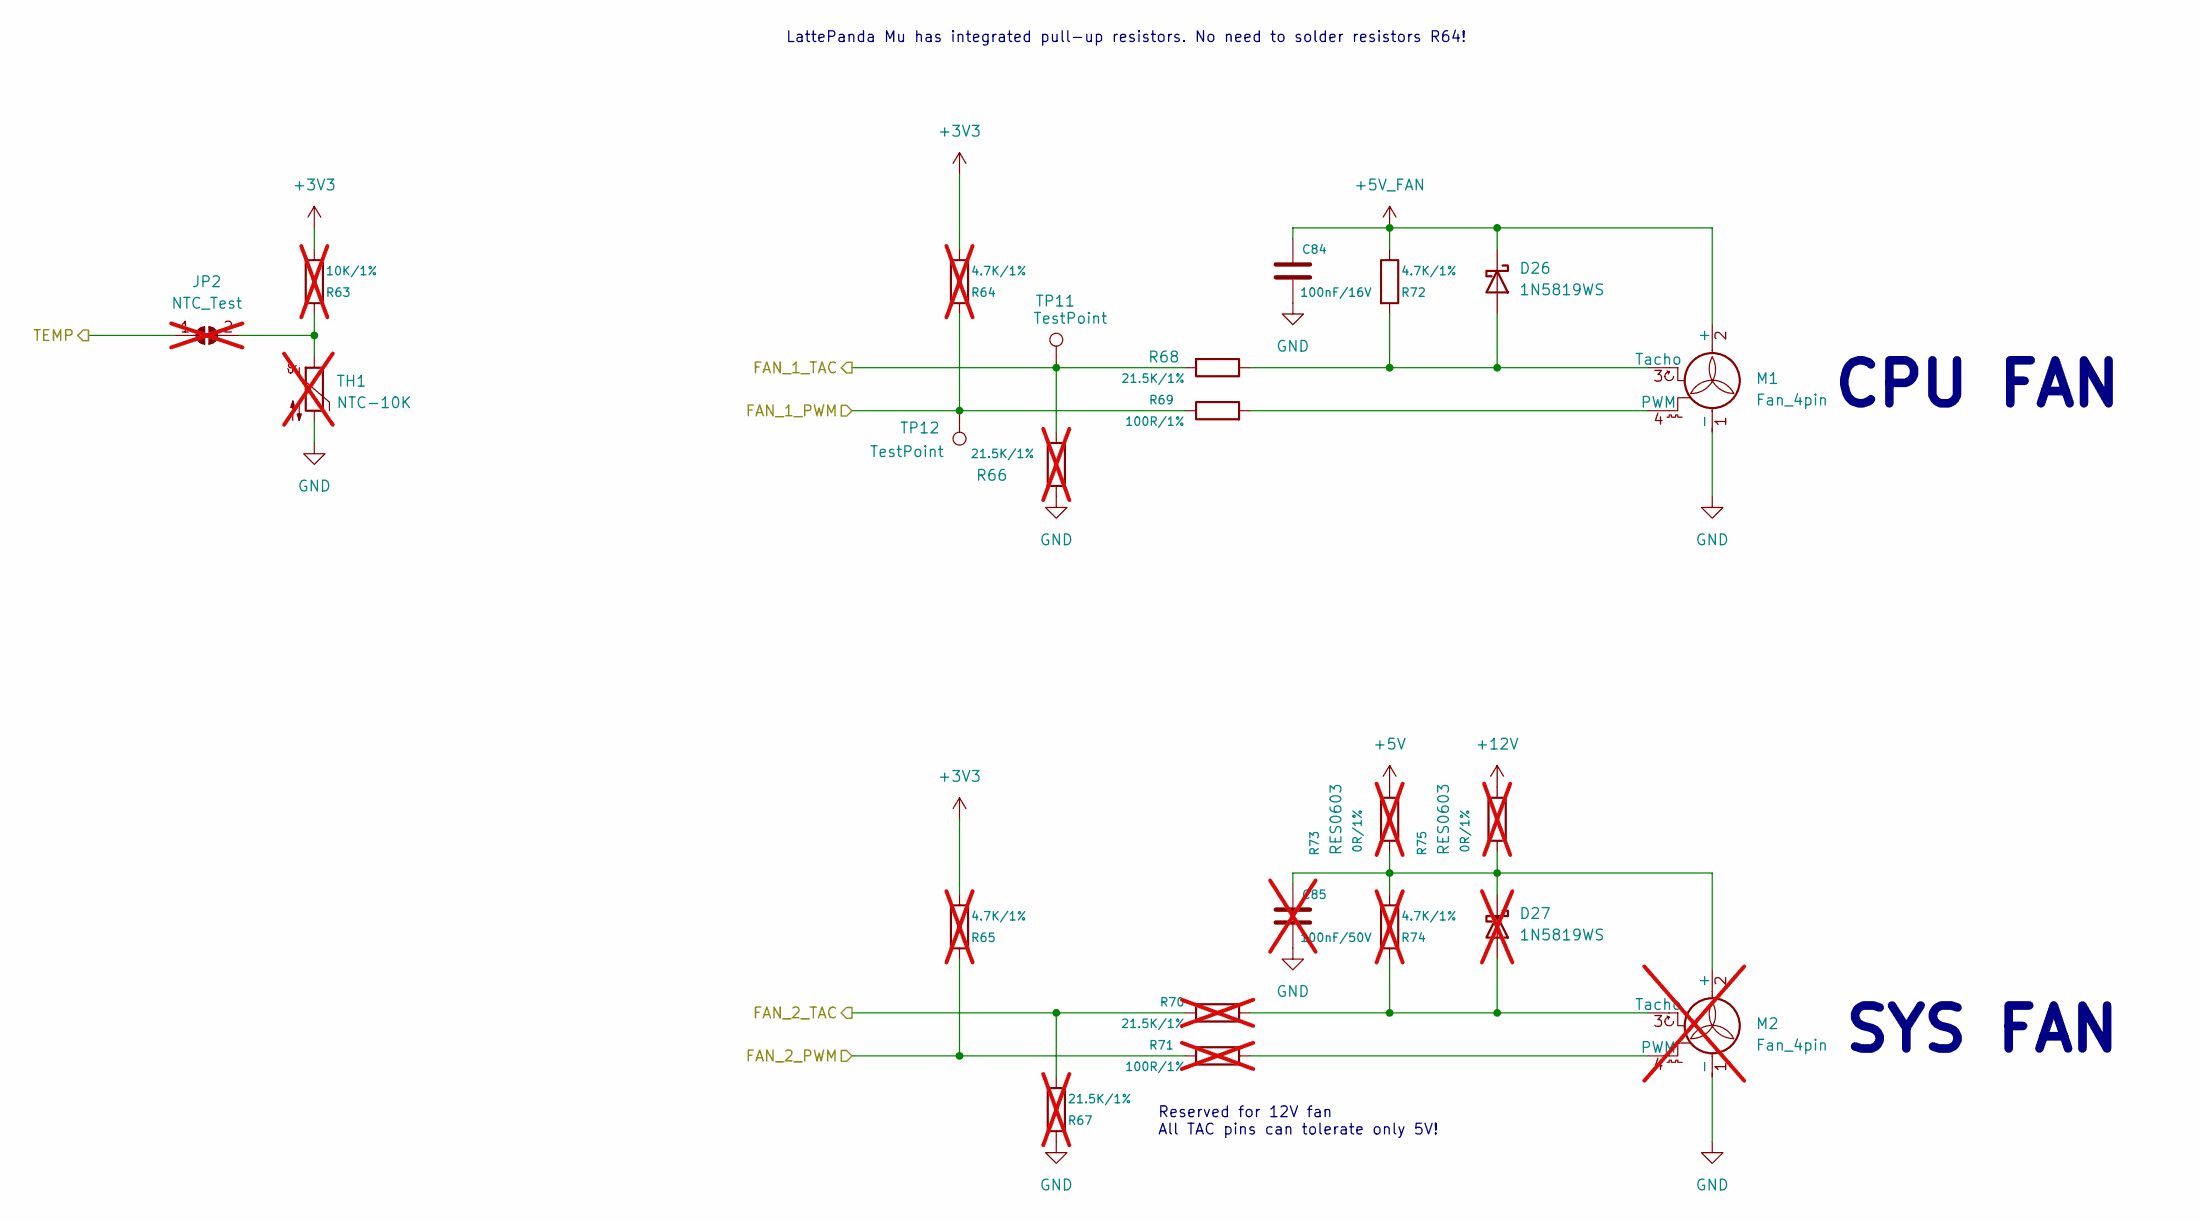
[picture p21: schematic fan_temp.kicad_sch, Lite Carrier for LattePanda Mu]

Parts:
C84: 100nF/16V; C_0402_1005Metric
C85: 100nF/50V; C_0402_1005Metric; not fitted
D26: 1N5819WS; D_SOD-323
D27: 1N5819WS; D_SOD-323; not fitted
JP2: NTC_Test; SolderJumper-2_P1.3mm_Open_RoundedPad1.0x1.5mm; not fitted
M1: Fan_4pin; JST_PH_B4B-PH-K_1x04_P2.00mm_Vertical
M2: Fan_4pin; JST_PH_B4B-PH-K_1x04_P2.00mm_Vertical; not fitted
R63: 10K/1%; R_0402_1005Metric; not fitted
R64, R65, R74: 4.7K/1%; R_0402_1005Metric; not fitted
R66, R67, R70: 21.5K/1%; R_0402_1005Metric; not fitted
R68: 21.5K/1%; R_0402
R69: 100R/1%; R_0402
R71: 100R/1%; R_0402_1005Metric; not fitted
R72: 4.7K/1%; R_0402
R73, R75: 0R/1%; RES0603; not fitted
TH1: NTC-10K; R_0603_1608Metric; not fitted
TP11, TP12: TestPoint; TestPoint_Pad_D1.5mm

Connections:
+3V3: R63.1, R64.1, R65.1; also elsewhere on the board
+5V_FAN: C84.1, D26.1 (K), M1.2 (+), R72.1; also elsewhere on the board
/Fan_Temp/FAN_1_PWM: R64.2, R69.1, TP12.1; also elsewhere on the board
/Fan_Temp/FAN_1_TAC: R66.1, R68.2, TP11.1; also elsewhere on the board
GND: C84.2, C85.2, M1.1 (-), M2.1 (-), R66.2, R67.2, TH1.2; also elsewhere on the board
unnamed: C85.1, D27.1 (K), M2.2 (+), R73.1, R74.1, R75.1
unnamed: D26.2 (A), M1.3 (Tacho), R68.1, R72.2
unnamed: D27.2 (A), M2.3 (Tacho), R70.2, R74.2
unnamed: JP2.2 (B), R63.2, TH1.1
unnamed: M1.4 (PWM), R69.2
unnamed: M2.4 (PWM), R71.2
unnamed: R65.2, R71.1
unnamed: R67.1, R70.1

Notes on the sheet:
CPU FAN
Reserved for 12V fan All TAC pins can tolerate only 5V!
SYS FAN
LattePanda Mu has integrated pull-up resistors. No need to solder resistors R64!

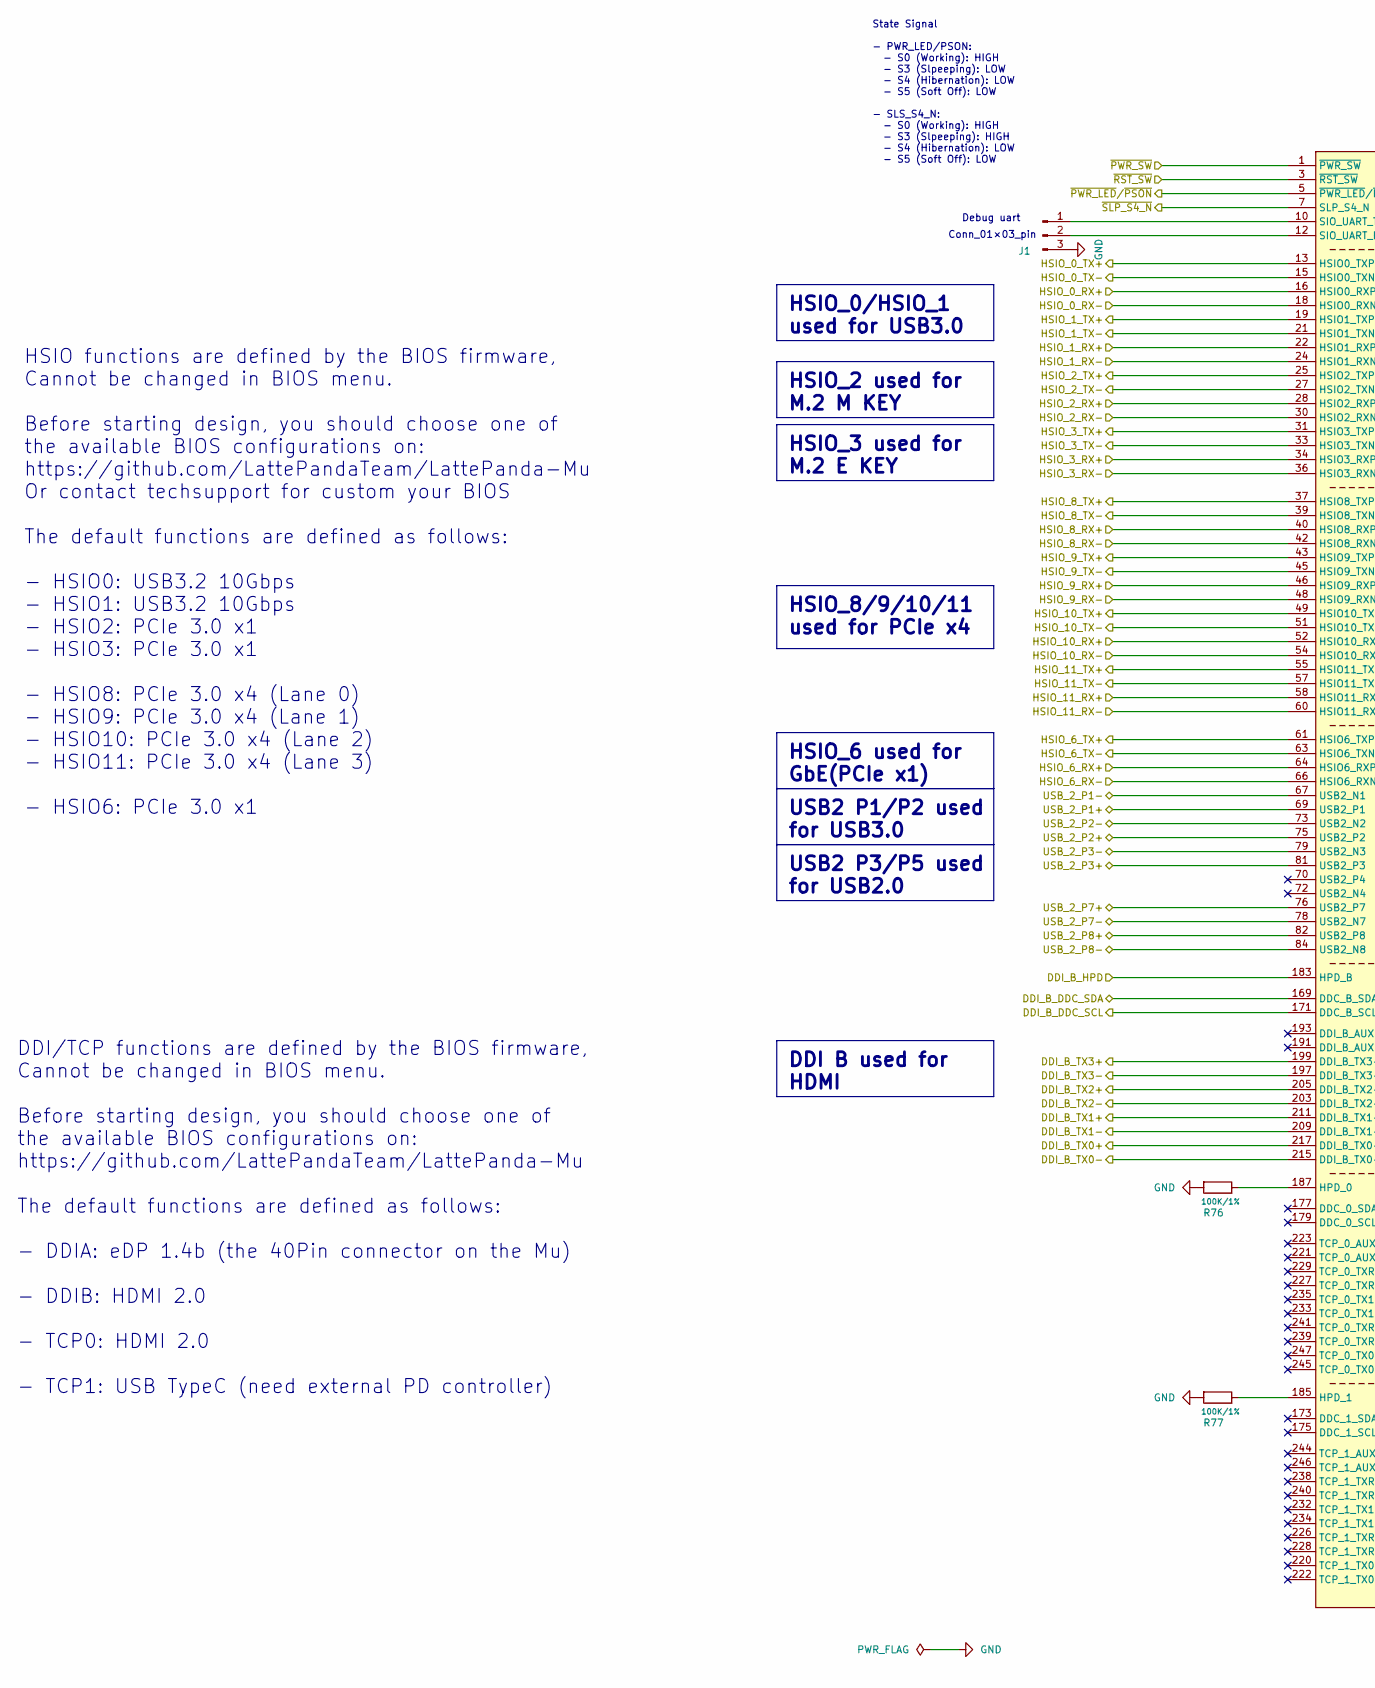
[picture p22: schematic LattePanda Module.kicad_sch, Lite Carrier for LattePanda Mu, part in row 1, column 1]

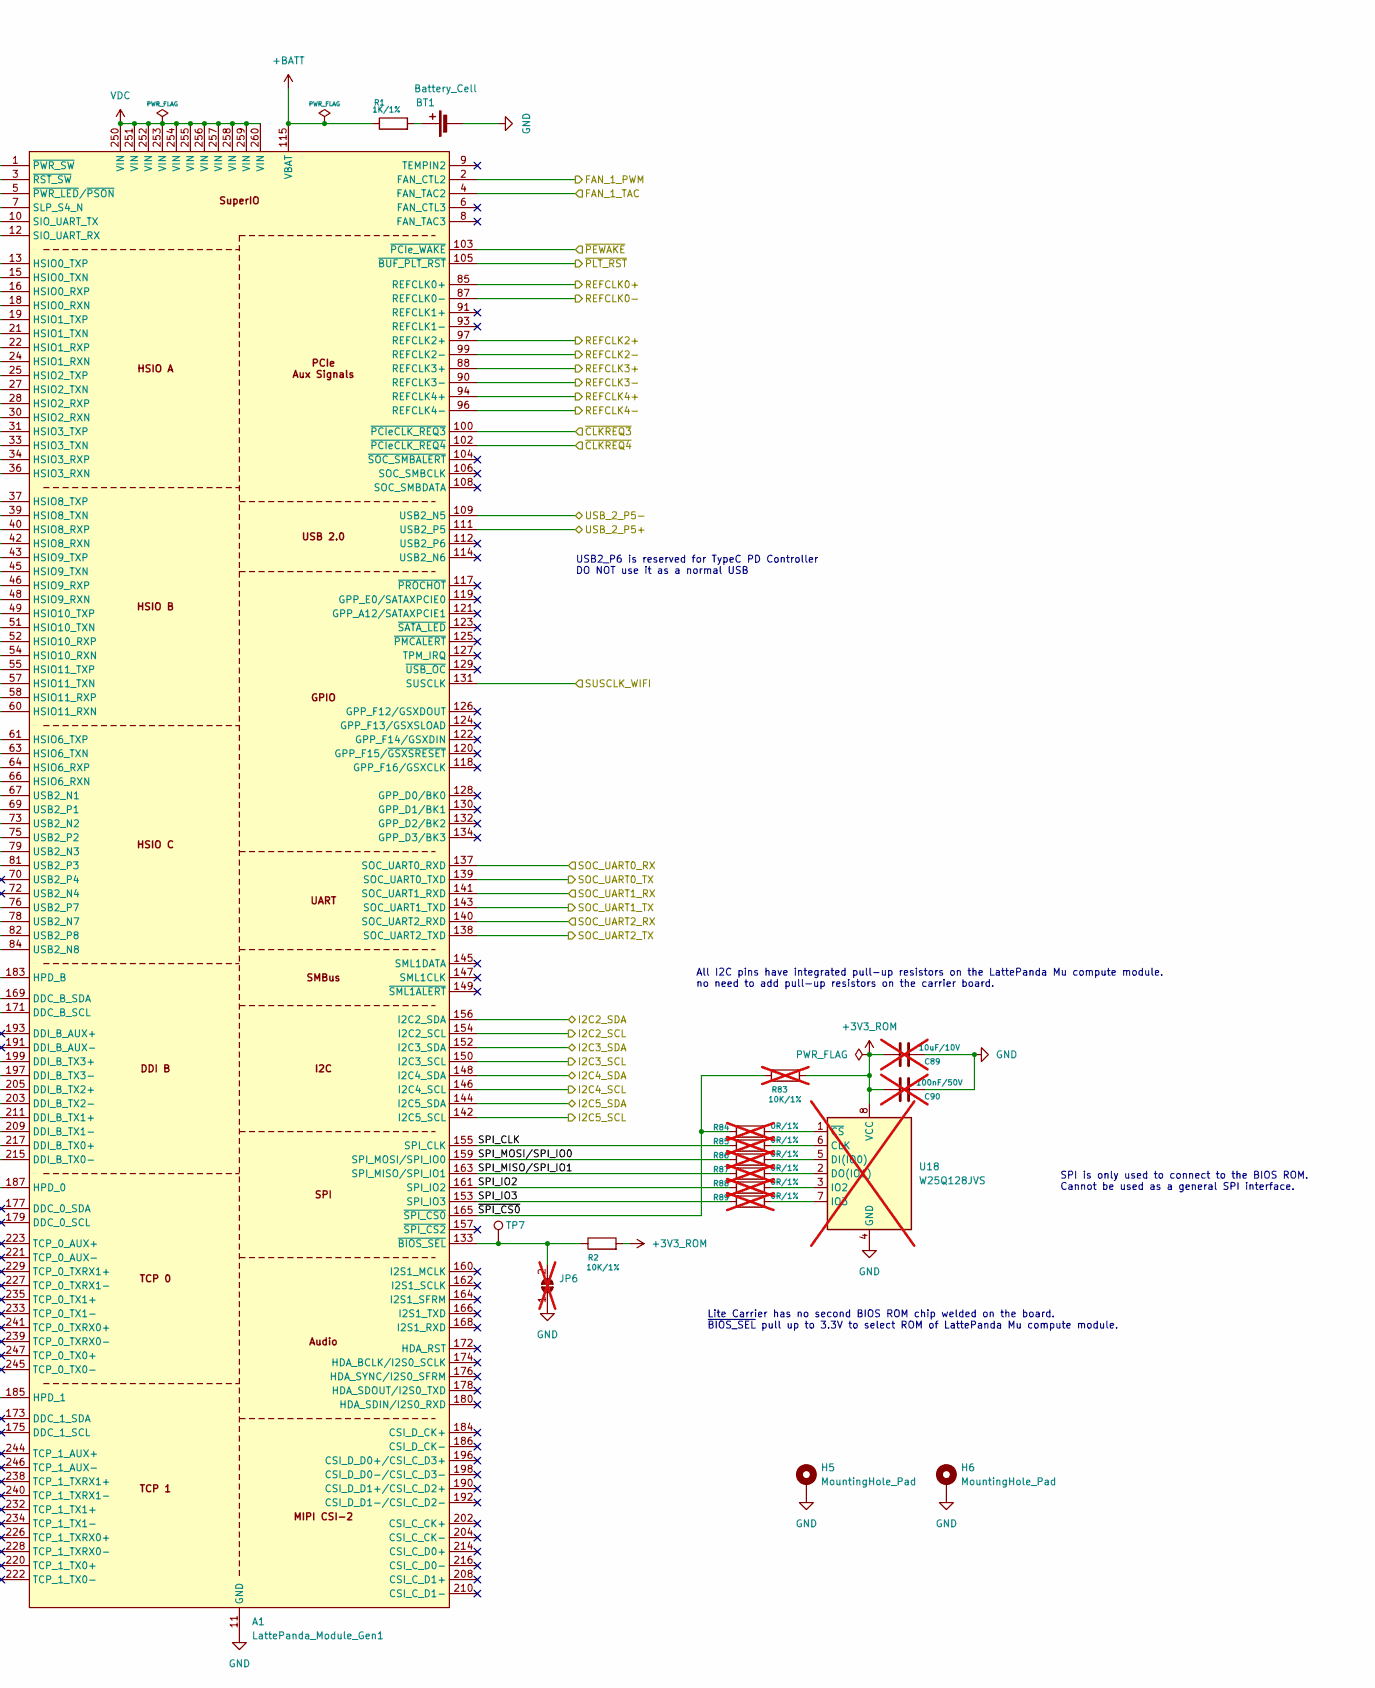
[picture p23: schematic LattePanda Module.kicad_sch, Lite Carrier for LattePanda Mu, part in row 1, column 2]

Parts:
A1: LattePanda_Module_Gen1; DDR4_SODIMM_260P_8.0H_STD
BT1: Battery_Cell; Battery_Holder_CR1220_S8411-45R
C89: 10uF/10V; C_0402; not fitted
C90: 100nF/50V; C_0402; not fitted
H5, H6: MountingHole_Pad; MountingHole_3mm_M2_Pad_TopOnly
J1: Conn_01x03_Pin; PinHeader_1x03_P2.54mm_Vertical
JP6: SolderJumper_2_Open; SolderJumper-2_P1.3mm_Open_TrianglePad1.0x1.5mm; not fitted
R1: 1K/1%; R_0402
R2: 10K/1%; R_0402
R76, R77: 100K/1%; R_0402
R83: 10K/1%; R_0402; not fitted
R84, R85, R86, R87, R88, R89: 0R/1%; R_0402; not fitted
TP7: TestPoint; TestPoint_Pad_D1.5mm
U18: W25Q128JVS; SOIC-8_5.23x5.23mm_P1.27mm; not fitted

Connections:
+3V3_ROM: C89.2, C90.2, R2.2, R83.2, U18.8 (VCC); also elsewhere on the board
+BATT: A1.115 (VBAT), R1.1
/Fan_Temp/FAN_1_PWM: A1.2 (FAN_CTL2); also elsewhere on the board
/Fan_Temp/FAN_1_TAC: A1.4 (FAN_TAC2); also elsewhere on the board
/GPIO/I2C2_SCL: A1.154 (I2C2_SCL); also elsewhere on the board
/GPIO/I2C2_SDA: A1.156 (I2C2_SDA); also elsewhere on the board
/GPIO/I2C3_SCL: A1.150 (I2C3_SCL); also elsewhere on the board
/GPIO/I2C3_SDA: A1.152 (I2C3_SDA); also elsewhere on the board
/GPIO/I2C4_SCL: A1.146 (I2C4_SCL); also elsewhere on the board
/GPIO/I2C4_SDA: A1.148 (I2C4_SDA); also elsewhere on the board
/GPIO/I2C5_SCL: A1.142 (I2C5_SCL); also elsewhere on the board
/GPIO/I2C5_SDA: A1.144 (I2C5_SDA); also elsewhere on the board
/GPIO/SOC_UART0_RX: A1.137 (SOC_UART0_RXD); also elsewhere on the board
/GPIO/SOC_UART0_TX: A1.139 (SOC_UART0_TXD); also elsewhere on the board
/GPIO/SOC_UART1_RX: A1.141 (SOC_UART1_RXD); also elsewhere on the board
/GPIO/SOC_UART1_TX: A1.143 (SOC_UART1_TXD); also elsewhere on the board
/GPIO/SOC_UART2_RX: A1.140 (SOC_UART2_RXD); also elsewhere on the board
/GPIO/SOC_UART2_TX: A1.138 (SOC_UART2_TXD); also elsewhere on the board
/Gigabit Ethernet/GbE_PCIe_CLK+: A1.94 (REFCLK4+); also elsewhere on the board
/Gigabit Ethernet/GbE_PCIe_CLK-: A1.96 (REFCLK4-); also elsewhere on the board
/Gigabit Ethernet/GbE_PCIe_RX+: A1.64 (HSIO6_RXP); also elsewhere on the board
/Gigabit Ethernet/GbE_PCIe_RX-: A1.66 (HSIO6_RXN); also elsewhere on the board
/Gigabit Ethernet/GbE_PCIe_TX+: A1.61 (HSIO6_TXP); also elsewhere on the board
/Gigabit Ethernet/GbE_PCIe_TX-: A1.63 (HSIO6_TXN); also elsewhere on the board
/Gigabit Ethernet/~CLKREQ4: A1.102 (~PCIeCLK_REQ4); also elsewhere on the board
/HDMI/DDI_B_DDC_SCL: A1.171 (DDC_B_SCL); also elsewhere on the board
/HDMI/DDI_B_DDC_SDA: A1.169 (DDC_B_SDA); also elsewhere on the board
/HDMI/DDI_B_HPD: A1.183 (HPD_B); also elsewhere on the board
/HDMI/DDI_B_TX0+: A1.217 (DDI_B_TX0+); also elsewhere on the board
/HDMI/DDI_B_TX0-: A1.215 (DDI_B_TX0-); also elsewhere on the board
/HDMI/DDI_B_TX1+: A1.211 (DDI_B_TX1+); also elsewhere on the board
/HDMI/DDI_B_TX1-: A1.209 (DDI_B_TX1-); also elsewhere on the board
/HDMI/DDI_B_TX2+: A1.205 (DDI_B_TX2+); also elsewhere on the board
/HDMI/DDI_B_TX2-: A1.203 (DDI_B_TX2-); also elsewhere on the board
/HDMI/DDI_B_TX3+: A1.199 (DDI_B_TX3+); also elsewhere on the board
/HDMI/DDI_B_TX3-: A1.197 (DDI_B_TX3-); also elsewhere on the board
/LattePanda Module/HSIO_0_TX+: A1.13 (HSIO0_TXP); also elsewhere on the board
/LattePanda Module/HSIO_0_TX-: A1.15 (HSIO0_TXN); also elsewhere on the board
/LattePanda Module/HSIO_1_TX+: A1.19 (HSIO1_TXP); also elsewhere on the board
/LattePanda Module/HSIO_1_TX-: A1.21 (HSIO1_TXN); also elsewhere on the board
/LattePanda Module/HSIO_2_RX+: A1.28 (HSIO2_RXP); also elsewhere on the board
/LattePanda Module/HSIO_2_RX-: A1.30 (HSIO2_RXN); also elsewhere on the board
/LattePanda Module/HSIO_2_TX+: A1.25 (HSIO2_TXP); also elsewhere on the board
/LattePanda Module/HSIO_2_TX-: A1.27 (HSIO2_TXN); also elsewhere on the board
/LattePanda Module/HSIO_3_RX+: A1.34 (HSIO3_RXP); also elsewhere on the board
/LattePanda Module/HSIO_3_RX-: A1.36 (HSIO3_RXN); also elsewhere on the board
/LattePanda Module/HSIO_3_TX+: A1.31 (HSIO3_TXP); also elsewhere on the board
/LattePanda Module/HSIO_3_TX-: A1.33 (HSIO3_TXN); also elsewhere on the board
/LattePanda Module/HSIO_8_RX+: A1.40 (HSIO8_RXP); also elsewhere on the board
/LattePanda Module/HSIO_8_RX-: A1.42 (HSIO8_RXN); also elsewhere on the board
/LattePanda Module/HSIO_8_TX+: A1.37 (HSIO8_TXP); also elsewhere on the board
/LattePanda Module/HSIO_8_TX-: A1.39 (HSIO8_TXN); also elsewhere on the board
/LattePanda Module/HSIO_9_RX+: A1.46 (HSIO9_RXP); also elsewhere on the board
/LattePanda Module/HSIO_9_RX-: A1.48 (HSIO9_RXN); also elsewhere on the board
/LattePanda Module/HSIO_9_TX+: A1.43 (HSIO9_TXP); also elsewhere on the board
/LattePanda Module/HSIO_9_TX-: A1.45 (HSIO9_TXN); also elsewhere on the board
/LattePanda Module/HSIO_10_RX+: A1.52 (HSIO10_RXP); also elsewhere on the board
/LattePanda Module/HSIO_10_RX-: A1.54 (HSIO10_RXN); also elsewhere on the board
/LattePanda Module/HSIO_10_TX+: A1.49 (HSIO10_TXP); also elsewhere on the board
/LattePanda Module/HSIO_10_TX-: A1.51 (HSIO10_TXN); also elsewhere on the board
/LattePanda Module/HSIO_11_RX+: A1.58 (HSIO11_RXP); also elsewhere on the board
/LattePanda Module/HSIO_11_RX-: A1.60 (HSIO11_RXN); also elsewhere on the board
/LattePanda Module/HSIO_11_TX+: A1.55 (HSIO11_TXP); also elsewhere on the board
/LattePanda Module/HSIO_11_TX-: A1.57 (HSIO11_TXN); also elsewhere on the board
/LattePanda Module/REFCLK0+: A1.85 (REFCLK0+); also elsewhere on the board
/LattePanda Module/REFCLK0-: A1.87 (REFCLK0-); also elsewhere on the board
/LattePanda Module/REFCLK2+: A1.97 (REFCLK2+); also elsewhere on the board
/LattePanda Module/REFCLK2-: A1.99 (REFCLK2-); also elsewhere on the board
/LattePanda Module/REFCLK3+: A1.88 (REFCLK3+); also elsewhere on the board
/LattePanda Module/REFCLK3-: A1.90 (REFCLK3-); also elsewhere on the board
/LattePanda Module/SPI_CLK: A1.155 (SPI_CLK), R85.2
/LattePanda Module/SPI_IO2: A1.161 (SPI_IO2), R88.2
/LattePanda Module/SPI_IO3: A1.153 (SPI_IO3), R89.2
/LattePanda Module/SPI_MISO/SPI_IO1: A1.163 (SPI_MISO/SPI_IO1), R87.2
/LattePanda Module/SPI_MOSI/SPI_IO0: A1.159 (SPI_MOSI/SPI_IO0), R86.2
/LattePanda Module/SUSCLK_WIFI: A1.131 (SUSCLK); also elsewhere on the board
/LattePanda Module/USB_2_P4+: A1.70 (USB2_P4)
/LattePanda Module/USB_2_P4-: A1.72 (USB2_N4)
/LattePanda Module/USB_2_P7+: A1.76 (USB2_P7); also elsewhere on the board
/LattePanda Module/USB_2_P7-: A1.78 (USB2_N7); also elsewhere on the board
/LattePanda Module/~CLKREQ3: A1.100 (~PCIeCLK_REQ3); also elsewhere on the board
/LattePanda Module/~PWR_SW: A1.1 (~PWR_SW); also elsewhere on the board
/LattePanda Module/~RST_SW: A1.3 (~RST_SW); also elsewhere on the board
/LattePanda Module/~SPI_CS0: A1.165 (~SPI_CS0), R83.1, R84.2
/PSU/UPS_USB_DN: A1.84 (USB2_N8); also elsewhere on the board
/PSU/UPS_USB_DP: A1.82 (USB2_P8); also elsewhere on the board
/PSU/~SLP_S4_N: A1.7 (SLP_S4_N); also elsewhere on the board
/USB2.0&USB3.0/CON_USB1_D_N: A1.109 (USB2_N5); also elsewhere on the board
/USB2.0&USB3.0/CON_USB1_D_P: A1.111 (USB2_P5); also elsewhere on the board
/USB2.0&USB3.0/CON_USB2_D_N: A1.79 (USB2_N3); also elsewhere on the board
/USB2.0&USB3.0/CON_USB2_D_P: A1.81 (USB2_P3); also elsewhere on the board
/USB2.0&USB3.0/CON_USB3_D_N: A1.73 (USB2_N2); also elsewhere on the board
/USB2.0&USB3.0/CON_USB3_D_P: A1.75 (USB2_P2); also elsewhere on the board
/USB2.0&USB3.0/CON_USB3_SSRX_N: A1.18 (HSIO0_RXN); also elsewhere on the board
/USB2.0&USB3.0/CON_USB3_SSRX_P: A1.16 (HSIO0_RXP); also elsewhere on the board
/USB2.0&USB3.0/CON_USB4_D_N: A1.67 (USB2_N1); also elsewhere on the board
/USB2.0&USB3.0/CON_USB4_D_P: A1.69 (USB2_P1); also elsewhere on the board
/USB2.0&USB3.0/CON_USB4_SSRX_N: A1.24 (HSIO1_RXN); also elsewhere on the board
/USB2.0&USB3.0/CON_USB4_SSRX_P: A1.22 (HSIO1_RXP); also elsewhere on the board
/~PLT_RST: A1.105 (~BUF_PLT_RST); also elsewhere on the board
/~PWR_LED/~PSON: A1.5 (~PWR_LED/~PSON); also elsewhere on the board
/~WAKE: A1.103 (~PCIe_WAKE); also elsewhere on the board
GND: A1.11 (GND), A1.14 (GND), A1.17 (GND), A1.20 (GND), A1.23 (GND), A1.26 (GND), A1.29 (GND), A1.32 (GND), A1.35 (GND), A1.38 (GND), A1.41 (GND), A1.44 (GND), A1.47 (GND), A1.50 (GND), A1.53 (GND), A1.56 (GND), A1.59 (GND), A1.62 (GND), A1.65 (GND), A1.68 (GND), A1.71 (GND), A1.74 (GND), A1.77 (GND), A1.80 (GND), A1.83 (GND), A1.86 (GND), A1.89 (GND), A1.92 (GND), A1.95 (GND), A1.98 (GND), A1.101 (GND), A1.107 (GND), A1.110 (GND), A1.113 (GND), A1.116 (GND), A1.135 (GND), A1.136 (GND), A1.151 (GND), A1.158 (GND), A1.167 (GND), A1.170 (GND), A1.181 (GND), A1.182 (GND), A1.188 (GND), A1.189 (GND), A1.194 (GND), A1.195 (GND), A1.200 (GND), A1.201 (GND), A1.206 (GND), A1.207 (GND), A1.212 (GND), A1.213 (GND), A1.218 (GND), A1.219 (GND), A1.224 (GND), A1.225 (GND), A1.230 (GND), A1.231 (GND), A1.236 (GND), A1.237 (GND), A1.242 (GND), A1.243 (GND), A1.248 (GND), A1.249 (GND), A1.MP1, A1.MP2, BT1.2 (-), C89.1, C90.1, H5.1, H6.1, J1.3, JP6.1 (A), R76.2, R77.2, U18.4 (GND); also elsewhere on the board
unnamed: A1.187 (HPD_0), R76.1
unnamed: A1.185 (HPD_1), R77.1
unnamed: A1.12 (SIO_UART_RX), J1.2
unnamed: A1.10 (SIO_UART_TX), J1.1
unnamed: A1.133 (~BIOS_SEL), JP6.2 (B), R2.1, TP7.1
unnamed: BT1.1 (+), R1.2
unnamed: R85.1, U18.6 (CLK)
unnamed: R86.1, U18.5 (DI(IO0))
unnamed: R87.1, U18.2 (DO(IO1))
unnamed: R88.1, U18.3 (IO2)
unnamed: R89.1, U18.7 (IO3)
unnamed: R84.1, U18.1 (~CS)
VDC: A1.250 (VIN), A1.251 (VIN), A1.252 (VIN), A1.253 (VIN), A1.254 (VIN), A1.255 (VIN), A1.256 (VIN), A1.257 (VIN), A1.258 (VIN), A1.259 (VIN), A1.260 (VIN); also elsewhere on the board

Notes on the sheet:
State Signal - PWR_LED/PSON: - S0 (Working): HIGH - S3 (Slpeeping): LOW - S4 (Hibernation): LOW - S5 (Soft Off): LOW - SLS_S4_N: - S0 (Working): HIGH - S3 (Slpeeping): HIGH - S4 (Hibernation): LOW - S5 (Soft Off): LOW
DDI/TCP functions are defined by the BIOS firmware, Cannot be changed in BIOS menu. Before starting design, you should choose one of the available BIOS configurations on: https://github.com/LattePandaTeam/LattePanda-Mu The default functions are defined as follows: - DDIA: eDP 1.4b (the 40Pin connec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
Lite Carrier has no second BIOS ROM chip welded on the board. ~{BIOS_SEL} pull up to 3.3V to select ROM of LattePanda Mu compute module.
USB2_P6 is reserved for TypeC PD Controller DO NOT use it as a normal USB
Debug uart
Conn_01×03_pin
SPI is only used to connect to the BIOS ROM. Cannot be used as a general SPI interface.
HSIO functions are defined by the BIOS firmware, Cannot be changed in BIOS menu. Before starting design, you should choose one of the available BIOS configurations on: https://github.com/LattePandaTeam/LattePanda-Mu Or contact techsupport for custom your BIOS The default functions are defined as fo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
All I2C pins have integrated pull-up resistors on the LattePanda Mu compute module. no need to add pull-up resistors on the carrier board.
HSIO_0/HSIO_1 used for USB3.0
HSIO_2 used for M.2 M KEY
HSIO_6 used for GbE(PCIe x1)
USB2 P3/P5 used for USB2.0
DDI B used for HDMI
HSIO_3 used for M.2 E KEY
HSIO_8/9/10/11 used for PCIe x4
USB2 P1/P2 used for USB3.0

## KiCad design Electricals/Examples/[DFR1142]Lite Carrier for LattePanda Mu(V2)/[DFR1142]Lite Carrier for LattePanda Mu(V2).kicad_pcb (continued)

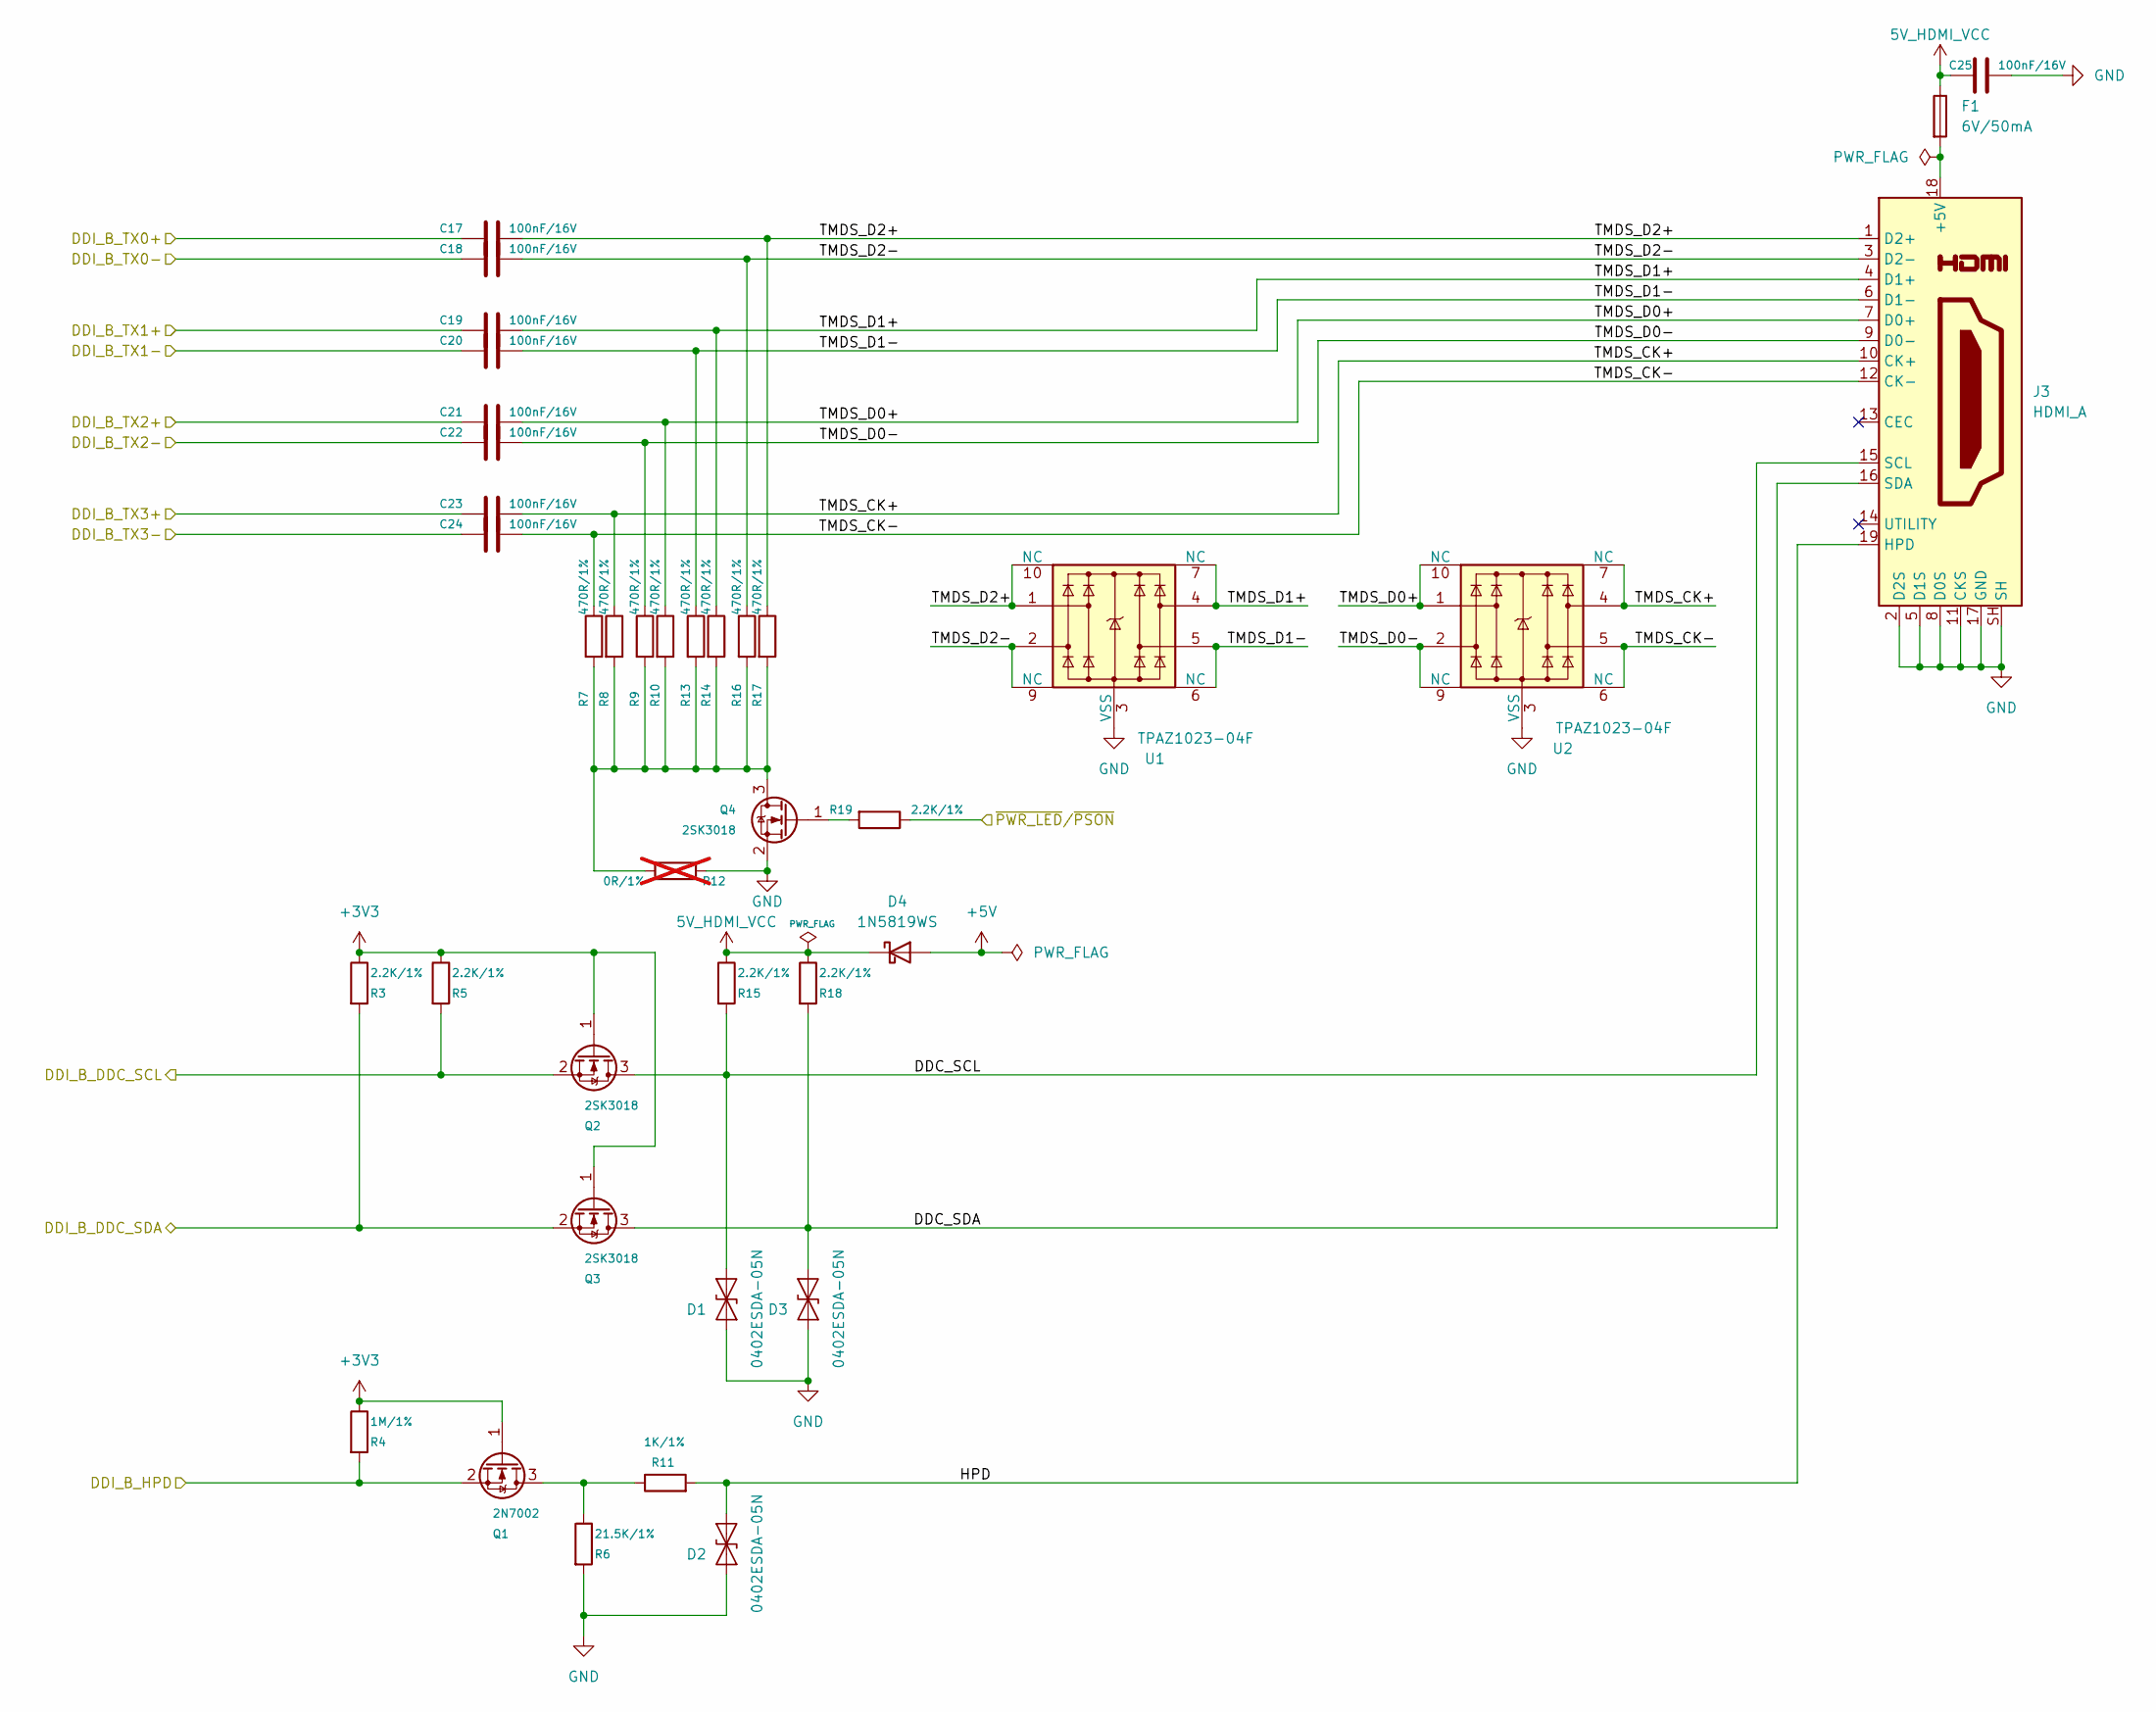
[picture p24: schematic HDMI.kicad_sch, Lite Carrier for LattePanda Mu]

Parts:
C17, C18, C19, C20, C21, C22, C23, C24, C25: 100nF/16V; C_0402_1005Metric
D1, D2, D3: 0402ESDA-05N; D_0402_1005Metric
D4: 1N5819WS; D_SOD-323
F1: 6V/50mA; R_0603_1608Metric
J3: HDMI_A; HDMI_A_Molex_208658-1001_Horizontal
Q1: 2N7002; SOT-23
Q2, Q3, Q4: 2SK3018; SOT-23
R3, R5, R15, R18, R19: 2.2K/1%; R_0402
R4: 1M/1%; R_0402
R6: 21.5K/1%; R_0402
R7, R8, R9, R10, R13, R14, R16, R17: 470R/1%; R_0402
R11: 1K/1%; R_0402
R12: 0R/1%; R_0402_1005Metric; not fitted
U1, U2: TPAZ1023-04F; Diodes_UDFN-10_1.0x2.5mm_P0.5mm

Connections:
5V_HDMI_VCC: C25.1, D4.1 (K), F1.1, R15.1, R18.1
+3V3: Q1.1 (G), Q2.1 (G), Q3.1 (G), R3.1, R4.1, R5.1; also elsewhere on the board
+5V: D4.2 (A); also elsewhere on the board
/HDMI/DDC_SCL: D1.2 (A2), J3.15 (SCL), Q2.3 (D), R15.2
/HDMI/DDC_SDA: D3.2 (A2), J3.16 (SDA), Q3.3 (D), R18.2
/HDMI/DDI_B_DDC_SCL: Q2.2 (S), R5.2; also elsewhere on the board
/HDMI/DDI_B_DDC_SDA: Q3.2 (S), R3.2; also elsewhere on the board
/HDMI/DDI_B_HPD: Q1.2 (S), R4.2; also elsewhere on the board
/HDMI/DDI_B_TX0+: C17.1; also elsewhere on the board
/HDMI/DDI_B_TX0-: C18.1; also elsewhere on the board
/HDMI/DDI_B_TX1+: C19.1; also elsewhere on the board
/HDMI/DDI_B_TX1-: C20.1; also elsewhere on the board
/HDMI/DDI_B_TX2+: C21.1; also elsewhere on the board
/HDMI/DDI_B_TX2-: C22.1; also elsewhere on the board
/HDMI/DDI_B_TX3+: C23.1; also elsewhere on the board
/HDMI/DDI_B_TX3-: C24.1; also elsewhere on the board
/HDMI/HPD: D2.2 (A2), J3.19 (HPD), R11.2
/HDMI/TMDS_CK+: C23.2, J3.10 (CK+), R8.1, U2.4, U2.7 (NC)
/HDMI/TMDS_CK-: C24.2, J3.12 (CK-), R7.1, U2.5, U2.6 (NC)
/HDMI/TMDS_D0+: C21.2, J3.7 (D0+), R10.1, U2.1, U2.10 (NC)
/HDMI/TMDS_D0-: C22.2, J3.9 (D0-), R9.1, U2.2, U2.9 (NC)
/HDMI/TMDS_D1+: C19.2, J3.4 (D1+), R14.1, U1.4, U1.7 (NC)
/HDMI/TMDS_D1-: C20.2, J3.6 (D1-), R13.1, U1.5, U1.6 (NC)
/HDMI/TMDS_D2+: C17.2, J3.1 (D2+), R17.1, U1.1, U1.10 (NC)
/HDMI/TMDS_D2-: C18.2, J3.3 (D2-), R16.1, U1.2, U1.9 (NC)
/~PWR_LED/~PSON: R19.1; also elsewhere on the board
GND: C25.2, D1.1 (A1), D2.1 (A1), D3.1 (A1), J3.2 (D2S), J3.5 (D1S), J3.8 (D0S), J3.11 (CKS), J3.17 (GND), J3.SH, Q4.2 (S), R6.2, R12.2, U1.3 (VSS), U1.8 (VSS), U2.3 (VSS), U2.8 (VSS); also elsewhere on the board
unnamed: F1.2, J3.18 (+5V)
unnamed: Q1.3 (D), R6.1, R11.1
unnamed: Q4.3 (D), R7.2, R8.2, R9.2, R10.2, R12.1, R13.2, R14.2, R16.2, R17.2
unnamed: Q4.1 (G), R19.2

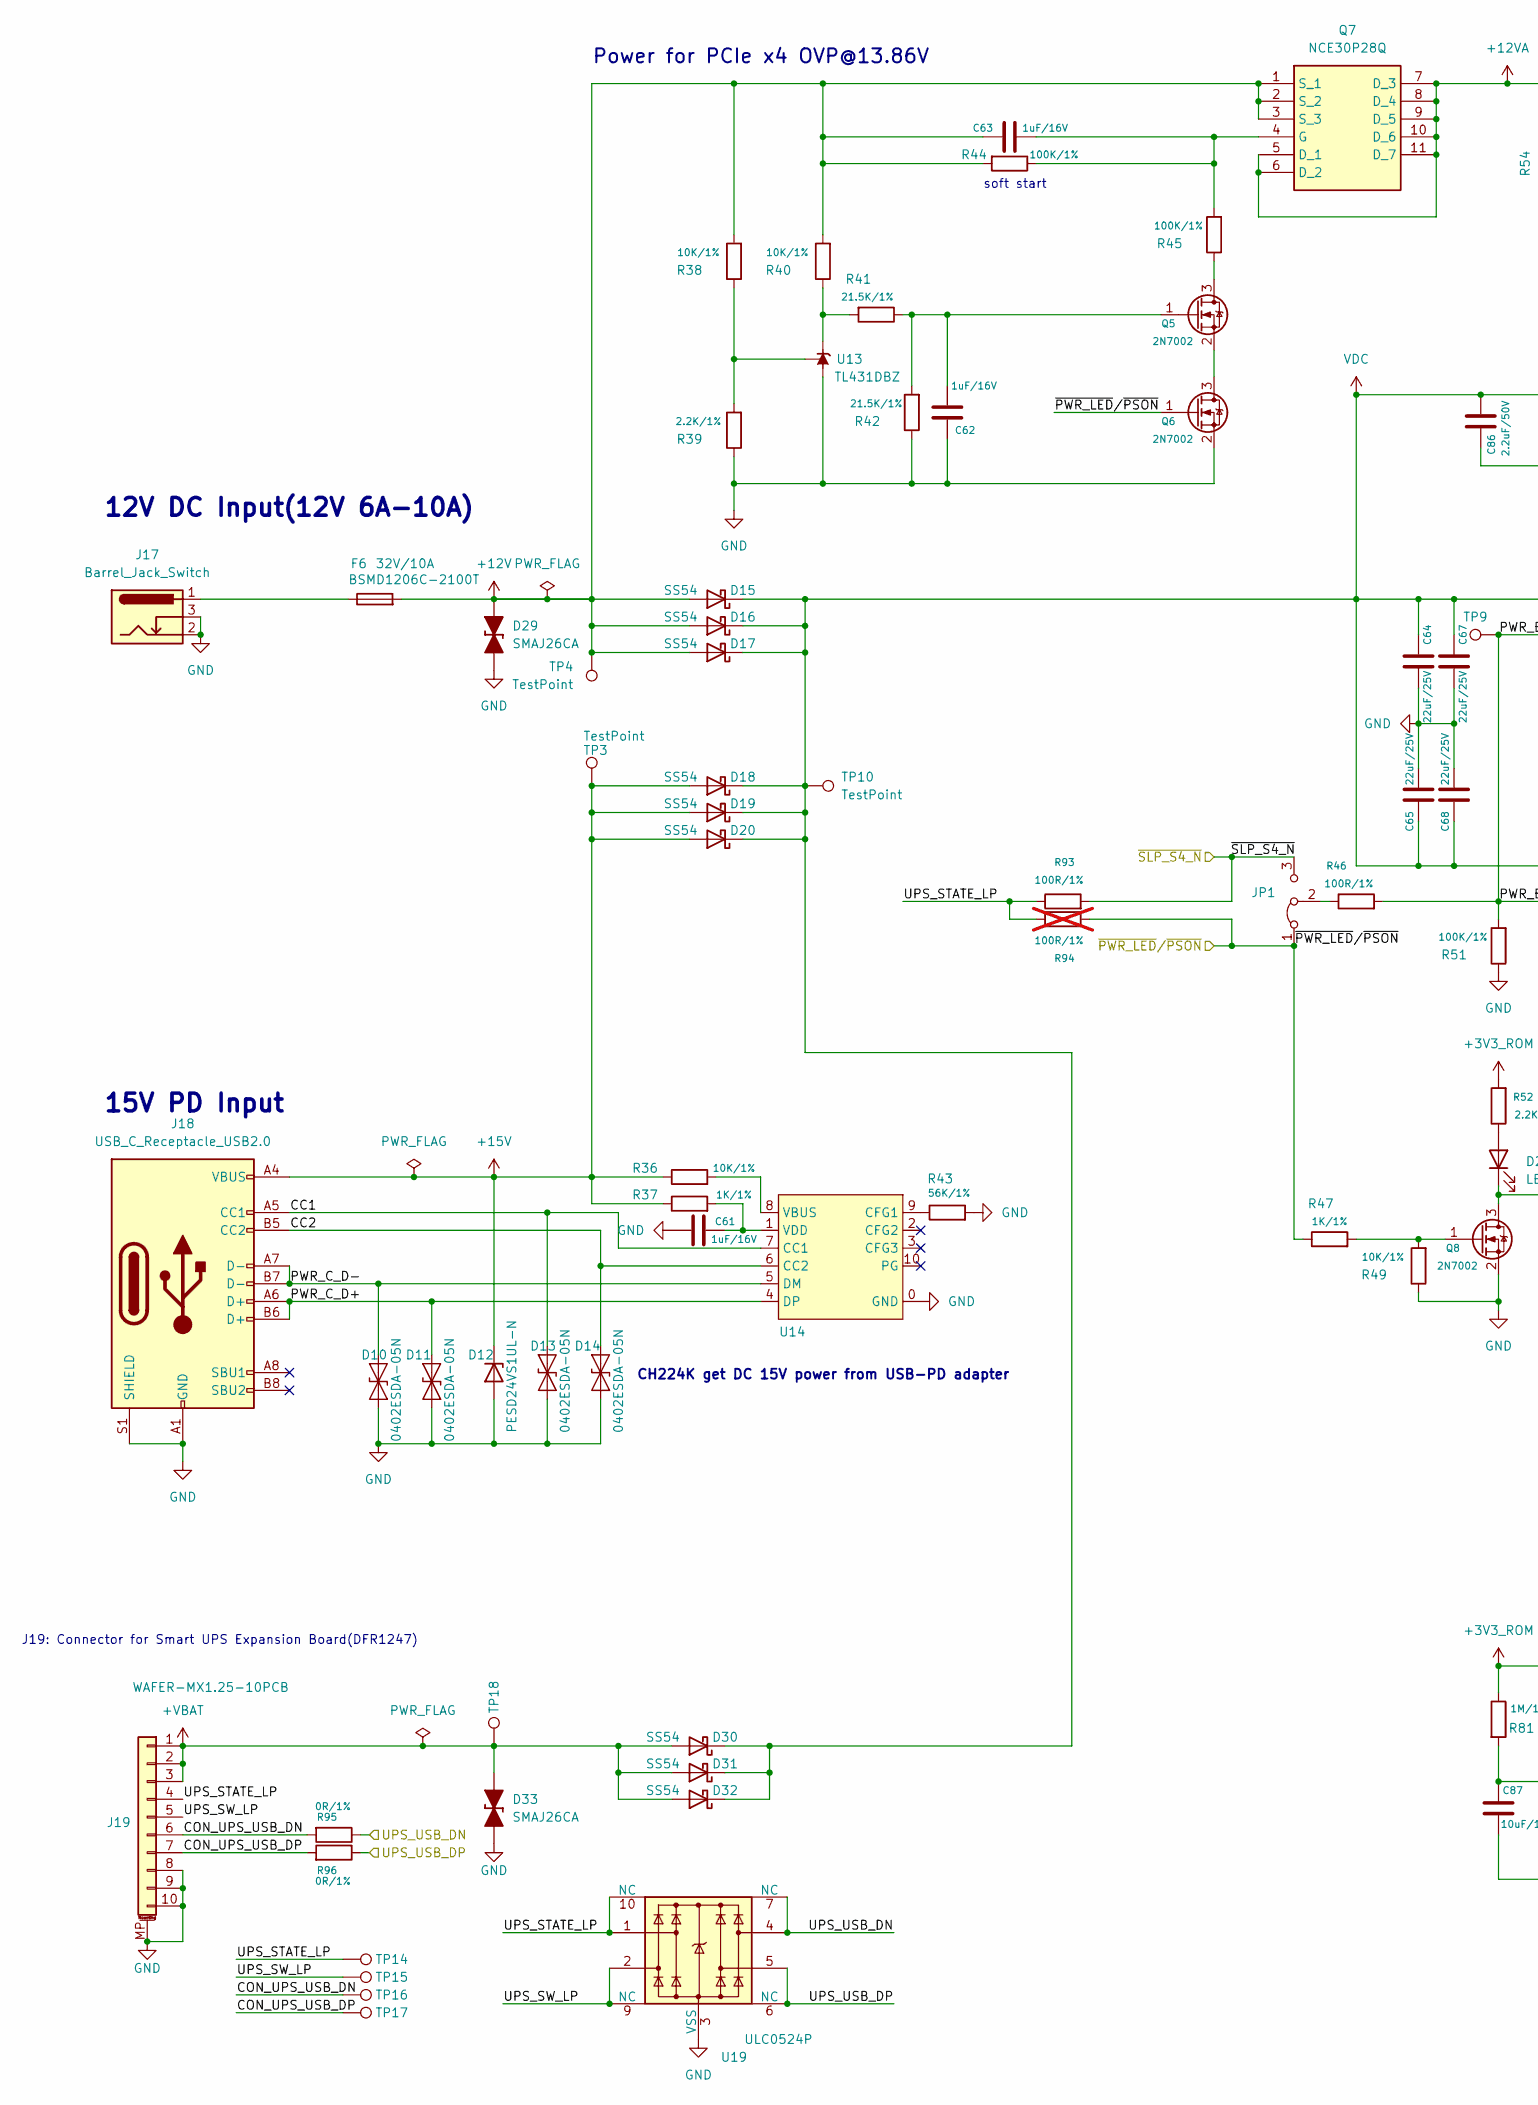
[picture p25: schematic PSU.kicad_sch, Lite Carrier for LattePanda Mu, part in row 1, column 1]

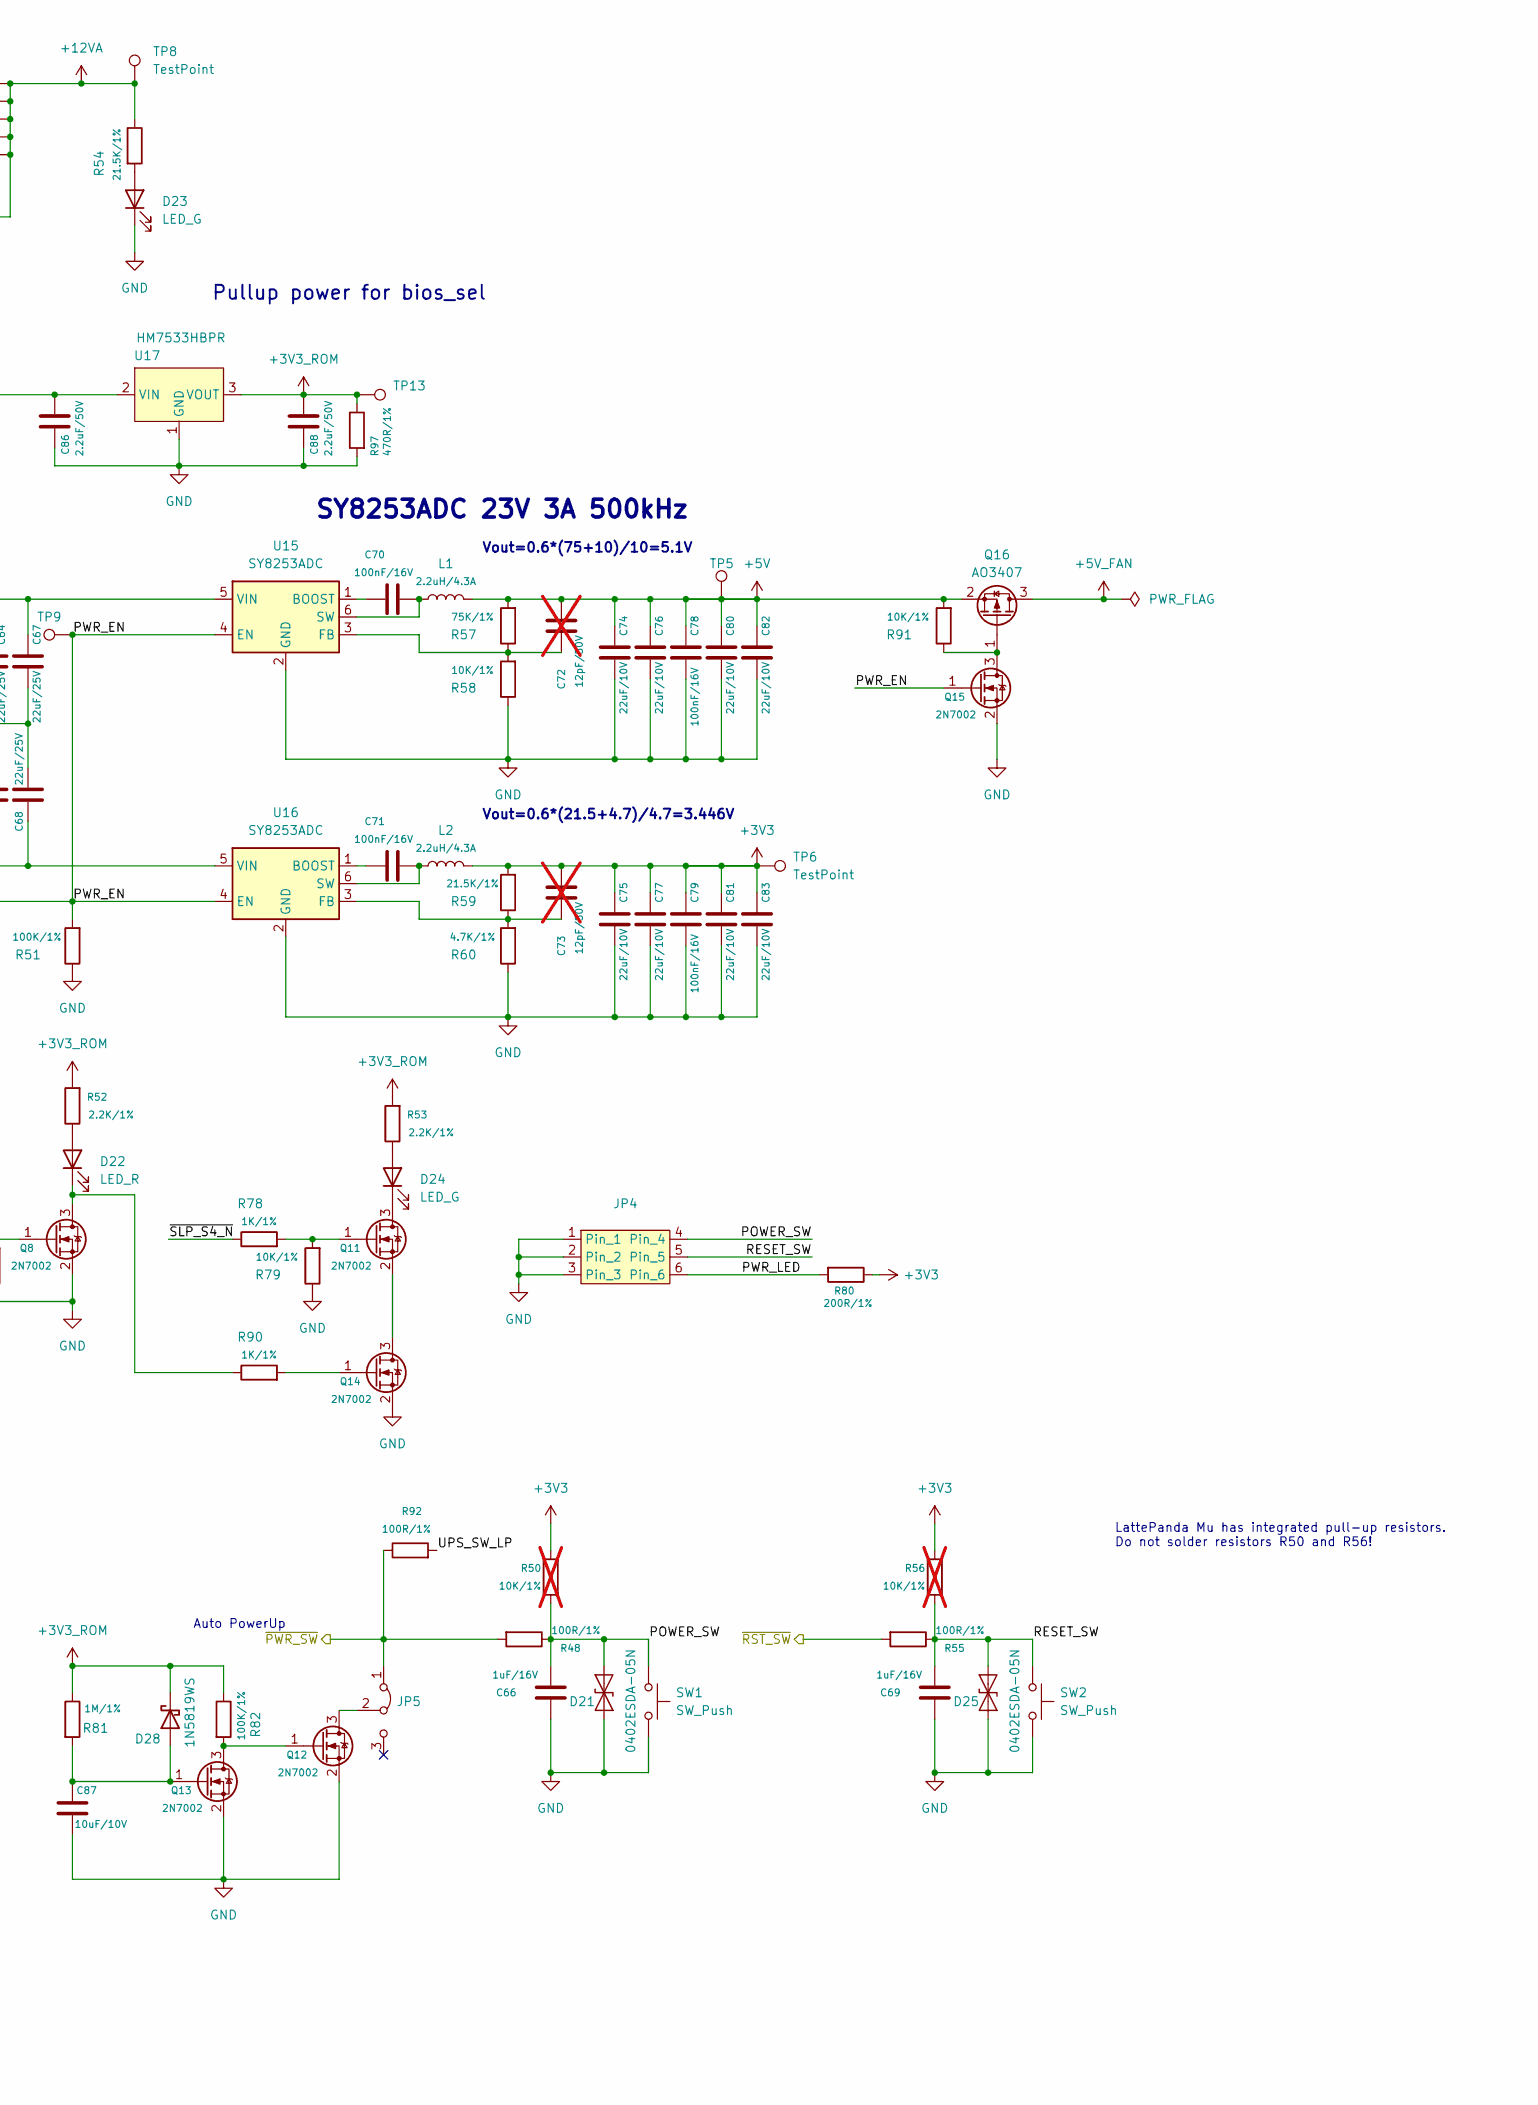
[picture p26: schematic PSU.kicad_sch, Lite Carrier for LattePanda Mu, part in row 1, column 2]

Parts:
C61, C62, C63, C66, C69: 1uF/16V; C_0402_1005Metric
C64, C65, C67, C68: 22uF/25V; C_0805_2012Metric
C70, C71, C78, C79: 100nF/16V; C_0402_1005Metric
C72, C73: 12pF/50V; C_0402_1005Metric; not fitted
C74, C75, C76, C77, C80, C81, C82, C83: 22uF/10V; C_0603_1608Metric
C86, C88: 2.2uF/50V; C_0603
C87: 10uF/10V; C_0402_1005Metric
D10, D11, D13, D14, D21, D25: 0402ESDA-05N; D_0402_1005Metric
D12: PESD24VS1UL-N; D_0402_1005Metric
D15, D16, D17, D18, D19, D20, D30, D31, D32: SS54; D_SMA
D22: LED_R; LED_0603_1608Metric
D23, D24: LED_G; LED_0603_1608Metric
D28: 1N5819WS; D_SOD-323
D29, D33: SMAJ26CA; D_SMA
F6: BSMD1206C-2100T; R_1206
J17: Barrel_Jack_Switch; DC_Jack_DC007B_30V_10A
J18: USB_C_Receptacle_USB2.0; USB_C_Receptacle_G-Switch_GT-USB-7010ASV
J19: WAFER-MX1.25-10PCB; MX1.25-10P-SMD
JP1, JP5: Jumper_3_Bridged12; PinHeader_1x03_P2.54mm_Vertical
JP4: PinHeader_2x03_P2.54mm_Vertical
L1, L2: 2.2uH/4.3A; L_Sunlord_SWPA4020S
Q5, Q6, Q8, Q11, Q12, Q13, Q14, Q15: 2N7002; SOT-23
Q7: NCE30P28Q; MOSFET_PDFN8_3.3x3.3
Q16: AO3407; SOT-23
R36, R38, R40, R49, R58, R79, R91: 10K/1%; R_0402
R37, R47, R78, R90: 1K/1%; R_0402
R39, R52, R53: 2.2K/1%; R_0402
R41, R42, R54, R59: 21.5K/1%; R_0402
R43: 56K/1%; R_0402
R44, R45, R51, R82: 100K/1%; R_0402
R46, R48, R55, R92, R93: 100R/1%; R_0402
R50, R56: 10K/1%; R_0402_1005Metric; not fitted
R57: 75K/1%; R_0402
R60: 4.7K/1%; R_0402
R80: 200R/1%; R_0402
R81: 1M/1%; R_0402
R94: 100R/1%; R_0402; not fitted
R95, R96: 0R/1%; R_0402
R97: 470R/1%; R_0402
SW1, SW2: SW_Push; SW_PUSH_SIDE_TS-1012EV_7.7x3.95x3.5mm
TP3, TP4, TP5, TP6, TP8, TP9, TP10, TP13, TP14, TP15, TP16, TP17, TP18: TestPoint; TestPoint_Pad_D1.5mm
U13: TL431DBZ; SOT-23
U14: CH224K; ESSOP-10-1EP_3.9x5mm_P1.0mm_EP3.2x2.3
U15, U16: SY8253ADC; TSOT-23-6
U17: HM7533HBPR; SOT-89-3
U19: ULC0524P; Diodes_UDFN-10_1.0x2.5mm_P0.5mm

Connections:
+3V3: C73.1, C75.2, C77.2, C79.1, C81.2, C83.2, L2.2, R50.2, R56.2, R59.2, R80.1, TP6.1; also elsewhere on the board
+3V3_ROM: C88.1, D28.1 (K), R52.2, R53.2, R81.1, R82.1, R97.1, TP13.1, U17.3 (VOUT); also elsewhere on the board
+5V: C72.1, C74.2, C76.2, C78.1, C80.2, C82.2, L1.2, Q16.2 (S), R57.2, R91.2, TP5.1; also elsewhere on the board
+5V_FAN: Q16.3 (D); also elsewhere on the board
+12V: C63.2, D15.2 (A), D16.2 (A), D17.2 (A), D29.2 (A), F6.2, Q7.1 (S_1), Q7.2 (S_2), Q7.3 (S_3), R38.2, R40.2, R44.2, TP4.1
+12VA: Q7.5 (D_1), Q7.6 (D_2), Q7.7 (D_3), Q7.8 (D_4), Q7.9 (D_5), Q7.10 (D_6), Q7.11 (D_7), R54.1, TP8.1; also elsewhere on the board
+15V: D12.1 (K), D18.2 (A), D19.2 (A), D20.2 (A), J18.A4 (VBUS), J18.A9 (VBUS), J18.B4 (VBUS), J18.B9 (VBUS), R36.1, R37.1, TP3.1
+VBAT: D30.2 (A), D31.2 (A), D32.2 (A), D33.2 (A), J19.1, J19.2, J19.3, TP18.1
/LattePanda Module/~PWR_SW: JP5.1 (A), R48.2, R92.1; also elsewhere on the board
/LattePanda Module/~RST_SW: R55.2; also elsewhere on the board
/PSU/CC1: D13.2 (A2), J18.A5 (CC1), U14.7 (CC1)
/PSU/CC2: D14.2 (A2), J18.B5 (CC2), U14.6 (CC2)
/PSU/CON_UPS_USB_DN: J19.6, R95.2, TP16.1
/PSU/CON_UPS_USB_DP: J19.7, R96.2, TP17.1
/PSU/POWER_SW: C66.1, D21.2 (A2), JP4.4, R48.1, R50.1, SW1.1
/PSU/PWR_C_D+: D11.2 (A2), J18.A6 (D+), J18.B6 (D+), U14.4 (DP)
/PSU/PWR_C_D-: D10.2 (A2), J18.A7 (D-), J18.B7 (D-), U14.5 (DM)
/PSU/PWR_EN: Q15.1 (G), R46.2, R51.2, TP9.1, U15.4 (EN), U16.4 (EN)
/PSU/PWR_LED: JP4.6, R80.2
/PSU/RESET_SW: C69.1, D25.2 (A2), JP4.5, R55.1, R56.1, SW2.1
/PSU/UPS_STATE_LP: J19.4, R93.1, R94.1, TP14.1, U19.1, U19.10 (NC)
/PSU/UPS_SW_LP: J19.5, R92.2, TP15.1, U19.2, U19.9 (NC)
/PSU/UPS_USB_DN: R95.1; also elsewhere on the board
/PSU/UPS_USB_DP: R96.1; also elsewhere on the board
/PSU/~SLP_S4_N: JP1.3 (B), R78.1, R93.2; also elsewhere on the board
/~PWR_LED/~PSON: JP1.1 (A), Q6.1 (G), R47.1, R94.2; also elsewhere on the board
GND: C61.2, C62.2, C64.1, C65.1, C66.2, C67.1, C68.1, C69.2, C74.1, C75.1, C76.1, C77.1, C78.2, C79.2, C80.1, C81.1, C82.1, C83.1, C86.2, C87.2, C88.2, D10.1 (A1), D11.1 (A1), D12.2 (A), D13.1 (A1), D14.1 (A1), D21.1 (A1), D23.1 (K), D25.1 (A1), D29.1 (K), D33.1 (K), J17.2, J17.3, J18.A1 (GND), J18.A12 (GND), J18.B1 (GND), J18.B12 (GND), J18.S1 (SHIELD), J19.8, J19.9, J19.10, J19.MP (MountPin), JP4.1, JP4.2, JP4.3, Q6.2 (S), Q8.2 (S), Q12.2 (S), Q13.2 (S), Q14.2 (S), Q15.2 (S), R39.1, R42.1, R43.2, R49.1, R51.1, R58.1, R60.1, R79.1, R97.2, SW1.2, SW2.2, U13.3 (A), U14.0 (GND), U15.2 (GND), U16.2 (GND), U17.1 (GND), U19.3 (VSS), U19.8 (VSS); also elsewhere on the board
unnamed: D22.2 (A), R52.1
unnamed: D22.1 (K), Q8.3 (D), R90.1
unnamed: D23.2 (A), R54.2
unnamed: D24.2 (A), R53.1
unnamed: D24.1 (K), Q11.3 (D)
unnamed: C87.1, D28.2 (A), Q13.1 (G), R81.2
unnamed: F6.1, J17.1
unnamed: JP1.2 (C), R46.1
unnamed: JP5.2 (C), Q12.3 (D)
unnamed: Q5.3 (D), R45.1
unnamed: C62.1, Q5.1 (G), R41.1, R42.2
unnamed: Q5.2 (S), Q6.3 (D)
unnamed: C63.1, Q7.4 (G), R44.1, R45.2
unnamed: Q8.1 (G), R47.2, R49.2
unnamed: Q11.1 (G), R78.2, R79.2
unnamed: Q11.2 (S), Q14.3 (D)
unnamed: Q12.1 (G), Q13.3 (D), R82.2
unnamed: Q14.1 (G), R90.2
unnamed: Q15.3 (D), Q16.1 (G), R91.1
unnamed: R40.1, R41.2, U13.1 (K)
unnamed: R38.1, R39.2, U13.2 (REF)
unnamed: R43.1, U14.9 (CFG1)
unnamed: R36.2, U14.8 (VBUS)
unnamed: C61.1, R37.2, U14.1 (VDD)
unnamed: C70.2, U15.1 (BOOST)
unnamed: C72.2, R57.1, R58.2, U15.3 (FB)
unnamed: C70.1, L1.1, U15.6 (SW)
unnamed: C71.2, U16.1 (BOOST)
unnamed: C73.2, R59.1, R60.2, U16.3 (FB)
unnamed: C71.1, L2.1, U16.6 (SW)
unnamed: U19.4, U19.7 (NC)
unnamed: U19.5, U19.6 (NC)
VDC: C64.2, C65.2, C67.2, C68.2, C86.1, D15.1 (K), D16.1 (K), D17.1 (K), D18.1 (K), D19.1 (K), D20.1 (K), D30.1 (K), D31.1 (K), D32.1 (K), TP10.1, U15.5 (VIN), U16.5 (VIN), U17.2 (VIN); also elsewhere on the board

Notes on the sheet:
soft start
15V PD Input
J19: Connector for Smart UPS Expansion Board(DFR1247)
SY8253ADC 23V 3A 500kHz
Auto PowerUp
Power for PCIe x4 OVP@13.86V
Vout=0.6*(75+10)/10=5.1V
LattePanda Mu has integrated pull-up resistors. Do not solder resistors R50 and R56!
12V DC Input(12V 6A-10A)
CH224K get DC 15V power from USB-PD adapter
Pullup power for bios_sel
Vout=0.6*(21.5+4.7)/4.7=3.446V

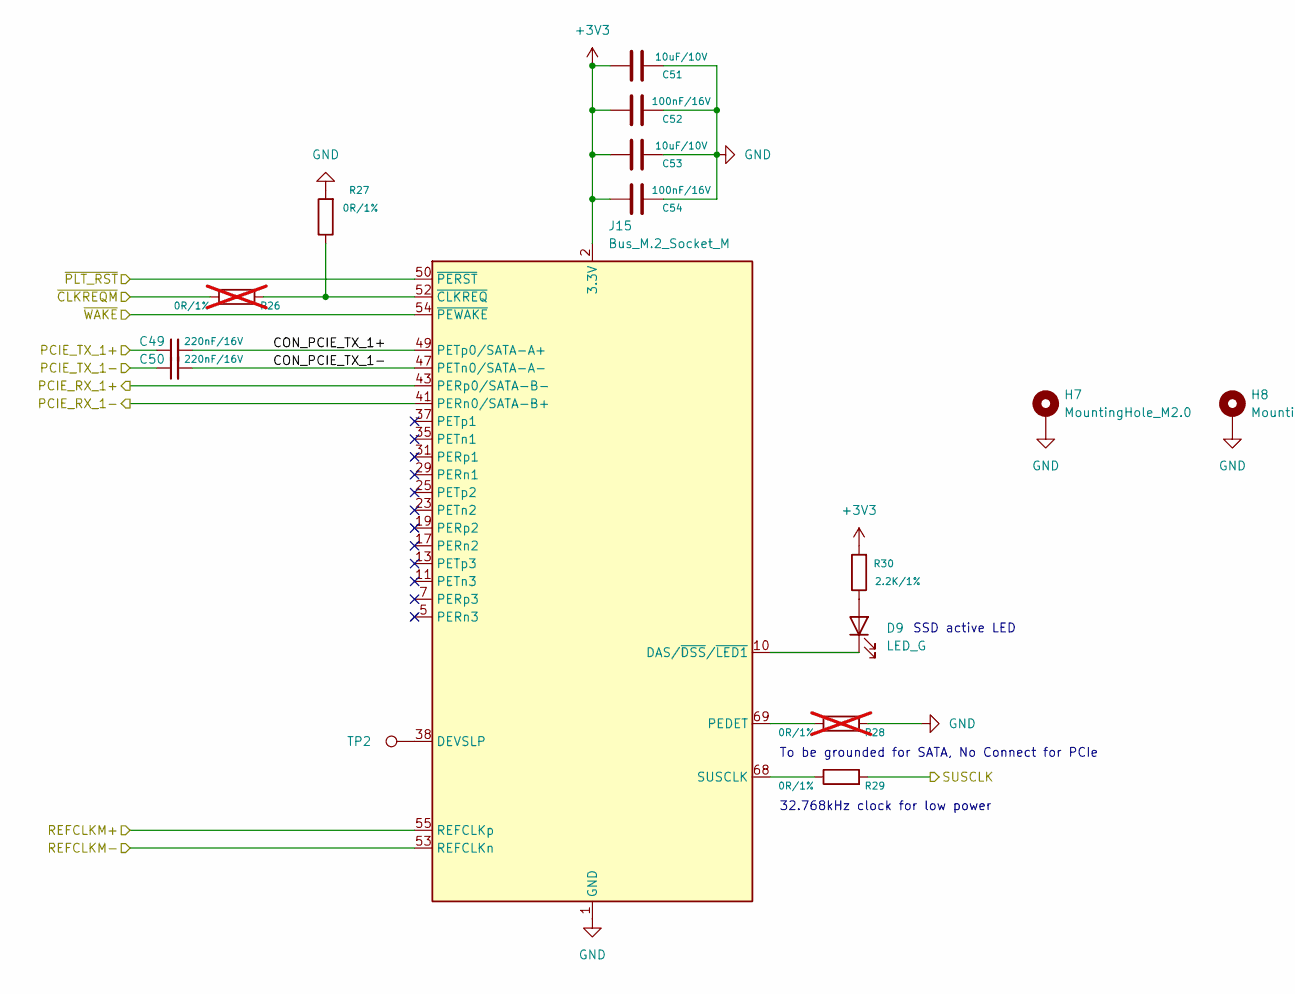
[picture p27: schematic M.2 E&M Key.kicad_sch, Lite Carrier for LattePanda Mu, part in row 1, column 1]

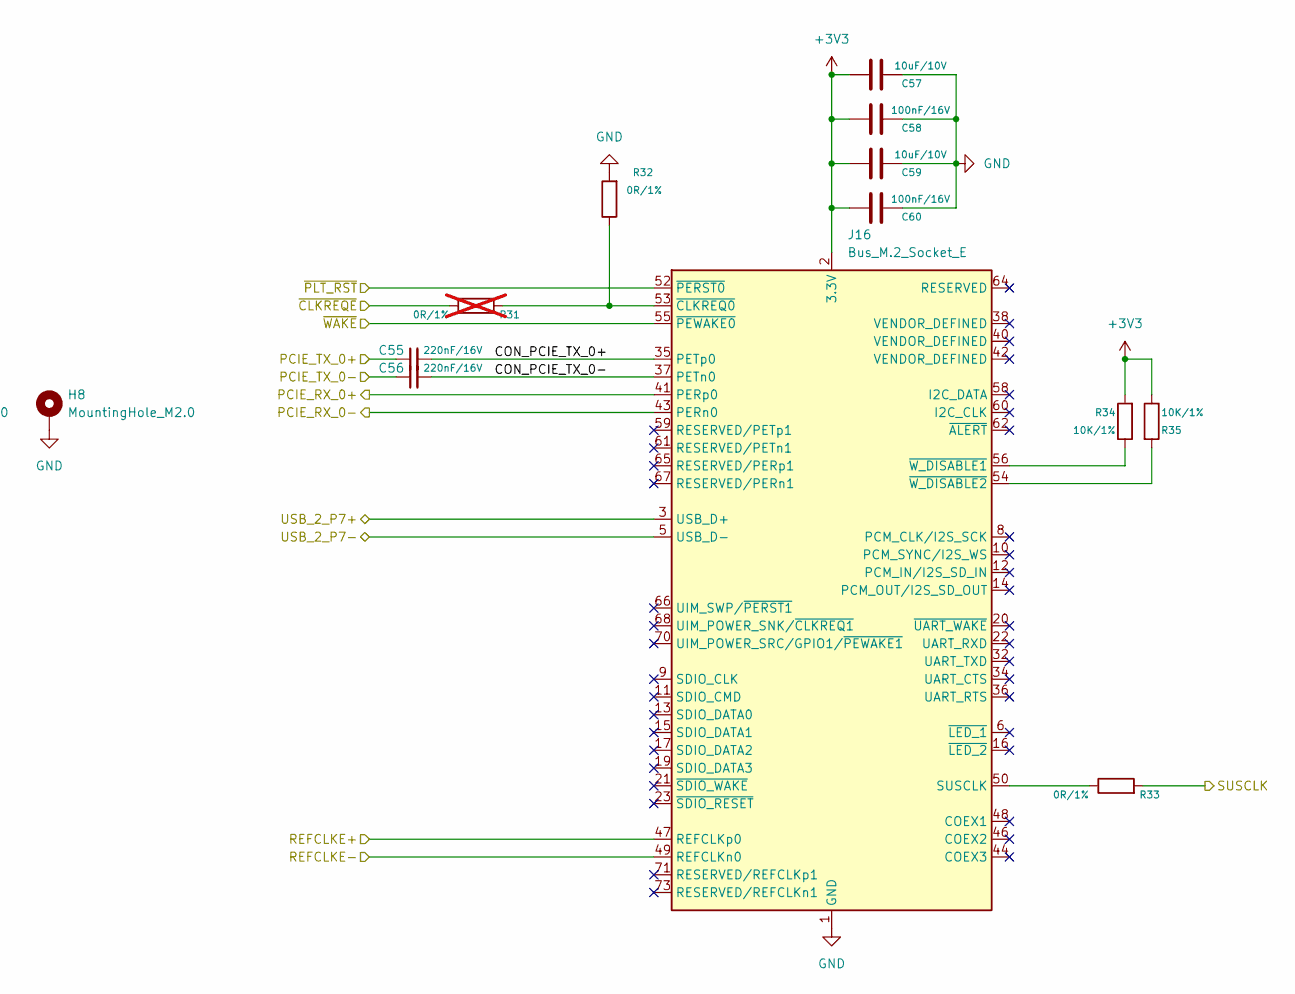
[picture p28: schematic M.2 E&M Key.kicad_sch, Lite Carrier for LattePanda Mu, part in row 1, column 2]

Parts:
C49, C50, C55, C56: 220nF/16V; C_0402_1005Metric
C51, C53, C57, C59: 10uF/10V; C_0402_1005Metric
C52, C54, C58, C60: 100nF/16V; C_0402_1005Metric
D9: LED_G; LED_0603_1608Metric
H7, H8: MountingHole_M2.0; MountingHole_2.75mm_M2_4.4mm_Pad_TopOnly
J15: Bus_M.2_Socket_M; PCIe_M.2_Connectors_P=0.5mm_H=4.2mm_KeyM
J16: Bus_M.2_Socket_E; PCIe_M.2_Connectors_P=0.5mm_H=4.2mm_KeyE
R26, R28, R31: 0R/1%; R_0402_1005Metric; not fitted
R27, R29, R32, R33: 0R/1%; R_0402
R30: 2.2K/1%; R_0402
R34, R35: 10K/1%; R_0402
TP2: TestPoint; TestPoint_Pad_D1.5mm

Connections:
+3V3: C51.2, C52.2, C53.2, C54.2, C57.2, C58.2, C59.2, C60.2, J15.2 (3.3V), J15.4 (3.3V), J15.12 (3.3V), J15.14 (3.3V), J15.16 (3.3V), J15.18 (3.3V), J15.70 (3.3V), J15.72 (3.3V), J15.74 (3.3V), J16.2 (3.3V), J16.4 (3.3V), J16.72 (3.3V), J16.74 (3.3V), R30.2, R34.2, R35.1; also elsewhere on the board
/LattePanda Module/HSIO_2_RX+: J15.43 (PERp0/SATA-B-); also elsewhere on the board
/LattePanda Module/HSIO_2_RX-: J15.41 (PERn0/SATA-B+); also elsewhere on the board
/LattePanda Module/HSIO_2_TX+: C49.1; also elsewhere on the board
/LattePanda Module/HSIO_2_TX-: C50.1; also elsewhere on the board
/LattePanda Module/HSIO_3_RX+: J16.41 (PERp0); also elsewhere on the board
/LattePanda Module/HSIO_3_RX-: J16.43 (PERn0); also elsewhere on the board
/LattePanda Module/HSIO_3_TX+: C55.1; also elsewhere on the board
/LattePanda Module/HSIO_3_TX-: C56.1; also elsewhere on the board
/LattePanda Module/REFCLK0+: J15.53 (REFCLKn); also elsewhere on the board
/LattePanda Module/REFCLK0-: J15.55 (REFCLKp); also elsewhere on the board
/LattePanda Module/REFCLK3+: J16.47 (REFCLKp0); also elsewhere on the board
/LattePanda Module/REFCLK3-: J16.49 (REFCLKn0); also elsewhere on the board
/LattePanda Module/SUSCLK_WIFI: R29.2, R33.2; also elsewhere on the board
/LattePanda Module/USB_2_P7+: J16.3 (USB_D+); also elsewhere on the board
/LattePanda Module/USB_2_P7-: J16.5 (USB_D-); also elsewhere on the board
/LattePanda Module/~CLKREQ3: R31.1; also elsewhere on the board
/M.2 E&M Key/CON_PCIE_TX_0+: C55.2, J16.35 (PETp0)
/M.2 E&M Key/CON_PCIE_TX_0-: C56.2, J16.37 (PETn0)
/M.2 E&M Key/CON_PCIE_TX_1+: C49.2, J15.49 (PETp0/SATA-A+)
/M.2 E&M Key/CON_PCIE_TX_1-: C50.2, J15.47 (PETn0/SATA-A-)
/M.2 E&M Key/~CLKREQM: R26.1
/~PLT_RST: J15.50 (~PERST), J16.52 (~PERST0); also elsewhere on the board
/~WAKE: J15.54 (~PEWAKE), J16.55 (~PEWAKE0); also elsewhere on the board
GND: C51.1, C52.1, C53.1, C54.1, C57.1, C58.1, C59.1, C60.1, H7.1, H8.1, J15.1 (GND), J15.3 (GND), J15.9 (GND), J15.15 (GND), J15.21 (GND), J15.27 (GND), J15.33 (GND), J15.39 (GND), J15.45 (GND), J15.51 (GND), J15.57 (GND), J15.71 (GND), J15.73 (GND), J15.75 (GND), J15.MP1, J15.MP2, J16.1 (GND), J16.7 (GND), J16.18 (GND), J16.33 (GND), J16.39 (GND), J16.45 (GND), J16.51 (GND), J16.57 (GND), J16.63 (GND), J16.69 (GND), J16.75 (GND), J16.MP1, J16.MP2, R27.2, R28.2, R32.2; also elsewhere on the board
unnamed: D9.2 (A), R30.1
unnamed: D9.1 (K), J15.10 (DAS/~DSS/~LED1)
unnamed: J15.38 (DEVSLP), TP2.1
unnamed: J15.69 (PEDET), R28.1
unnamed: J15.68 (SUSCLK), R29.1
unnamed: J15.52 (~CLKREQ), R26.2, R27.1
unnamed: J16.50 (SUSCLK), R33.1
unnamed: J16.53 (~CLKREQ0), R31.2, R32.1
unnamed: J16.56 (~W_DISABLE1), R34.1
unnamed: J16.54 (~W_DISABLE2), R35.2

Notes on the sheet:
To be grounded for SATA, No Connect for PCIe
SSD active LED
32.768kHz clock for low power

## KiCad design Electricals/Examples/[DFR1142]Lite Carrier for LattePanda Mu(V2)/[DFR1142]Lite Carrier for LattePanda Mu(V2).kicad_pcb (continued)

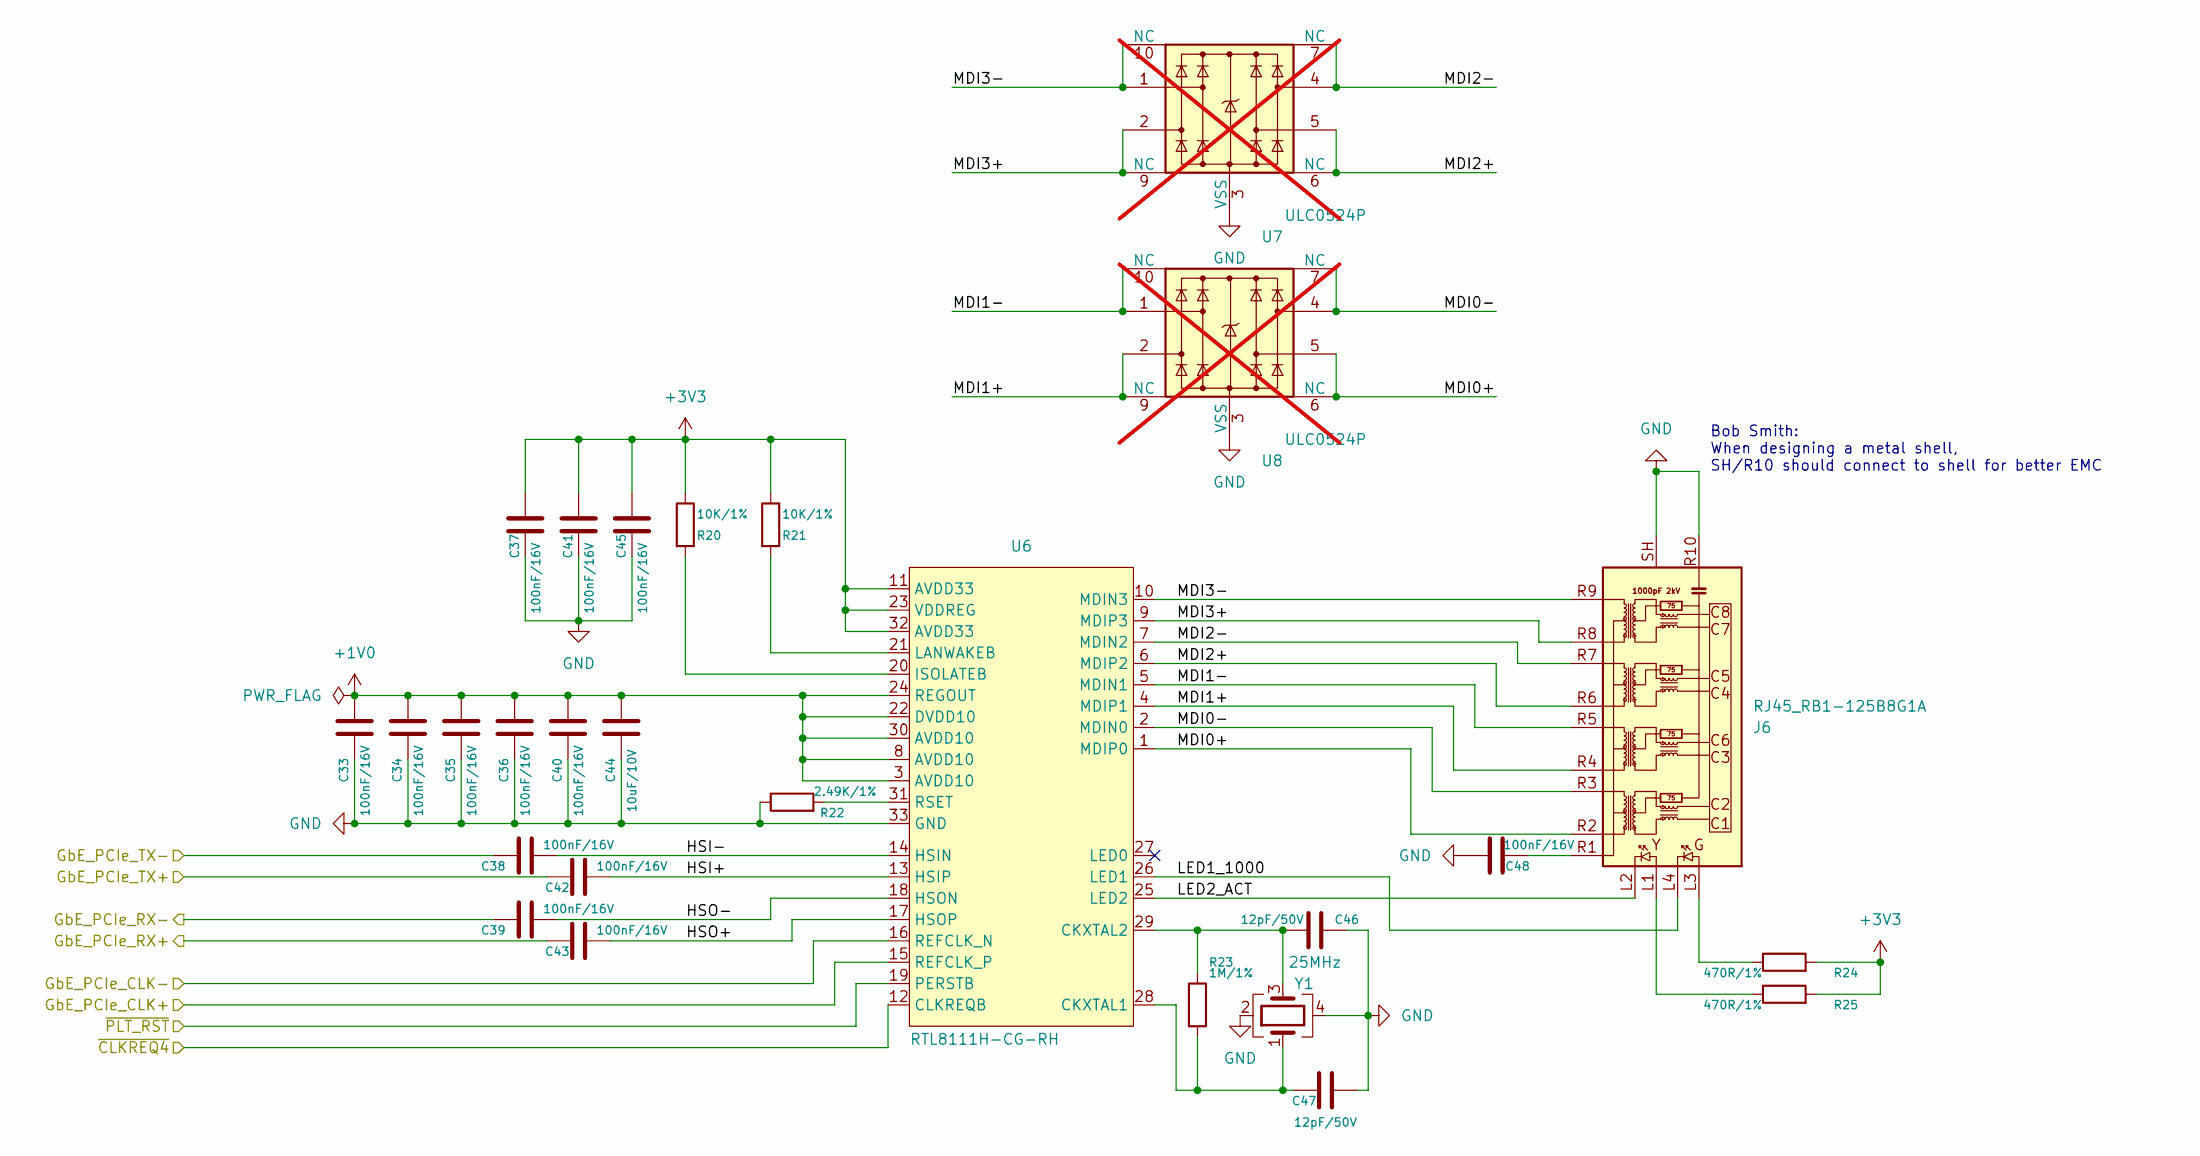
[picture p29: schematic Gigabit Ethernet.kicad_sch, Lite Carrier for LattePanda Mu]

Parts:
C33, C34, C35, C36, C37, C38, C39, C40, C41, C42, C43, C45, C48: 100nF/16V; C_0402_1005Metric
C44: 10uF/10V; C_0402_1005Metric
C46, C47: 12pF/50V; C_0402_1005Metric
J6: RJ45_RB1-125B8G1A; RJ45_UDE_RB1-125B8G1A
R20, R21: 10K/1%; R_0402
R22: 2.49K/1%; R_0603_1608Metric
R23: 1M/1%; R_0402
R24, R25: 470R/1%; R_0402
U6: RTL8111H-CG-RH; QFN-32-1EP_4x4mm_P0.4mm_EP2.65x2.65mm
U7, U8: ULC0524P; Diodes_UDFN-10_1.0x2.5mm_P0.5mm; not fitted
Y1: 25MHz; Crystal_SMD_3225-4Pin_3.2x2.5mm

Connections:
+1V0: C33.2, C34.2, C35.2, C36.2, C40.2, C44.2, U6.3 (AVDD10), U6.8 (AVDD10), U6.22 (DVDD10), U6.24 (REGOUT), U6.30 (AVDD10)
+3V3: C37.2, C41.2, C45.2, R20.1, R21.1, R24.2, R25.2, U6.11 (AVDD33), U6.23 (VDDREG), U6.32 (AVDD33); also elsewhere on the board
/Gigabit Ethernet/GbE_PCIe_CLK+: U6.15 (REFCLK_P); also elsewhere on the board
/Gigabit Ethernet/GbE_PCIe_CLK-: U6.16 (REFCLK_N); also elsewhere on the board
/Gigabit Ethernet/GbE_PCIe_RX+: C43.2; also elsewhere on the board
/Gigabit Ethernet/GbE_PCIe_RX-: C39.2; also elsewhere on the board
/Gigabit Ethernet/GbE_PCIe_TX+: C42.2; also elsewhere on the board
/Gigabit Ethernet/GbE_PCIe_TX-: C38.2; also elsewhere on the board
/Gigabit Ethernet/HSI+: C42.1, U6.13 (HSIP)
/Gigabit Ethernet/HSI-: C38.1, U6.14 (HSIN)
/Gigabit Ethernet/HSO+: C43.1, U6.17 (HSOP)
/Gigabit Ethernet/HSO-: C39.1, U6.18 (HSON)
/Gigabit Ethernet/LED0_100: U6.27 (LED0)
/Gigabit Ethernet/LED1_1000: J6.L4, U6.26 (LED1)
/Gigabit Ethernet/LED2_ACT: J6.L2, U6.25 (LED2)
/Gigabit Ethernet/MDI0+: J6.R2 (TD1+), U6.1 (MDIP0), U8.5, U8.6 (NC)
/Gigabit Ethernet/MDI0-: J6.R3 (TD1-), U6.2 (MDIN0), U8.4, U8.7 (NC)
/Gigabit Ethernet/MDI1+: J6.R4 (TD2+), U6.4 (MDIP1), U8.2, U8.9 (NC)
/Gigabit Ethernet/MDI1-: J6.R5 (TD2-), U6.5 (MDIN1), U8.1, U8.10 (NC)
/Gigabit Ethernet/MDI2+: J6.R6 (TD3+), U6.6 (MDIP2), U7.5, U7.6 (NC)
/Gigabit Ethernet/MDI2-: J6.R7 (TD3-), U6.7 (MDIN2), U7.4, U7.7 (NC)
/Gigabit Ethernet/MDI3+: J6.R8 (TD4+), U6.9 (MDIP3), U7.2, U7.9 (NC)
/Gigabit Ethernet/MDI3-: J6.R9 (TD4-), U6.10 (MDIN3), U7.1, U7.10 (NC)
/Gigabit Ethernet/~CLKREQ4: U6.12 (CLKREQB); also elsewhere on the board
/~PLT_RST: U6.19 (PERSTB); also elsewhere on the board
GND: C33.1, C34.1, C35.1, C36.1, C37.1, C40.1, C41.1, C44.1, C45.1, C46.1, C47.1, C48.2, J6.R10 (GND), J6.SH, R22.1, U6.33 (GND), U7.3 (VSS), U7.8 (VSS), U8.3 (VSS), U8.8 (VSS), Y1.2, Y1.4; also elsewhere on the board
unnamed: C48.1, J6.R1 (CT)
unnamed: J6.L1, R25.1
unnamed: J6.L3, R24.1
unnamed: C47.2, R23.2, U6.28 (CKXTAL1), Y1.1
unnamed: C46.2, R23.1, U6.29 (CKXTAL2), Y1.3
unnamed: R20.2, U6.20 (ISOLATEB)
unnamed: R21.2, U6.21 (LANWAKEB)
unnamed: R22.2, U6.31 (RSET)

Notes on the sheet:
Bob Smith: When designing a metal shell, SH/R10 should connect to shell for better EMC

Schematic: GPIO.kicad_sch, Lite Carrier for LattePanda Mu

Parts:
J7, J9, J12, J13: Conn_01x04_Pin; PinHeader_1x04_P2.54mm_Vertical
J8, J10, J11, J14: Conn_01x03_Pin; PinHeader_1x03_P2.54mm_Vertical
U9, U10, U11, U12: ULC0524P; Diodes_UDFN-10_1.0x2.5mm_P0.5mm

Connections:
+3V3: J13.1, J13.2, J13.3, J13.4, J14.1, J14.2, J14.3; also elsewhere on the board
/GPIO/I2C2_SCL: J9.1, U11.1, U11.10 (NC); also elsewhere on the board
/GPIO/I2C2_SDA: J7.1, U9.1, U9.10 (NC); also elsewhere on the board
/GPIO/I2C3_SCL: J9.2, U11.2, U11.9 (NC); also elsewhere on the board
/GPIO/I2C3_SDA: J7.2, U9.2, U9.9 (NC); also elsewhere on the board
/GPIO/I2C4_SCL: J9.3, U11.4, U11.7 (NC); also elsewhere on the board
/GPIO/I2C4_SDA: J7.3, U9.4, U9.7 (NC); also elsewhere on the board
/GPIO/I2C5_SCL: J9.4, U11.5, U11.6 (NC); also elsewhere on the board
/GPIO/I2C5_SDA: J7.4, U9.5, U9.6 (NC); also elsewhere on the board
/GPIO/SOC_UART0_RX: J8.1, U10.1, U10.10 (NC); also elsewhere on the board
/GPIO/SOC_UART0_TX: J10.1, U12.1, U12.10 (NC); also elsewhere on the board
/GPIO/SOC_UART1_RX: J8.2, U10.2, U10.9 (NC); also elsewhere on the board
/GPIO/SOC_UART1_TX: J10.2, U12.2, U12.9 (NC); also elsewhere on the board
/GPIO/SOC_UART2_RX: J8.3, U10.4, U10.7 (NC); also elsewhere on the board
/GPIO/SOC_UART2_TX: J10.3, U12.4, U12.7 (NC); also elsewhere on the board
GND: J11.1, J11.2, J11.3, J12.1, J12.2, J12.3, J12.4, U9.3 (VSS), U9.8 (VSS), U10.3 (VSS), U10.8 (VSS), U11.3 (VSS), U11.8 (VSS), U12.3 (VSS), U12.8 (VSS); also elsewhere on the board
unnamed: U10.5, U10.6 (NC)
unnamed: U12.5, U12.6 (NC)

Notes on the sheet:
I2C have internal 2.2k resistor pull-up to 3V3 on LattePanda Mu compute module.

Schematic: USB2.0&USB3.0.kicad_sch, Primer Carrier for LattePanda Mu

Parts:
C26, C27, C28, C29: 100nF/16V; C_0402_1005Metric
C30, C31, C32: 22uF/10V; C_0603_1608Metric
D5, D6, D7, D8: 0402ESDA-05N; D_0402_1005Metric
F2, F3: 6V/1A; Fuse_0805_2012Metric
F4, F5: 6V/2A; Fuse_0805_2012Metric
J4: USB3_A_Stacked; USB3_A_Molex_48406-0001_Horizontal_Stacked
J5: USB_A_Stacked; USB_A_CUI_UJ2-ADH-TH_Horizontal_Stacked
U3, U4, U5: ULC0524P; Diodes_UDFN-10_1.0x2.5mm_P0.5mm

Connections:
+5V: C30.2, C31.2, C32.2, F2.1, F3.1, F4.1, F5.1; also elsewhere on the board
/LattePanda Module/HSIO_0_TX+: C27.1; also elsewhere on the board
/LattePanda Module/HSIO_0_TX-: C26.1; also elsewhere on the board
/LattePanda Module/HSIO_1_TX+: C29.1; also elsewhere on the board
/LattePanda Module/HSIO_1_TX-: C28.1; also elsewhere on the board
/USB2.0&USB3.0/CON_USB1_D_N: J5.2 (D1-), U4.2, U4.9 (NC); also elsewhere on the board
/USB2.0&USB3.0/CON_USB1_D_P: J5.3 (D1+), U4.1, U4.10 (NC); also elsewhere on the board
/USB2.0&USB3.0/CON_USB2_D_N: J5.6 (D2-), U4.5, U4.6 (NC); also elsewhere on the board
/USB2.0&USB3.0/CON_USB2_D_P: J5.7 (D2+), U4.4, U4.7 (NC); also elsewhere on the board
/USB2.0&USB3.0/CON_USB3_D_N: D8.2 (A2), J4.2 (D1-); also elsewhere on the board
/USB2.0&USB3.0/CON_USB3_D_P: D7.2 (A2), J4.3 (D1+); also elsewhere on the board
/USB2.0&USB3.0/CON_USB3_SSRX_N: J4.5 (SSRX1-), U5.4, U5.7 (NC); also elsewhere on the board
/USB2.0&USB3.0/CON_USB3_SSRX_P: J4.6 (SSRX1+), U5.5, U5.6 (NC); also elsewhere on the board
/USB2.0&USB3.0/CON_USB3_SSTX_N: C26.2, J4.8 (SSTX1-), U3.4, U3.7 (NC)
/USB2.0&USB3.0/CON_USB3_SSTX_P: C27.2, J4.9 (SSTX1+), U3.5, U3.6 (NC)
/USB2.0&USB3.0/CON_USB4_D_N: D6.2 (A2), J4.11 (D2-); also elsewhere on the board
/USB2.0&USB3.0/CON_USB4_D_P: D5.2 (A2), J4.12 (D2+); also elsewhere on the board
/USB2.0&USB3.0/CON_USB4_SSRX_N: J4.14 (SSRX2-), U5.1, U5.10 (NC); also elsewhere on the board
/USB2.0&USB3.0/CON_USB4_SSRX_P: J4.15 (SSRX2+), U5.2, U5.9 (NC); also elsewhere on the board
/USB2.0&USB3.0/CON_USB4_SSTX_N: C28.2, J4.17 (SSTX2-), U3.1, U3.10 (NC)
/USB2.0&USB3.0/CON_USB4_SSTX_P: C29.2, J4.18 (SSTX2+), U3.2, U3.9 (NC)
GND: C30.1, C31.1, C32.1, D5.1 (A1), D6.1 (A1), D7.1 (A1), D8.1 (A1), J4.4 (GND1), J4.7 (DRAIN1), J4.13 (GND2), J4.16 (DRAIN2), J4.19 (SHIELD), J5.4 (GND1), J5.8 (GND2), J5.9 (Shield), U3.3 (VSS), U3.8 (VSS), U4.3 (VSS), U4.8 (VSS), U5.3 (VSS), U5.8 (VSS); also elsewhere on the board
unnamed: F4.2, J4.1 (VBUS1)
unnamed: F5.2, J4.10 (VBUS2)
unnamed: F2.2, J5.1 (VBUS1)
unnamed: F3.2, J5.5 (VBUS2)

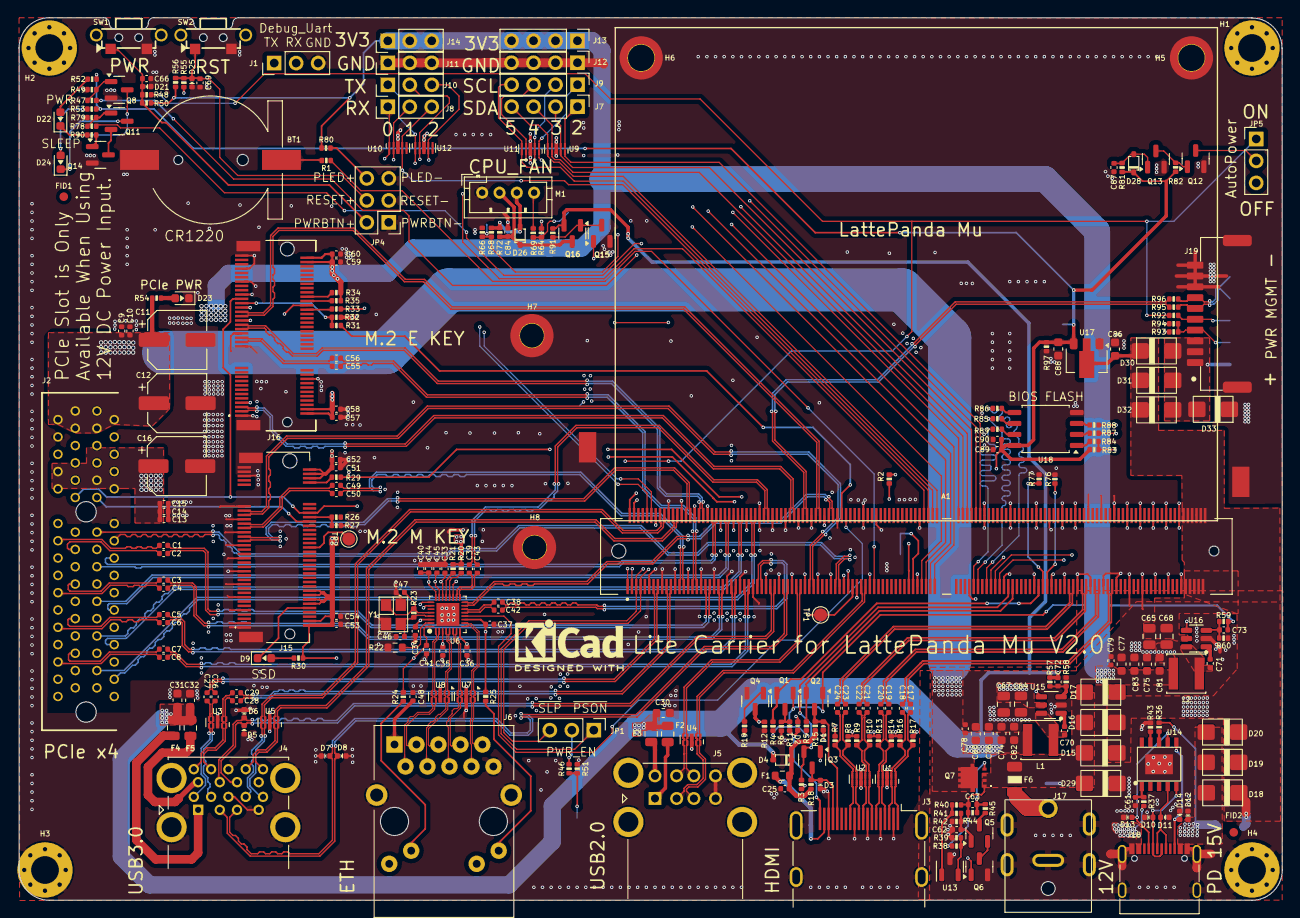
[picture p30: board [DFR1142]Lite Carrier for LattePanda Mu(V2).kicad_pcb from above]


Board: 4 copper layers, 146.0 x 102.0 mm, 304 parts (17 on the bottom side), 235 nets.

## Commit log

2024-04-27 update pinouts
    [back.csv, front.csv]
2024-04-29 fix clkreq numbering error
    [LattePanda Module.kicad_sch]
2024-05-11 upload heatsink model
2024-08-05 Additional Pin Descriptions
    [back.csv, front.csv]
2024-08-05 fix format
    [front.csv]
2024-08-19 upload dimension drawing
    [LattePanda_Mu_Dimension_Drawing.dxf]
2024-09-25 Fix typo in pinout doc
    NOTE: GPD5 is supposed to be SLS_S4# & not SLS_S3# (which is GPD4 according to the datasheet) - left it as is, but may be worth a review.
    [front.csv]
2026-01-14 update edge connector pinout
    [LattePanda_Mu_Edge_Connector_Pinout.xlsx, back.csv, front.csv]
2026-02-10 add kicad project of dfr1142 v2
    [GPIO.kicad_sch, Gigabit Ethernet.kicad_sch, HDMI.kicad_sch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]
2026-06-03 Add DFR1144 GPU Carrier for LattePnada Mu
    [GPIO.kicad_sch, Gigabit Ethernet.kicad_sch, HDMI+DPA.kicad_sch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]
2026-06-09 add BIOS(supports I2C/GPIO in Windows)
2026-06-10 Optimize files
    [[DFR1144][M027.00940](V1.0.0).xlsx]
2026-07-02 Update the README.md content to add a brief introduction to the DFR1144 GPU carrier board. Add footprint library files for the DFR1142 Lite Carrier V2. Add footprint library files for the DFR1144 GPU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
    [[DFR1142]Lite Carrier for LattePanda Mu(V2).kicad_pcb, [DFR1144][M027.00940](V1.0.0).kicad_pcb]
2026-09-01 add carrier, bios, sym, readme
    [LattePanda_Mu_Edge_Connector_Pinout.xlsx]
